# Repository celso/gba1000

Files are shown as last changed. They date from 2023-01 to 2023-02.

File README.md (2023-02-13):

# Amiga GBA1000 Project

The GB A1000 is a motherboard based on the Amiga 1000. The project was developed by Georg Braun and has the following features (Rev 4):

* CPU: Motorola MC68030 at 40 or 50 MHz
* FPU: Motorola MC68881 or MC68882 at CPU-speed
* RAM: 8 Mbyte 32-bit SRAM, 2 Mbyte ChipRAM
* Chipset: ECS Amiga (ECS-Denise 8373 and Fat Agnus 8372/8375)
* Built-in flicker-fixer with VGA-output
* One Zorro-II slot
* 1 Mbyte Flash-ROM for optional software
* Real-time clock with battery backup
* IDE-controller
* Two Kickstart-sockets
* Fits directly into an original Amiga 1000 case

We only have info and files for Rev 4.

Rev 5 adds a 68040 / 68060 CPU at 50MHz but there are no public schematics for it.

I will attempt to build a GBA1000 this year, this repo will host all the information and research work needed.

## PCB

* [Amiga EagleCAD library](https://gitlab.com/MHeinrichs/Amiga-EagleCAD-library)

## Parts

* [Parts list](https://docs.google.com/spreadsheets/d/1qbaFgtlkgim4g9IzhCKldIigHErPgWEHpMMWoZS-UCM/edit?usp=sharing) (spreadsheet)
* [Parts list (another version)](https://docs.google.com/spreadsheets/d/1GhOfJKkPUn_pJ6D0nmGipUzV8q_jXX78GFDTTUAWveM/edit?usp=sharing) (spreadsheet)

## Photos

* [Illuwatar's photos](https://photos.app.goo.gl/Ms466hcZpjMAoojf7)

## Videos

* [GBA1000 board build](https://www.youtube.com/watch?v=4canKrEQRAU) with great soldering tips

## Sections

* [FAQ](FAQ.md) from the old gba1000.info website.
* [Schematics](schematics/)
* [Assembly Drawings](assembly-drawings/)
* [Rev0 Instructions and BOM](instructions-rev0/)
* [Rev4 Eagle files](eagle-rev4/)
* [Hardware configuration files](logic/)

### Main threads

* [GBA1000 rev4 Build Log](https://www.amibay.com/threads/gba1000-rev4-build-log.46916/)
* [Project of a mini tylacine PCBs batch for the GBA1000](https://www.amibay.com/threads/project-of-a-mini-tylacine-pcbs-batch-for-the-gba1000.63034/)

### Relevant links

* [Rev4 PCB locator AmigaWiki](http://www.amigawiki.org/loc7/locator7.php)
* [Illuwatar's  A1000 build project](http://www.illuwatar.se/project_pages/gba1000/gba1000.htm)
* [GBA1000 v4 build in French](http://obligement.free.fr/articles/gba1000v4.php)
* [www.gba1000.info (archived)](https://web.archive.org/web/20090430084403/http://www.gba1000.info/disclaimer.asp?returnpage=partslist.asp)
* [GBA1000 Jumpers](http://www.amigawiki.de/lib/exe/fetch.php?media=de:models:gba1000_jumper.pdf)

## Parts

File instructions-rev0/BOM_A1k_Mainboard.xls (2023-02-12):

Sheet: A1k_Mainboard
EAGLE | Version 3.55r3 | 1988-1999 | CadSoft
Partliste
Part | Value | Package | Library | Distributor | Best.-Nr. | Preis Euro
BAT1 | LI-3V6 | LI-3V6 | BATTERY | elpro - Elektronik | LS 14250 Drahtanschluss | 4.87
C1 | 47uF | 7243 | SMD | elpro - Elektronik | T-SMD 20V 47uF BF:D | 0.34
C2 | 47uF | 7243 | SMD | elpro - Elektronik | T-SMD 20V 47uF BF:D | 0.34
C3 | 100nF | 1206 | SMD | elpro - Elektronik | K-SMD 0,1uF 1206 | 0.11
C4 | 100nF | 1206 | SMD | elpro - Elektronik | K-SMD 0,1uF 1206 | 0.11
C5 | 100nF | 1206 | SMD | elpro - Elektronik | K-SMD 0,1uF 1206 | 0.11
C6 | 100nF | 1206 | SMD | elpro - Elektronik | K-SMD 0,1uF 1206 | 0.11
C7 | 100nF | 1206 | SMD | elpro - Elektronik | K-SMD 0,1uF 1206 | 0.11
C8 | 100nF | 1206 | SMD | elpro - Elektronik | K-SMD 0,1uF 1206 | 0.11
C9 | 100nF | 1206 | SMD | elpro - Elektronik | K-SMD 0,1uF 1206 | 0.11
C10 | 100nF | 1206 | SMD | elpro - Elektronik | K-SMD 0,1uF 1206 | 0.11
C11 | 100nF | 1206 | SMD | elpro - Elektronik | K-SMD 0,1uF 1206 | 0.11
C12 | 100nF | 1206 | SMD | elpro - Elektronik | K-SMD 0,1uF 1206 | 0.11
C13 | 100nF | 1206 | SMD | elpro - Elektronik | K-SMD 0,1uF 1206 | 0.11
C14 | 100nF | 1206 | SMD | elpro - Elektronik | K-SMD 0,1uF 1206 | 0.11
C15 | 100nF | 1206 | SMD | elpro - Elektronik | K-SMD 0,1uF 1206 | 0.11
C16 | 100nF | 1206 | SMD | elpro - Elektronik | K-SMD 0,1uF 1206 | 0.11
C17 | 100nF | 1206 | SMD | elpro - Elektronik | K-SMD 0,1uF 1206 | 0.11
C18 | 100uF | 7243 | SMD | elpro - Elektronik | T-SMD 16V 100uF BF:D | 0.22
C19 | 47uF | 7243 | SMD | elpro - Elektronik | T-SMD 20V 47uF BF:D | 0.34
C20 | 100uF | 7243 | SMD | elpro - Elektronik | T-SMD 16V 100uF BF:D | 0.22
C21 | 100nF | 1206 | SMD | elpro - Elektronik | K-SMD 0,1uF 1206 | 0.11
C22 | 100nF | 1206 | SMD | elpro - Elektronik | K-SMD 0,1uF 1206 | 0.11
C23 | 100nF | 1206 | SMD | elpro - Elektronik | K-SMD 0,1uF 1206 | 0.11
C24 | 100nF | 1206 | SMD | elpro - Elektronik | K-SMD 0,1uF 1206 | 0.11
C25 | 100nF | 1206 | SMD | elpro - Elektronik | K-SMD 0,1uF 1206 | 0.11
C26 | 100nF | 1206 | SMD | elpro - Elektronik | K-SMD 0,1uF 1206 | 0.11
C27 | 100nF | 1206 | SMD | elpro - Elektronik | K-SMD 0,1uF 1206 | 0.11
C28 | 100nF | 1206 | SMD | elpro - Elektronik | K-SMD 0,1uF 1206 | 0.11
C29 | 100nF | 1206 | SMD | elpro - Elektronik | K-SMD 0,1uF 1206 | 0.11
C30 | 100nF | 1206 | SMD | elpro - Elektronik | K-SMD 0,1uF 1206 | 0.11
C31 | 100nF | 1206 | SMD | elpro - Elektronik | K-SMD 0,1uF 1206 | 0.11
C32 | 100nF | 1206 | SMD | elpro - Elektronik | K-SMD 0,1uF 1206 | 0.11
C33 | 100nF | 1206 | SMD | elpro - Elektronik | K-SMD 0,1uF 1206 | 0.11
C34 | 100nF | 1206 | SMD | elpro - Elektronik | K-SMD 0,1uF 1206 | 0.11
C35 | 100nF | 1206 | SMD | elpro - Elektronik | K-SMD 0,1uF 1206 | 0.11
C36 | 100pF | 1206 | SMD | elpro - Elektronik | K-SMD 100 pF 1206 | 0.11
C37 | 100pF | 1206 | SMD | elpro - Elektronik | K-SMD 100 pF 1206 | 0.11
C38 | 100pF | 1206 | SMD | elpro - Elektronik | K-SMD 100 pF 1206 | 0.11
C39 | 100pF | 1206 | SMD | elpro - Elektronik | K-SMD 100 pF 1206 | 0.11
C40 | 100pF | 1206 | SMD | elpro - Elektronik | K-SMD 100 pF 1206 | 0.11
C41 | 100pF | 1206 | SMD | elpro - Elektronik | K-SMD 100 pF 1206 | 0.11
C42 | 220uF | 7243 | SMD | elpro - Elektronik | T-SMD 6,3V 220uF BF:D | 0.45
C43 | 220uF | 7243 | SMD | elpro - Elektronik | T-SMD 6,3V 220uF BF:D | 0.45
C44 | 1uF | 1206 | SMD | elpro - Elektronik | K-SMD 1uF 1206 | 0.12
C45 | 220uF | 7243 | SMD | elpro - Elektronik | T-SMD 6,3V 220uF BF:D | 0.45
C46 | 220uF | 7243 | SMD | elpro - Elektronik | T-SMD 6,3V 220uF BF:D | 0.45
C47 | 1uF | 1206 | SMD | elpro - Elektronik | K-SMD 1uF 1206 | 0.12
C48 | 1nF | 1206 | SMD | elpro - Elektronik | K-SMD 1000 pF 1206 | 0.11
C49 | 1nF | 1206 | SMD | elpro - Elektronik | K-SMD 1000 pF 1206 | 0.11
C50 | 100nF | 1206 | SMD | elpro - Elektronik | K-SMD 0,1uF 1206 | 0.11
C51 | 39pF | 1206 | SMD | elpro - Elektronik | K-SMD 39 pF 1206 | 0.11
C52 | 100nF | 1206 | SMD | elpro - Elektronik | K-SMD 0,1uF 1206 | 0.11
C53 | 100nF | 1206 | SMD | elpro - Elektronik | K-SMD 0,1uF 1206 | 0.11
C54 | 100nF | 1206 | SMD | elpro - Elektronik | K-SMD 0,1uF 1206 | 0.11
C55 | 10uF | 7243 | SMD | elpro - Elektronik | T-SMD 25V 10uF BF:D | 0.24
C56 | 100pF | 1206 | SMD | elpro - Elektronik | K-SMD 100 pF 1206 | 0.11
C57 | 100pF | 1206 | SMD | elpro - Elektronik | K-SMD 100 pF 1206 | 0.11
C58 | 100pF | 1206 | SMD | elpro - Elektronik | K-SMD 100 pF 1206 | 0.11
C59 | 1-5pF | C-TRIM-1 | RCD | elpro - Elektronik | 808-1 1,4-5,5 pF | 0.36
C60 | 100nF | 1206 | SMD | elpro - Elektronik | K-SMD 0,1uF 1206 | 0.11
C61 | 100nF | 1206 | SMD | elpro - Elektronik | K-SMD 0,1uF 1206 | 0.11
C62 | 100nF | 1206 | SMD | elpro - Elektronik | K-SMD 0,1uF 1206 | 0.11
C63 | 100nF | 1206 | SMD | elpro - Elektronik | K-SMD 0,1uF 1206 | 0.11
C64 | 100nF | 1206 | SMD | elpro - Elektronik | K-SMD 0,1uF 1206 | 0.11
C65 | 100nF | 1206 | SMD | elpro - Elektronik | K-SMD 0,1uF 1206 | 0.11
C66 | 100nF | 1206 | SMD | elpro - Elektronik | K-SMD 0,1uF 1206 | 0.11
C67 | 100nF | 1206 | SMD | elpro - Elektronik | K-SMD 0,1uF 1206 | 0.11
C68 | 100nF | 1206 | SMD | elpro - Elektronik | K-SMD 0,1uF 1206 | 0.11
C69 | 100nF | 1206 | SMD | elpro - Elektronik | K-SMD 0,1uF 1206 | 0.11
C70 | 100nF | 1206 | SMD | elpro - Elektronik | K-SMD 0,1uF 1206 | 0.11
C71 | 100nF | 1206 | SMD | elpro - Elektronik | K-SMD 0,1uF 1206 | 0.11
C72 | 100nF | 1206 | SMD | elpro - Elektronik | K-SMD 0,1uF 1206 | 0.11
C73 | 100nF | 1206 | SMD | elpro - Elektronik | K-SMD 0,1uF 1206 | 0.11
C74 | 47uF | 7243 | SMD | elpro - Elektronik | T-SMD 20V 47uF BF:D | 0.34
C75 | 7,5pF | 1206 | SMD | elpro - Elektronik | K-SMD 8,2 pF 1206 | 0.11
C76 | 47uF | 7243 | SMD | elpro - Elektronik | T-SMD 20V 47uF BF:D | 0.34
C77 | 10uF | 7243 | SMD | elpro - Elektronik | T-SMD 25V 10uF BF:D | 0.24
C78 | 100nF | 1206 | SMD | elpro - Elektronik | K-SMD 0,1uF 1206 | 0.11
C79 | 20pF | 1206 | SMD | elpro - Elektronik | K-SMD 22 pF 1206 | 0.11
C80 | 5-40pF | C-TRIM-1 | RCD | elpro - Elektronik | 808-1 3-40 pF | 0.40
C81 | 6,8nF | 1206 | SMD | elpro - Elektronik | K-SMD 6800 pF 1206 | 0.11
C82 | 3,9nF | 1206 | SMD | elpro - Elektronik | K-SMD 3900 pF 1206 | 0.11
C83 | 10uF | 1812 | SMD | Mira-Electronic | 8261/106 | 1.12 | Segor 22u-1210-X5R/10V
C84 | 100nF | 1206 | SMD | elpro - Elektronik | K-SMD 0,1uF 1206 | 0.11
C85 | 6,8nF | 1206 | SMD | elpro - Elektronik | K-SMD 6800 pF 1206 | 0.11
C86 | 10uF | 1812 | SMD | Mira-Electronic | 8261/106 | 1.12 | Segor 22u-1210-X5R/10V
C87 | 3,9nF | 1206 | SMD | elpro - Elektronik | K-SMD 3900 pF 1206 | 0.11
C88 | 100nF | 1206 | SMD | elpro - Elektronik | K-SMD 0,1uF 1206 | 0.11
C89 | 10uF | 7243 | SMD | elpro - Elektronik | T-SMD 25V 10uF BF:D | 0.24
C90 | 47nF | 1206 | SMD | elpro - Elektronik | K-SMD 0,047uF 1206 | 0.11
C91 | 47nF | 1206 | SMD | elpro - Elektronik | K-SMD 0,047uF 1206 | 0.11
C92 | 47nF | 1206 | SMD | elpro - Elektronik | K-SMD 0,047uF 1206 | 0.11
C93 | 47nF | 1206 | SMD | elpro - Elektronik | K-SMD 0,047uF 1206 | 0.11
C94 | 22uF | 7243 | SMD | elpro - Elektronik | T-SMD 25V 22uF BF:D | 0.30
C95 | 22uF | 7243 | SMD | elpro - Elektronik | T-SMD 25V 22uF BF:D | 0.30
C96 | 100nF | 1206 | SMD | elpro - Elektronik | K-SMD 0,1uF 1206 | 0.11
C97 | 100nF | 1206 | SMD | elpro - Elektronik | K-SMD 0,1uF 1206 | 0.11
C98 | 10nF | 1206 | SMD | elpro - Elektronik | K-SMD 0,01uF 1206 | 0.11
C99 | 100nF | 1206 | SMD | elpro - Elektronik | K-SMD 0,1uF 1206 | 0.11
C100 | 100pF | 1206 | SMD | elpro - Elektronik | K-SMD 100 pF 1206 | 0.11
C101 | 100pF | 1206 | SMD | elpro - Elektronik | K-SMD 100 pF 1206 | 0.11
C102 | 100pF | 1206 | SMD | elpro - Elektronik | K-SMD 100 pF 1206 | 0.11
C103 | 100nF | 1206 | SMD | elpro - Elektronik | K-SMD 0,1uF 1206 | 0.11
C104 | 10uF | 7243 | SMD | elpro - Elektronik | T-SMD 25V 10uF BF:D | 0.24
C105 | 10uF | 7243 | SMD | elpro - Elektronik | T-SMD 25V 10uF BF:D | 0.24
C106 | 100nF | 1206 | SMD | elpro - Elektronik | K-SMD 0,1uF 1206 | 0.11
C107 | 100nF | 1206 | SMD | elpro - Elektronik | K-SMD 0,1uF 1206 | 0.11
C108 | 100nF | 1206 | SMD | elpro - Elektronik | K-SMD 0,1uF 1206 | 0.11
C109 | 100nF | 1206 | SMD | elpro - Elektronik | K-SMD 0,1uF 1206 | 0.11
C110 | 100nF | 1206 | SMD | elpro - Elektronik | K-SMD 0,1uF 1206 | 0.11
C111 | 100nF | 1206 | SMD | elpro - Elektronik | K-SMD 0,1uF 1206 | 0.11
C112 | 100nF | 1206 | SMD | elpro - Elektronik | K-SMD 0,1uF 1206 | 0.11
C113 | 47uF | 7243 | SMD | elpro - Elektronik | T-SMD 20V 47uF BF:D | 0.34
C114 | 47uF | 7243 | SMD | elpro - Elektronik | T-SMD 20V 47uF BF:D | 0.34
C115 | 100nF | 1206 | SMD | elpro - Elektronik | K-SMD 0,1uF 1206 | 0.11
C116 | 100nF | 1206 | SMD | elpro - Elektronik | K-SMD 0,1uF 1206 | 0.11
C117 | 100nF | 1206 | SMD | elpro - Elektronik | K-SMD 0,1uF 1206 | 0.11
C118 | 100nF | 1206 | SMD | elpro - Elektronik | K-SMD 0,1uF 1206 | 0.11
C119 | 100nF | 1206 | SMD | elpro - Elektronik | K-SMD 0,1uF 1206 | 0.11
C120 | 100nF | 1206 | SMD | elpro - Elektronik | K-SMD 0,1uF 1206 | 0.11
C121 | 100nF | 1206 | SMD | elpro - Elektronik | K-SMD 0,1uF 1206 | 0.11
C122 | 100nF | 1206 | SMD | elpro - Elektronik | K-SMD 0,1uF 1206 | 0.11
C123 | 100nF | 1206 | SMD | elpro - Elektronik | K-SMD 0,1uF 1206 | 0.11
C124 | 47uF | 7243 | SMD | elpro - Elektronik | T-SMD 20V 47uF BF:D | 0.34
C125 | 100nF | 1206 | SMD | elpro - Elektronik | K-SMD 0,1uF 1206 | 0.11
C126 | 100nF | 1206 | SMD | elpro - Elektronik | K-SMD 0,1uF 1206 | 0.11
C127 | 100nF | 1206 | SMD | elpro - Elektronik | K-SMD 0,1uF 1206 | 0.11
C128 | 100nF | 1206 | SMD | elpro - Elektronik | K-SMD 0,1uF 1206 | 0.11
C129 | 47uF | 7243 | SMD | elpro - Elektronik | T-SMD 20V 47uF BF:D | 0.34
C130 | 100nF | 1206 | SMD | elpro - Elektronik | K-SMD 0,1uF 1206 | 0.11
C131 | 100nF | 1206 | SMD | elpro - Elektronik | K-SMD 0,1uF 1206 | 0.11
C132 | 100nF | 1206 | SMD | elpro - Elektronik | K-SMD 0,1uF 1206 | 0.11
C133 | 100nF | 1206 | SMD | elpro - Elektronik | K-SMD 0,1uF 1206 | 0.11
C134 | 100nF | 1206 | SMD | elpro - Elektronik | K-SMD 0,1uF 1206 | 0.11
C135 | 100nF | 1206 | SMD | elpro - Elektronik | K-SMD 0,1uF 1206 | 0.11
C136 | 100nF | 1206 | SMD | elpro - Elektronik | K-SMD 0,1uF 1206 | 0.11
C137 | 100nF | 1206 | SMD | elpro - Elektronik | K-SMD 0,1uF 1206 | 0.11
C138 | 100nF | 1206 | SMD | elpro - Elektronik | K-SMD 0,1uF 1206 | 0.11
C139 | 100nF | 1206 | SMD | elpro - Elektronik | K-SMD 0,1uF 1206 | 0.11
C140 | 100nF | 1206 | SMD | elpro - Elektronik | K-SMD 0,1uF 1206 | 0.11
C141 | 100nF | 1206 | SMD | elpro - Elektronik | K-SMD 0,1uF 1206 | 0.11
C142 | 100nF | 1206 | SMD | elpro - Elektronik | K-SMD 0,1uF 1206 | 0.11
C143 | 100nF | 1206 | SMD | elpro - Elektronik | K-SMD 0,1uF 1206 | 0.11
C144 | 100nF | 1206 | SMD | elpro - Elektronik | K-SMD 0,1uF 1206 | 0.11
C145 | 100nF | 1206 | SMD | elpro - Elektronik | K-SMD 0,1uF 1206 | 0.11
C146 | 100nF | 1206 | SMD | elpro - Elektronik | K-SMD 0,1uF 1206 | 0.11
C147 | 100nF | 1206 | SMD | elpro - Elektronik | K-SMD 0,1uF 1206 | 0.11
C148 | 100nF | 1206 | SMD | elpro - Elektronik | K-SMD 0,1uF 1206 | 0.11
C149 | 100nF | 1206 | SMD | elpro - Elektronik | K-SMD 0,1uF 1206 | 0.11
C150 | 100nF | 1206 | SMD | elpro - Elektronik | K-SMD 0,1uF 1206 | 0.11
C151 | 100nF | 1206 | SMD | elpro - Elektronik | K-SMD 0,1uF 1206 | 0.11
C152 | 100nF | 1206 | SMD | elpro - Elektronik | K-SMD 0,1uF 1206 | 0.11
C153 | 100nF | 1206 | SMD | elpro - Elektronik | K-SMD 0,1uF 1206 | 0.11
C154 | 100nF | 1206 | SMD | elpro - Elektronik | K-SMD 0,1uF 1206 | 0.11
C155 | 100nF | 1206 | SMD | elpro - Elektronik | K-SMD 0,1uF 1206 | 0.11
C156 | 100nF | 1206 | SMD | elpro - Elektronik | K-SMD 0,1uF 1206 | 0.11
C157 | 100nF | 1206 | SMD | elpro - Elektronik | K-SMD 0,1uF 1206 | 0.11
C158 | 100nF | 1206 | SMD | elpro - Elektronik | K-SMD 0,1uF 1206 | 0.11
C159 | 100nF | 1206 | SMD | elpro - Elektronik | K-SMD 0,1uF 1206 | 0.11
C160 | 100nF | 1206 | SMD | elpro - Elektronik | K-SMD 0,1uF 1206 | 0.11
C161 | 47uF | 7243 | SMD | elpro - Elektronik | T-SMD 20V 47uF BF:D | 0.34
C162 | 47uF | 7243 | SMD | elpro - Elektronik | T-SMD 20V 47uF BF:D | 0.34
C163 | 47uF | 7243 | SMD | elpro - Elektronik | T-SMD 20V 47uF BF:D | 0.34
C164 | 4,7uF | 3528 | SMD | elpro - Elektronik | T-SMD 16V 4,7uF BF:B | 0.15
D1 | BAS32L | SOD-80 | SMD | elpro - Elektronik | BAS32 L SMD | 0.09
D2 | BAS32L | SOD-80 | SMD | elpro - Elektronik | BAS32 L SMD | 0.09
D3 | BAS32L | SOD-80 | SMD | elpro - Elektronik | BAS32 L SMD | 0.09
IC1 | 74HC573 | DIP20 | DIL-IC | elpro - Elektronik | 74 HC 573 | 0.15
IC2 | 74HC573 | DIP20 | DIL-IC | elpro - Elektronik | 74 HC 573 | 0.15
IC3 | 74HC541 | DIP20 | DIL-IC | elpro - Elektronik | 74 HC 541 | 0.19
IC4 | 74HC541 | DIP20 | DIL-IC | elpro - Elektronik | 74 HC 541 | 0.19
IC5 | 74HC541 | DIP20 | DIL-IC | elpro - Elektronik | 74 HC 541 | 0.19
IC6 | 74HC541 | DIP20 | DIL-IC | elpro - Elektronik | 74 HC 541 | 0.19
IC7 | 514400 | SOJ26/20 | SMD-IC | Kessler electronic | 514400-60SOJ | 4.98
IC8 | 514400 | SOJ26/20 | SMD-IC | Kessler electronic | 514400-60SOJ | 4.98
IC9 | 514400 | SOJ26/20 | SMD-IC | Kessler electronic | 514400-60SOJ | 4.98
IC10 | 514400 | SOJ26/20 | SMD-IC | Kessler electronic | 514400-60SOJ | 4.98
IC11 | 28,3751 MHz | Oszillator | DIL-IC | Amiga-Hardware |  | 0.00
IC12 | 27C400 | DIP40-6 | DIL-IC | Kickstart-ROM |  | 0.00
IC13 | 27C4096 | DIP40-6 | DIL-IC | n.b. |  | 0.00
IC14 | GAL16V8-15 | DIP20 | DIL-IC | elpro - Elektronik | GAL 16 V 8 D-15 LP | 0.70
IC15 | 74LS373 | DIP20 | DIL-IC | Reichelt - Elektronik | 74LS 373 | 0.22
IC16 | 74F521 | DIP20 | DIL-IC | Reichelt - Elektronik | 74F 521 | 0.40
IC17 | 74LS245 | DIP20 | DIL-IC | Reichelt - Elektronik | 74LS 245 | 0.20
IC18 | GAL16V8-15 | DIP20 | DIL-IC | elpro - Elektronik | GAL 16 V 8 D-15 LP | 0.70
IC19 | GAL16V8-25 | DIP20 | DIL-IC | elpro - Elektronik | GAL 16 V 8 D-25 LP | 0.70
IC20 | AMBER | PLCC68 | DIL-IC | Amiga-Hardware |  | 0.00
IC21 | VIDEO_H | SIP22 | DIL-IC | Amiga-Hardware |  | 0.00
IC22 | 74HC157 | DIP16 | DIL-IC | Reichelt - Elektronik | 74HC 157 | 0.15
IC23 | 74HC245 | DIP20 | DIL-IC | Reichelt - Elektronik | 74HC 245 | 0.20
IC24 | 74HC245 | DIP20 | DIL-IC | Reichelt - Elektronik | 74HC 245 | 0.20
IC25 | VIDEO_H | SIP22 | DIL-IC | Amiga-Hardware |  | 0.00
IC26 | DENISE | DIP48-6 | DIL-IC | Amiga-Hardware |  | 0.00
IC27 | NE564 | DIP16 | DIL-IC | Reichelt - Elektronik | NE 564 DIL | 1.50
IC28 | 74HC04 | DIP14 | 74XXSMD | Reichelt - Elektronik | 74HC 04 | 0.12
IC29 | 74F163 | DIP16 | 74XX | Kessler electronic | 74F163 | 0.84
IC30 | 74F74 | DIP14 | 74XX | Reichelt - Elektronik | 74F 74 | 0.31
IC31 | GAL16V8-25 | DIP20 | DIL-IC | elpro - Elektronik | GAL 16 V 8 D-25 LP | 0.70
IC32 | GAL16V8-25 | DIP20 | DIL-IC | elpro - Elektronik | GAL 16 V 8 D-25 LP | 0.70
IC33 | GAL16V8-15 | DIP20 | DIL-IC | elpro - Elektronik | GAL 16 V 8 D-15 LP | 0.70
IC34 | 27C256 | DIP28-6 | DIL-IC | Reichelt - Elektronik | 27C256-70 | 2.05
IC35 | 74LS245 | DIP20 | DIL-IC | Reichelt - Elektronik | 74LS 245 | 0.20
IC36 | 74LS245 | DIP20 | DIL-IC | Reichelt - Elektronik | 74LS 245 | 0.20
IC37 | MC68030RC | PGA-128 | M68000 | eBay |  | 20.00
IC38 | MC68881RC | PGA-68 | M68000 | eBay |  | 20.00
IC39 | MSM6242 | DIP18 | DIL-IC | Amiga-Hardware |  | 0.00
IC40 | CIA_8520 | DIP40-6 | DIL-IC | Amiga-Hardware |  | 0.00
IC41 | PAULA | DIP48-6 | DIL-IC | Amiga-Hardware |  | 0.00
IC42 | TL084 | DIP14 | DIL-IC | Reichelt - Elektronik | TL 074 DIL | 0.15
IC43 | CIA_8520 | DIP40-6 | DIL-IC | Amiga-Hardware |  | 0.00
IC44 | DS1488 | DIP14 | DIL-IC | Kessler electronic | MC1488 | 0.25
IC45 | DS1489 | DIP14 | DIL-IC | Kessler electronic | MC1489 | 0.19
IC46 | 74HC32 | DIP14 | DIL-IC | Reichelt - Elektronik | 74HC 32 | 0.15
IC47 | 7406 | DIP14 | DIL-IC | Reichelt - Elektronik | 74LS 06 | 0.39
IC48 | LM339 | DIP14 | DIL-IC | Reichelt - Elektronik | LM 339 DIL | 0.10
IC49 | 7407 | DIP14 | DIL-IC | Reichelt - Elektronik | 74LS 07 | 0.17
IC50 | GARY | DIP48-6 | DIL-IC | Amiga-Hardware |  | 0.00
IC51 | 74F04 | DIP14 | DIL-IC | Reichelt - Elektronik | 74F 04 | 0.22
IC52 | AGNUS | PLCC84 | DIL-IC | Amiga-Hardware |  | 0.00
IC53 | GAL20V8-15 | DIP24-3 | DIL-IC | elpro - Elektronik | GAL 20 V 8 B-15 LP | 0.93
IC54 | GAL20V8-15 | DIP24-3 | DIL-IC | elpro - Elektronik | GAL 20 V 8 B-15 LP | 0.93
IC55 | GAL20V8-15 | DIP24-3 | DIL-IC | elpro - Elektronik | GAL 20 V 8 B-15 LP | 0.93
IC56 | GAL20V8-15 | DIP24-3 | DIL-IC | elpro - Elektronik | GAL 20 V 8 B-15 LP | 0.93
IC57 | LSI1024 | PLCC68 | DIL-IC | elpro - Elektronik | ISPLSI 1024-60 LJ PLCC | 10.85
IC58 | 74F245 | SO20L | 74XXSMD | elpro - Elektronik | 74 F 245 SMD | 0.40
IC59 | 74F245 | SO20L | 74XXSMD | elpro - Elektronik | 74 F 245 SMD | 0.40
IC60 | 29F800 | TSOP48 | SMD-IC | RS Components GmbH | 414-9597 | 11.80
IC61 | 48 MHz | Oszillator | DIL-IC | Conrad Elektronik | 158240 | 5.22
IC62 | CY7C1049 | SOJ36/4 | SMD-IC | Kessler electronic | 614008-10J | 3.80
IC63 | CY7C1049 | SOJ36/4 | SMD-IC | Kessler electronic | 614008-10J | 3.80
IC64 | CY7C1049 | SOJ36/4 | SMD-IC | Kessler electronic | 614008-10J | 3.80
IC65 | CY7C1049 | SOJ36/4 | SMD-IC | Kessler electronic | 614008-10J | 3.80
IC66 | CY7C1049 | SOJ36/4 | SMD-IC | Kessler electronic | 614008-10J | 3.80
IC67 | CY7C1049 | SOJ36/4 | SMD-IC | Kessler electronic | 614008-10J | 3.80
IC68 | CY7C1049 | SOJ36/4 | SMD-IC | Kessler electronic | 614008-10J | 3.80
IC69 | CY7C1049 | SOJ36/4 | SMD-IC | Kessler electronic | 614008-10J | 3.80
IC70 | CY7C1049 | SOJ36/4 | SMD-IC | Kessler electronic | 614008-10J | 3.80
IC71 | CY7C1049 | SOJ36/4 | SMD-IC | Kessler electronic | 614008-10J | 3.80
IC72 | CY7C1049 | SOJ36/4 | SMD-IC | Kessler electronic | 614008-10J | 3.80
IC73 | CY7C1049 | SOJ36/4 | SMD-IC | Kessler electronic | 614008-10J | 3.80
IC74 | CY7C1049 | SOJ36/4 | SMD-IC | Kessler electronic | 614008-10J | 3.80
IC75 | CY7C1049 | SOJ36/4 | SMD-IC | Kessler electronic | 614008-10J | 3.80
IC76 | CY7C1049 | SOJ36/4 | SMD-IC | Kessler electronic | 614008-10J | 3.80
IC77 | CY7C1049 | SOJ36/4 | SMD-IC | Kessler electronic | 614008-10J | 3.80
IC79 | 74HC05 | DIP14 | DIL-IC | elpro - Elektronik | 74HC 05 | 0.44
L1 | 150 OHM | 1206 | SMD | Würth Elektronik GmbH | 74279212 | 0.05
L2 | 150 OHM | 1206 | SMD | Würth Elektronik GmbH | 74279212 | 0.05
L3 | 150 OHM | 1206 | SMD | Würth Elektronik GmbH | 74279212 | 0.05
L4 | 150 OHM | 1206 | SMD | Würth Elektronik GmbH | 74279212 | 0.05
L5 | 150 OHM | 1206 | SMD | Würth Elektronik GmbH | 74279212 | 0.05
L6 | 150 OHM | 1206 | SMD | Würth Elektronik GmbH | 74279212 | 0.05
L7 | 150 OHM | 1206 | SMD | Würth Elektronik GmbH | 74279212 | 0.05
L8 | 150 OHM | 1206 | SMD | Würth Elektronik GmbH | 74279212 | 0.05
L9 | 150 OHM | 1206 | SMD | Würth Elektronik GmbH | 74279212 | 0.05
L10 | 150 OHM | 1206 | SMD | Würth Elektronik GmbH | 74279212 | 0.05
L11 | 150 OHM | 1206 | SMD | Würth Elektronik GmbH | 74279212 | 0.05
L12 | 150 OHM | 1206 | SMD | Würth Elektronik GmbH | 74279212 | 0.05
L13 | 150 OHM | 1206 | SMD | Würth Elektronik GmbH | 74279212 | 0.05
L14 | 150 OHM | 1206 | SMD | Würth Elektronik GmbH | 74279212 | 0.05
L15 | 150 OHM | 1206 | SMD | Würth Elektronik GmbH | 74279212 | 0.05
L16 | 150 OHM | 1206 | SMD | Würth Elektronik GmbH | 74279212 | 0.05
L17 | 48 OHM/6A | 1206 | SMD | Würth Elektronik GmbH | 742792117 | 0.05
L18 | 48 OHM/6A | 1206 | SMD | Würth Elektronik GmbH | 742792117 | 0.05
L19 | 48 OHM/6A | 1206 | SMD | Würth Elektronik GmbH | 742792117 | 0.05
L20 | 150 OHM | 1206 | SMD | Würth Elektronik GmbH | 74279212 | 0.05
L21 | 150 OHM | 1206 | SMD | Würth Elektronik GmbH | 74279212 | 0.05
L22 | 150 OHM | 1206 | SMD | Würth Elektronik GmbH | 74279212 | 0.05
L23 | 150 OHM | 1206 | SMD | Würth Elektronik GmbH | 74279212 | 0.05
L24 | 10UH | L-10UH | SMD | elpro - Elektronik | LQH 4 N 10 uH | 0.40
L25 | 48 OHM/6A | 1206 | SMD | Würth Elektronik GmbH | 742792117 | 0.05
L26 | 10uH | L-10UH | SMD | elpro - Elektronik | LQH 4 N 10 uH | 0.40
L27 | 150 OHM | 1206 | SMD | Würth Elektronik GmbH | 74279212 | 0.05
L28 | 150 OHM | 1206 | SMD | Würth Elektronik GmbH | 74279212 | 0.05
L29 | 150 OHM | 1206 | SMD | Würth Elektronik GmbH | 74279212 | 0.05
L30 | 150 OHM | 1206 | SMD | Würth Elektronik GmbH | 74279212 | 0.05
L31 | 150 OHM | 1206 | SMD | Würth Elektronik GmbH | 74279212 | 0.05
L32 | 48 OHM/6A | 1206 | SMD | Würth Elektronik GmbH | 742792117 | 0.05
L33 | 150 OHM | 1206 | SMD | Würth Elektronik GmbH | 74279212 | 0.05
L34 | 150 OHM | 1206 | SMD | Würth Elektronik GmbH | 74279212 | 0.05
L35 | 150 OHM | 1206 | SMD | Würth Elektronik GmbH | 74279212 | 0.05
L36 | 150 OHM | 1206 | SMD | Würth Elektronik GmbH | 74279212 | 0.05
L37 | 48 OHM/6A | 1206 | SMD | Würth Elektronik GmbH | 742792117 | 0.05
L38 | 150 OHM | 1206 | SMD | Würth Elektronik GmbH | 74279212 | 0.05
L39 | 150 OHM | 1206 | SMD | Würth Elektronik GmbH | 74279212 | 0.05
L40 | 150 OHM | 1206 | SMD | Würth Elektronik GmbH | 74279212 | 0.05
L41 | 150 OHM | 1206 | SMD | Würth Elektronik GmbH | 74279212 | 0.05
L42 | 150 OHM | 1206 | SMD | Würth Elektronik GmbH | 74279212 | 0.05
L43 | 48 OHM/6A | 1206 | SMD | Würth Elektronik GmbH | 742792117 | 0.05
L44 | 150 OHM | 1206 | SMD | Würth Elektronik GmbH | 74279212 | 0.05
L45 | 150 OHM | 1206 | SMD | Würth Elektronik GmbH | 74279212 | 0.05
L46 | 150 OHM | 1206 | SMD | Würth Elektronik GmbH | 74279212 | 0.05
L47 | 150 OHM | 1206 | SMD | Würth Elektronik GmbH | 74279212 | 0.05
L48 | 150 OHM | 1206 | SMD | Würth Elektronik GmbH | 74279212 | 0.05
L49 | 150 OHM | 1206 | SMD | Würth Elektronik GmbH | 74279212 | 0.05
L50 | 150 OHM | 1206 | SMD | Würth Elektronik GmbH | 74279212 | 0.05
L51 | 150 OHM | 1206 | SMD | Würth Elektronik GmbH | 74279212 | 0.05
L52 | 150 OHM | 1206 | SMD | Würth Elektronik GmbH | 74279212 | 0.05
L53 | 150 OHM | 1206 | SMD | Würth Elektronik GmbH | 74279212 | 0.05
L54 | 150 OHM | 1206 | SMD | Würth Elektronik GmbH | 74279212 | 0.05
L55 | 150 OHM | 1206 | SMD | Würth Elektronik GmbH | 74279212 | 0.05
L56 | 150 OHM | 1206 | SMD | Würth Elektronik GmbH | 74279212 | 0.05
L57 | 48 OHM/6A | 1206 | SMD | Würth Elektronik GmbH | 742792117 | 0.05
L58 | 150 OHM | 1206 | SMD | Würth Elektronik GmbH | 74279212 | 0.05
L59 | 150 OHM | 1206 | SMD | Würth Elektronik GmbH | 74279212 | 0.05
L60 | 150 OHM | 1206 | SMD | Würth Elektronik GmbH | 74279212 | 0.05
L61 | 150 OHM | 1206 | SMD | Würth Elektronik GmbH | 74279212 | 0.05
L62 | 150 OHM | 1206 | SMD | Würth Elektronik GmbH | 74279212 | 0.05
L63 | 150 OHM | 1206 | SMD | Würth Elektronik GmbH | 74279212 | 0.05
L64 | 48 OHM/6A | 1206 | SMD | Würth Elektronik GmbH | 742792117 | 0.05
L65 | 150 OHM | 1206 | SMD | Würth Elektronik GmbH | 74279212 | 0.05
L66 | 150 OHM | 1206 | SMD | Würth Elektronik GmbH | 74279212 | 0.05
L67 | 48 OHM/6A | 1206 | SMD | Würth Elektronik GmbH | 742792117 | 0.05
L68 | 48 OHM/6A | 1206 | SMD | Würth Elektronik GmbH | 742792117 | 0.05
L69 | 150 OHM | 1206 | SMD | Würth Elektronik GmbH | 74279212 | 0.05
L70 | 150 OHM | 1206 | SMD | Würth Elektronik GmbH | 74279212 | 0.05
L71 | 150 OHM | 1206 | SMD | Würth Elektronik GmbH | 74279212 | 0.05
L72 | 150 OHM | 1206 | SMD | Würth Elektronik GmbH | 74279212 | 0.05
L73 | 150 OHM | 1206 | SMD | Würth Elektronik GmbH | 74279212 | 0.05
L74 | 150 OHM | 1206 | SMD | Würth Elektronik GmbH | 74279212 | 0.05
L75 | 150 OHM | 1206 | SMD | Würth Elektronik GmbH | 74279212 | 0.05
L76 | 150 OHM | 1206 | SMD | Würth Elektronik GmbH | 74279212 | 0.05
L77 | 150 OHM | 1206 | SMD | Würth Elektronik GmbH | 74279212 | 0.05
L78 | 150 OHM | 1206 | SMD | Würth Elektronik GmbH | 74279212 | 0.05
L79 | 48 OHM/6A | 1206 | SMD | Würth Elektronik GmbH | 742792117 | 0.05
L80 | 150 OHM | 1206 | SMD | Würth Elektronik GmbH | 74279212 | 0.05
L81 | 150 OHM | 1206 | SMD | Würth Elektronik GmbH | 74279212 | 0.05
L82 | 150 OHM | 1206 | SMD | Würth Elektronik GmbH | 74279212 | 0.05
L83 | 150 OHM | 1206 | SMD | Würth Elektronik GmbH | 74279212 | 0.05
L84 | 150 OHM | 1206 | SMD | Würth Elektronik GmbH | 74279212 | 0.05
L85 | 150 OHM | 1206 | SMD | Würth Elektronik GmbH | 74279212 | 0.05
L86 | 150 OHM | 1206 | SMD | Würth Elektronik GmbH | 74279212 | 0.05
L87 | 150 OHM | 1206 | SMD | Würth Elektronik GmbH | 74279212 | 0.05
L88 | 150 OHM | 1206 | SMD | Würth Elektronik GmbH | 74279212 | 0.05
L89 | 150 OHM | 1206 | SMD | Würth Elektronik GmbH | 74279212 | 0.05
L90 | 48 OHM/6A | 1206 | SMD | Würth Elektronik GmbH | 742792117 | 0.05
L91 | 150 OHM | 1206 | SMD | Würth Elektronik GmbH | 74279212 | 0.05
L92 | 150 OHM | 1206 | SMD | Würth Elektronik GmbH | 74279212 | 0.05
L93 | 150 OHM | 1206 | SMD | Würth Elektronik GmbH | 74279212 | 0.05
L94 | 48 OHM/6A | 1206 | SMD | Würth Elektronik GmbH | 742792117 | 0.05
L95 | 48 OHM/6A | 1206 | SMD | Würth Elektronik GmbH | 742792117 | 0.05
L96 | 48 OHM/6A | 1206 | SMD | Würth Elektronik GmbH | 742792117 | 0.05
L97 | 48 OHM/6A | 1206 | SMD | Würth Elektronik GmbH | 742792117 | 0.05
L98 | 48 OHM/6A | 1206 | SMD | Würth Elektronik GmbH | 742792117 | 0.05
L99 | 48 OHM/6A | 1206 | SMD | Würth Elektronik GmbH | 742792117 | 0.05
L100 | 48 OHM/6A | 1206 | SMD | Würth Elektronik GmbH | 742792117 | 0.05
L101 | 48 OHM/6A | 1206 | SMD | Würth Elektronik GmbH | 742792117 | 0.05
L102 | 48 OHM/6A | 1206 | SMD | Würth Elektronik GmbH | 742792117 | 0.05
L103 | 48 OHM/6A | 1206 | SMD | Würth Elektronik GmbH | 742792117 | 0.05
Q1 | 32kHz | Q-UHR | DIL-IC | elpro - Elektronik | Q32,768 kHz TC 38 | 0.45
R1 | 22R | 204 | SMD | elpro - Elektronik | 1206-SMD 1% 22R | 0.15
R2 | 22R | 204 | SMD | elpro - Elektronik | 1206-SMD 1% 22R | 0.15
R3 | 22R | 204 | SMD | elpro - Elektronik | 1206-SMD 1% 22R | 0.15
R4 | 68R | 204 | SMD | elpro - Elektronik | 1206-SMD 1% 68R | 0.15
R5 | 4k7 | 204 | SMD | elpro - Elektronik | 1206-SMD 1% 4,7k | 0.15
R6 | 33R | 204 | SMD | elpro - Elektronik | 1206-SMD 1% 33R | 0.15
R7 | 68R | 204 | SMD | elpro - Elektronik | 1206-SMD 1% 68R | 0.15
R8 | 68R | 204 | SMD | elpro - Elektronik | 1206-SMD 1% 68R | 0.15
R9 | 68R | 204 | SMD | elpro - Elektronik | 1206-SMD 1% 68R | 0.15
R10 | 68R | 204 | SMD | elpro - Elektronik | 1206-SMD 1% 68R | 0.15
R11 | 68R | 204 | SMD | elpro - Elektronik | 1206-SMD 1% 68R | 0.15
R12 | 33R | 204 | SMD | elpro - Elektronik | 1206-SMD 1% 33R | 0.15
R13 | 68R | 204 | SMD | elpro - Elektronik | 1206-SMD 1% 68R | 0.15
R14 | 33R | 204 | SMD | elpro - Elektronik | 1206-SMD 1% 33R | 0.15
R15 | 68R | 204 | SMD | elpro - Elektronik | 1206-SMD 1% 68R | 0.15
R16 | 68R | 204 | SMD | elpro - Elektronik | 1206-SMD 1% 68R | 0.15
R17 | 33R | 204 | SMD | elpro - Elektronik | 1206-SMD 1% 33R | 0.15
R18 | 68R | 204 | SMD | elpro - Elektronik | 1206-SMD 1% 68R | 0.15
R19 | 33R | 204 | SMD | elpro - Elektronik | 1206-SMD 1% 33R | 0.15
R20 | 68R | 204 | SMD | elpro - Elektronik | 1206-SMD 1% 68R | 0.15
R21 | 1K | 204 | SMD | elpro - Elektronik | 1206-SMD 1% 1k | 0.15
R22 | 1K | 204 | SMD | elpro - Elektronik | 1206-SMD 1% 1k | 0.15
R23 | 90R9 | 204 | SMD | elpro - Elektronik | 1206-SMD 1% 91R | 0.15
R24 | 1R | 204 | SMD | elpro - Elektronik | 1206-SMD 1% 1R | 0.15
R25 | 47K5 | 204 | SMD | elpro - Elektronik | 1206-SMD 1% 47,5k | 0.15
R26 | 1k | R-POT-G | RCD | elpro - Elektronik | 64 Y 1 k | 0.70
R27 | 10R | 204 | SMD | elpro - Elektronik | 1206-SMD 1% 10R | 0.15
R28 | 1K | 204 | SMD | elpro - Elektronik | 1206-SMD 1% 1k | 0.15
R29 | 150R | 204 | SMD | elpro - Elektronik | 1206-SMD 1% 150R | 0.15
R30 | 10k | 204 | SMD | elpro - Elektronik | 1206-SMD 1% 10k | 0.15
R31 | 1k | 204 | SMD | elpro - Elektronik | 1206-SMD 1% 1k | 0.15
R32 | 5M6 | 204 | SMD | elpro - Elektronik | 1206-SMD 1% 5,6M | 0.15
R33 | 10k | 204 | SMD | elpro - Elektronik | 1206-SMD 1% 10k | 0.15
R34 | 10k | 204 | SMD | elpro - Elektronik | 1206-SMD 1% 10k | 0.15
R35 | 1k | 204 | SMD | elpro - Elektronik | 1206-SMD 1% 1k | 0.15
R36 | 3K32 | 204 | SMD | elpro - Elektronik | 1206-SMD 1% 3,32k | 0.15
R37 | 390R | 204 | SMD | elpro - Elektronik | 1206-SMD 1% 390R | 0.15
R38 | 1K | 204 | SMD | elpro - Elektronik | 1206-SMD 1% 1k | 0.15
R39 | 470R | 204 | SMD | elpro - Elektronik | 1206-SMD 1% 470R | 0.15
R40 | 390R | 204 | SMD | elpro - Elektronik | 1206-SMD 1% 390R | 0.15
R41 | 470k | 204 | SMD | elpro - Elektronik | 1206-SMD 1% 470k | 0.15
R42 | 10k | 204 | SMD | elpro - Elektronik | 1206-SMD 1% 10k | 0.15
R43 | 10k | 204 | SMD | elpro - Elektronik | 1206-SMD 1% 10k | 0.15
R44 | 1k | 204 | SMD | elpro - Elektronik | 1206-SMD 1% 1k | 0.15
R45 | 390R | 204 | SMD | elpro - Elektronik | 1206-SMD 1% 390R | 0.15
R46 | 390R | 204 | SMD | elpro - Elektronik | 1206-SMD 1% 390R | 0.15
R47 | 470k | 204 | SMD | elpro - Elektronik | 1206-SMD 1% 470k | 0.15
R48 | 1k | 204 | SMD | elpro - Elektronik | 1206-SMD 1% 1k | 0.15
R49 | 1k | 204 | SMD | elpro - Elektronik | 1206-SMD 1% 1k | 0.15
R50 | 10R | 204 | SMD | elpro - Elektronik | 1206-SMD 1% 10R | 0.15
R51 | 10R | 204 | SMD | elpro - Elektronik | 1206-SMD 1% 10R | 0.15
R52 | 10k | 204 | SMD | elpro - Elektronik | 1206-SMD 1% 10k | 0.15
R53 | 10k | 204 | SMD | elpro - Elektronik | 1206-SMD 1% 10k | 0.15
R54 | 2k7 | 204 | SMD | elpro - Elektronik | 1206-SMD 1% 2,7k | 0.15
R55 | 330R | 204 | SMD | elpro - Elektronik | 1206-SMD 1% 330R | 0.15
R56 | 10k | 204 | SMD | elpro - Elektronik | 1206-SMD 1% 10k | 0.15
R57 | 680R | 204 | SMD | elpro - Elektronik | 1206-SMD 1% 680R | 0.15
R58 | 100R | 204 | SMD | elpro - Elektronik | 1206-SMD 1% 100R | 0.15
R59 | 100R | 204 | SMD | elpro - Elektronik | 1206-SMD 1% 100R | 0.15
R60 | 1k | 204 | SMD | elpro - Elektronik | 1206-SMD 1% 1k | 0.15
R61 | 1k | 204 | SMD | elpro - Elektronik | 1206-SMD 1% 1k | 0.15
R62 | 22k | 204 | SMD | elpro - Elektronik | 1206-SMD 1% 22k | 0.15
R63 | 100k | 204 | SMD | elpro - Elektronik | 1206-SMD 1% 100k | 0.15
R64 | 10k | 204 | SMD | elpro - Elektronik | 1206-SMD 1% 10k | 0.15
R65 | 1M | 204 | SMD | elpro - Elektronik | 1206-SMD 1% 1M | 0.15
R66 | 1k | 204 | SMD | elpro - Elektronik | 1206-SMD 1% 1k | 0.15
R67 | 4k7 | 204 | SMD | elpro - Elektronik | 1206-SMD 1% 4,7k | 0.15
R68 | 22R | 204 | SMD | elpro - Elektronik | 1206-SMD 1% 22R | 0.15
R69 | 22R | 204 | SMD | elpro - Elektronik | 1206-SMD 1% 22R | 0.15
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

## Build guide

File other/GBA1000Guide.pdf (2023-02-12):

# User's Guide GB A1000 Motherboard

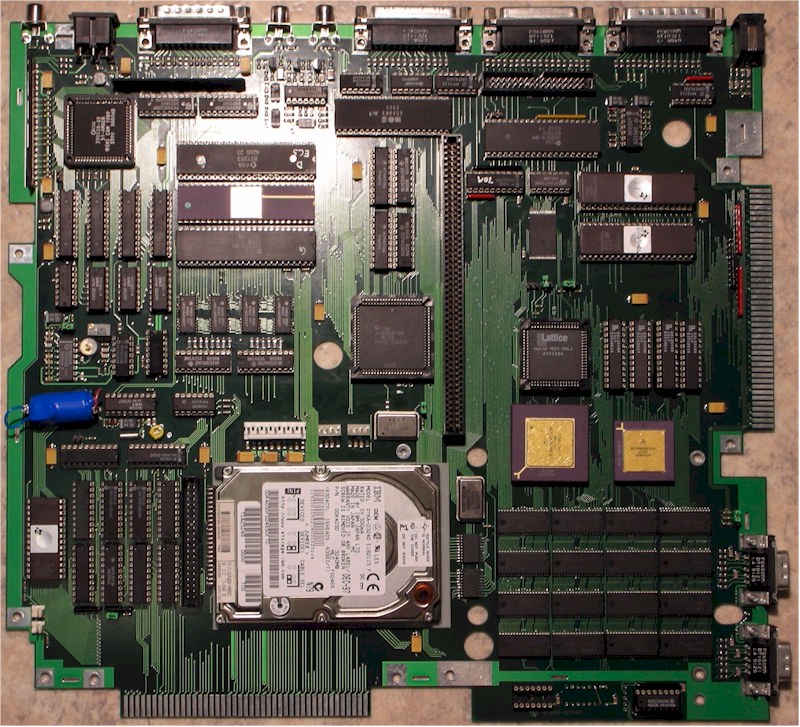
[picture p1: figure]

## GB A1000 Motherboard

# 1 General Information

The developer takes no responsibility for any damage or injuries caused by building and using the motherboard described in this guide. The responsibility of proper construction and usage of the motherboard lies solely on the individual building the motherboard.

When building and fitting the motherboard into the case it is imperative to obey the security guidelines of VDE. This work should only be performed by people skilled within this field.

If the proper procedures are not followed during construction and use, the user of the motherboard risks endangering his life.

No responsibility is taken for errors or printing errors in the following text.

Developer: | Georg Braun
Contact: | 97816@t-online.de
Translation: | Kristian Karlshøj

## Additional Editing: Troy Silvey

### Lohr, Germany, January 2008

### Translation, Mountain View, California, June 2008

# 2 Uses and Properties of the GB A1000 Motherboard

## 2.1 Operational Area

The GB A1000 motherboard is a replacement motherboard meant to be installed in the Amiga 1000 case. It has been designed with 2 MB CHIP RAM, an IDE controller, Flicker Fixer and a high performance central processor system.

Note: The Front-Slot of the GB A1000 Motherboard has been constructed to be similar to the side Expansion port. The A1000 256 kB memory expansion can not be used with this motherboard.

## 2.2 Usable Processors

The GB A1000 motherboard can be used with either MC68EC030 or MC68030 processors (CPU) at clock frequencies between 40 and 50 MHz. The clock frequency is chosen by a quartz-oscillator on the motherboard. The clock frequency used must be adapted to the used CPU.

To increase the performance of floating point applications the GB A1000 motherboard can be equipped with a MC68881/2 co-processor (FPU). For this purpose the PCB is equipped with a 68 pin PGA socket. The FPU uses the

### same clock frequency as the CPU and therefore does not need its own oscillator

## 2.3 Memory Specifications

The 32 bit wide, 8 MB, SRAM memory integrated on the GB A1000 motherboard can be included in the 24 bit address space in the auto configuration, or in the 32 bit address space by use of the integrated boot ROM. An increase in memory size is only possible with the addition of a memory expansion on the front, or side expansion slot. Expansion memory does not share the speed of the 32 bit memory.

The GB A1000 motherboard exhibits fast data throughput by use of SRAM despite lacking support for burst cycles. In comparison, similar performance is only reached by noticeably higher clock frequencies.

## 2.4 Boot ROM

A boot ROM has been included in the GB A1000 motherboard to integrate the SRAM memory into the 32 bit address space. This boot ROM contains 1 MB flash memory and includes additional space for optional software such as additional drivers. At the moment, the logic of the motherboard can only access 512 kB of the flash memory. Expanding access to the entire 1 MB will be implemented at a later time. To achieve this, the PLD chip (IC57) will need to be reprogrammed. Jumper S6 is also used to configure access to the 1 MB memory area. The boot ROM is activated by closing jumper S5. By closing S5 the 24 bit address space mode is switched off and the 32 bit address space is switched on. Working in 32 bit mode allows access to optional user software in the boot ROM. The position of jumpers S5 and S6 are shown in Chapter 3.1.
The boot ROM is deactivated when using the auto configuration. Access to the optional software in the boot ROM is not possible in this mode. Two small programs are at your disposition through the hardware development:
- The program "lösche BootROM" is used to erase the contents of the flash memory. This has to be done before any modification can be made to the boot ROM.
- The program "Einbindung_RAM" installs a driver in the boot ROM integrating the 8 MB SRAM memory in the 32 bit address space.
The memory can still be added to the 32 bit address space using the program AddMem even if the Boot ROM does not contain the driver. When using AddMem boot ROM must not contain the driver for RAM integration.

# 3 The Most Important Circuits on the GB A1000 Motherboard

## 3.1 Supported Processors

Depending on use, the GB A1000 motherboard can be fitted with processors of various speeds. The PCB supports clock frequencies between 40 and 50 MHz. The optional MC68881/2 co-processor will use the same clock frequency as the MC68030. An additional quartz oscillator for the co-processer is not required. An installed co-processer will automatically be detected by the GB A1000 motherboard. Therefore no jumper setting is required for an existing co-processor.

Caution!: The processors must be placed according to the following picture. By disregarding the orientation of the CPU you can expect to damage the PCB and the processors.

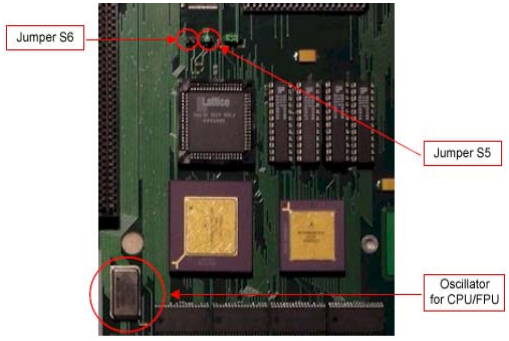
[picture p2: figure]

The quartz oscillator must comply with the clock frequency of the processor. If processors of different clock frequencies are used, the oscillator must comply with the processor with the lowest clock frequency.

Note: Over clocking of the processors is not advised. System stability and processor longevity cannot be assured when over clocking.
Oscillators with clock frequencies above 50 MHz cannot be used. The design of the motherboard is not suitable for clock frequencies above 50 MHz.

## 3.2 GB A1000 Motherboard Custom Chips

For the construction of the GB A1000 motherboard, various Commodore ICs are used. Some of these are difficult to obtain, you may have to get the components from discarded hardware. These ICs are known as the custom chips.

Note: As with all ICs it is important to equip the PCB with the correct ICs in the correct positions. Interchanging the chips by mistake can damage the chip as well as the motherboard.

## 3.2.1 Gary - IC50

Gary is responsible for the address decoding, control signals and chip line selection.
You can find the Gary chip in the A500, A2000 or A3000 marked as 5719.

## 3.2.2 Paula - IC41

Paula is responsible for the analog signal processing (sound/paddles), floppy control, and the RS232 port.
Paula is found in the A500, A1000, A2000 and A3000 marked as 8364R.

## 3.2.3 Denise - IC26

Denise is responsible for the graphics display and was made in an OCS and an ECS version. The difference lies in the available screen modes.
Denise is found in A500, A1000, A2000 and A3000. The OCS version is marked 8362R and the more powerful ECS version is marked 8373R.
For the GB A1000 motherboard both versions are usable but the use of the ECS version is recommended.

## 3.2.4 Amber - IC20

Amber contains the control logic for the flicker fixer. It allows the use of multi-sync monitors that support PAL screens at a refresh rate of 50 Hz. Amber was used in the A2320 flicker fixer card and in the A3000. The flicker fixer is an optional part of the GB A1000 motherboard.

## 3.2.5 Agnus – IC52

Agnus is responsible for controlling chip RAM, supplying the video sync signals (HSY, CSY, VSY) and contains the co-processors for copper and blitter. Agnus also handles DMA logic.
This motherboard requires 2MB chip RAM; using 1MB is not possible.
Agnus was made in many versions of which only a few can be used for the GB A1000 motherboard.
Either an 8372B (318069-03) or 8375 (318069-18, the NTSC version has not been tested on the board). During boot-up the screen mode of the computer can be changed by pressing space. If an 8372B is fitted jumper X17 (not fitted on the standard board) can be used to select PAL (X17 open) or NTSC (X17 closed) mode. If an 8375 Agnus is used jumper X17 must not be fitted.

## 3.2.6 CIA-A & B – IC40 & IC43

There are two CIA (Complex Interface Adapter) devices in the Amiga. Each has two main tasks to fulfill; First to establish the connection to the outside world via two 8 bit wide ports, and second, to do the internal timekeeping via two 16 bit and one 24 bit timers. The devices contain a bi-directional port (SP) for serial data transfer.
The CIAs are marked 8250 and found in A500, A1000, A2000 or A3000.

The TICK signal or the /VSYNC signal can be supplied to the CIA IC40 via jumper X16. Move X16 to the right for TICK or move X16 to the left for /VSYNC. This 50 Hz signal will be used for signal processing in the custom chips and is supplied by the A1000 through the power supply as the TICK signal. In the following models the /VSYNC signal is used. The GB A1000 motherboard can work with either setting. If the power supply does not supply a TICK signal (for instance a replacement power supply) the /VSYNC setting is necessary.

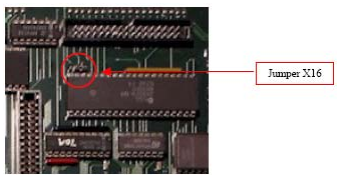
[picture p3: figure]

## 3.3 Kickstart Socket IC12 & IC13

To operate the GB A1000 motherboard an operating system, hereafter referred to as Kickstart, is necessary. The Kickstart is copyrighted and it is not permitted to copy or distribute it. Two sockets for placing Kickstart ROMs are integrated on the GB A1000 motherboard.

- Socket IC12 is available to place an original Kickstart ROM.
- Socket IC13 is available to place a 256 kB x 16 EPROM (for instance type 27C4096).

Jumper X21 is used to select which socket is used. If the right side of X21 is closed, the IC13 (EPROM) is activated. Closing the left side activates the ROM socket (IC12).
The EPROM Socket is intended for use with modified Kickstarts. It is also required that you own an original kickstart.

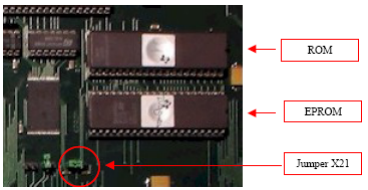
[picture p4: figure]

## 3.4 IDE Controller (Optional)

The GB A1000 motherboard includes an AT bus 2008 IDE controller by BSC. It has no RAM options and it only contains the IDE function of the original circuit. To enable the auto boot feature of the IDE controller, the related AT6.10 driver is used. The driver is loaded into EPROM IC34 (type 27C256). An image of the driver, in hex-file format, is available on the internet at http://amiga.resource.cx/exp/atbus2008. Optionally the OKTAPUS device found on Aminet can be used. This improves the functionality of the IDE controller.

Note: This is based on the original circuit from BSC. Due to lack of knowledge of the device, existing deficiencies cannot be corrected. If an unsolvable problem arises I recommend the use of an external IDE controller as for instance the Phoenix-Buddha.

On the GB A1000 motherboard you find two connectors for use of 40 pin and 44 pin IDE equipment. It is possible to use equipment in master–slave operation, but not all device combinations will work. The IDE controller can be switched off by closing jumper S2.

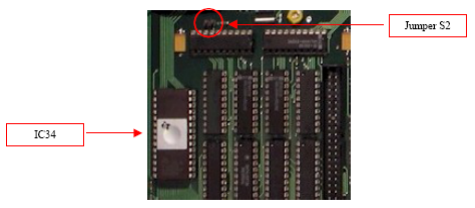
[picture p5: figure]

The motherboard can be built without the IDE controller. In this case the auto configuration has to bypass the non-existing IDE controller. This is done by bridging pin 9 and 16 of the socket for IC 19 with a 10 ohm resistor.

## 3.5 Flicker Fixer (Optional)

The flicker fixer on the GB A1000 motherboard is a copy of the A2320 Display Enhancer by Commodore. The circuitry has the stability of the original circuitry even though it is not an exact replication. Due to lack of documentation, the circuit diagrams of the A3000 were used as a basis. The PLL circuit though is an exact copy of the A2320 circuit. The work lies in doubling the line frequency to allow a multisync monitor to be connected to a GB A1000 motherboard. Furthermore the circuit can suppress the image flicker when interlace resolutions are used.

The motherboard can be built without the flicker fixer; this does not require any changes in the rest of the build.

The output of the flicker fixer connects to an 8 pin DIN connector. Therefore it is not necessary to connect the screen signal shielding to the chassis. The A1000 casing can therefore be left in original condition.
The disadvantage is that it is necessary to construct a VGA cable with a DIN plug. Below is the connection list:
15 pin VGA Plug | 8 pin DIN Plug | Signal
Pin 1 | Pin 2 | R (analog)
Pin 2 | Pin 3 | G (analog)
Pin 3 | Pin 4 | B (analog)
Pin 13 | Pin 7 | /HSYNC
Pin 9 | - | not used
Pin 14 | Pin 8 | /VSYNC
Pin 15 | - | not used
Pin 4, 5, 6, 7, 8,10, 11, 12 | Pin 1, 5, 6 + Shielding | GND

## 3.5.1 Supported Screen Resolutions

The GB A1000 VGA supports the following screen resolutions in NTSC or PAL. In this case the new ECS screen resolutions will also be used. Furthermore jumper S1 can be used to de-activate the GB A1000 VGA.

OCS Chip: - NTSC HighRes 640 x 200 60 Hz 15,734 kHz increased to 31,46 kHz - NTSC HighRes Interlace 640 x 400 60 Hz 15,734 kHz 31,46 kHz, flicker free - NTSC LowRes 320 x 200 60 Hz 15,734 kHz increased to 31,46 kHz - NTSC LowRes Interlace 320 x 400 60 Hz 15,734 kHz 31,46 kHz, flicker free - PAL HighRes 640 x 256 50 Hz 15,625 kHz increased to 31,25 kHz - PAL HighRes Interlace 640 x 512 50 Hz 15,625 kHz 31,25 kHz, flicker free - PAL LowRes 320 x 256 50 Hz 15,625 kHz increased to 31,25 kHz - PAL LowRes Interlace 320 x 512 50 Hz 15,625 kHz 31,25 kHz, flicker free

ECS Chip: - Multiscan Productivity 640 x 480 60 Hz 31,46 kHz (automatic bypass) - Multiscan Productivity 640 x 960 60 Hz 31,46 kHz (automatic bypass) - NTSC SuperHighRes 1280 x 200 60 Hz 15,734 kHz increased to 31,46 kHz - NTSC SuperHighRes Int. 1280 x 400 60 Hz 15,734 kHz 31,46 kHz, flicker free - PAL SuperHighRes 1280 x 256 50 Hz 15,625 kHz increased to 31,25 kHz - PAL SuperHighRes Int. 1280 x 512 50 Hz 15,625 kHz 31,25 kHz, flicker free - Full support of the overscan resolutions

## 3.5.2 PLL Circuitry Alignment

The flicker fixer PLL circuitry must be synced to the clock frequency of the GB A1000 motherboard. To do this, close the left side of jumper X7. The PLL circuitry is then enabled for Open-Loop operation. After the jumper is set the computer can be turned on. With use of the trim capacitor C59 it is possible to produce a stable image. When finished, close the right side of jumper X7. Now the regulation (Close-Loop) of the PLL circuit is switched on. Fine adjustment is possible using the trim resistor R26. With the trim resistor, the phase of the PLL output frequency is adjusted. Fine aliases in the lines can thereby be removed.
The adjustment needs to be made after the electronics have warmed up. It is best to turn the computer on for at least 15 minutes before adjusting the signal. For this adjustment a certain level of instinct is required. A re-adjustment may be necessary after a few hours of normal operation. An external switch mounted on the housing and connected to S1 will be needed to bypass VGA function without removing the case.

For the alignment adjustment the A2320 install disks can also be used. Depending on the operating system used, a reboot from the install disk might be required. The available adjustment images are excellent for fine tuning the PLL circuit.

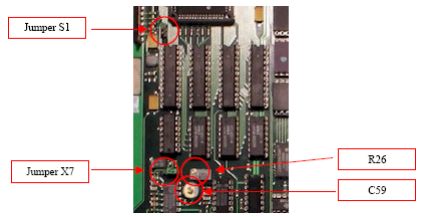
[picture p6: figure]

## 3.6 Clock Circuit

The GB A1000 motherboard contains a clock circuit with a real-time clock. The circuit can be adjusted for accuracy using trim capacitor C80.
The clock circuit is backed up by a battery. A 3.6 V Lithium battery with at least 1200 mAh is recommended. Be aware that the charging circuit requires a certain load resistance supplied by the Li battery if an alternative NiCad battery is used.

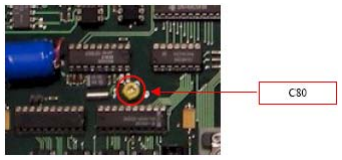
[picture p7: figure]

## 3.7 Programmable Logic Devices

The GB A1000 motherboard includes many programmable logic devices, several GALs and a CPLD. The jedec files necessary for programming are available for download in the GB A1000 file. To successfully build a GB A1000 access to a programmer for GAL and CPLD devices is necessary.

Caution!: Avoid misplacing the programmed devices. Mix-ups can result in damage to the motherboard.

# 4 Connectors on the GB A1000 Motherboard

## 4.1 Overview of the connectors

## 4.1.1 Connectors on the backside

The GB A1000 motherboard mimics the back side connectors of the A1000. The placement of the connectors is identical to the placement on the original A1000 motherboard and the Phoenix A1000.
The only exception is the DIN jack as it contains the signal from the flicker fixer.

Caution!: Some of the connectors contain supply voltage from the motherboard. It is recommended that no equipment be attached or detached while the computer is switched on. Failure to adhere to this recommendation may result in damage to the motherboard and/or the device being attached or detached.

## 4.1.2 Expansion Port

The left side 86 pin expansion port is nearly identical to the port in the original A1000. The exception is that pin 5 has the 7 MHz system clock added. Also the 28 MHz system clock has not been added as it was on the Phoenix board.

## 4.1.3 Front Slot

The 86 pin connector placed on the front of the motherboard is identical to the left side expansion port. In comparison to the Phoenix board, on the GB A1000 motherboard all signals are available. When the front slot is not used, close jumper S3 to bypass the configuration management. If jumper S3 is not closed and the front slot does not contain an expansion card, the configuration management is interrupted and all subsequent hardware components are not recognized.

Caution!: | If an expansion card is plugged in the front slot, S3 must be open! If it is not, the configuration signals of the card will be ignored, the expansion card will not be recognized and the expansion card may be damaged.

## 4.1.4 Zorro-II-Slot

A Zorro-II slot is built onto the GB A1000 motherboard. It is located in the same position as on the Phoenix board, but unlike the Phoenix board, it is a true Zorro-II slot. Therefore all Zorro-II signals are included in this connector.
Close jumper S7 to bypass the configuration manager when the Zorro-II slot is unused. If this jumper is open and no expansion card in inserted in the Zorro-II slot, the configuration manager is interrupted and all following hardware components are not recognized.

Caution!: If the jumper S7 is closed and an expansion card is plugged into the Zorro-II slot, the configuration signals of the expansion card will be suppressed, the expansion card will not be recognized and it may be damaged.

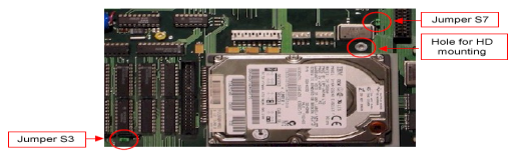
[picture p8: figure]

## 4.1.5 LED Connections

Connectors X13 and X26 are used to connect the LEDs for Power and HD-access. X13 connects the power LED and X26 is for the HD-LED.

### X13 Power- LED / X26 HD-LED

Pin | LED-Connection
1 | A
2 | K

## 4.1.6 Game and Mouse Port

On the left side are two 9 pin D-SUB connectors for a mouse and joystick. Both connectors are equivalent to the connectors on the A500. On the GB A1000 motherboard the port can be used to operate a light pen by using jumper X4. This function is the same as on the Phoenix board. If jumper X4 is closed in the upper position, the game port is selected for a light pen. If the jumper is closed in the lower position, the mouse port will be used.

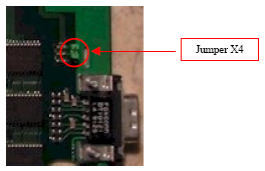
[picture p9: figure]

## 4.2 Connector Pinouts

## 4.2.1 VGA Output DIN Plug

### 8 pin DIN Plug

Pin | Signal
1 | GND
2 | R (analog)
3 | G (analog)
4 | B (analog)
5 | GND
6 | GND
7 | /HSYNC
8 | /VSYNC
Shield | GND

## 4.2.2 RGB Output

### 23 pin D-SUB Plug

Pin | Signal | Pin | Signal
1 | n.c. | 14 | PSWB
2 | n.c. | 15 | /CCKB
3 | R (analog) | 16 | GND
4 | G (analog) | 17 | GND
5 | B (analog) | 18 | GND
6 | DI | 19 | GND
7 | DB | 20 | GND
8 | DG | 21 | -5 V
9 | DR | 22 | +12 V
10 | /CSYNC | 23 | +5 V
11 | /HSYNC
12 | /VSYNC
13 | GND

## 4.2.3 RS232 Interface

### 25 pin D-SUB Plug

Pin | Signal | Pin | Signal
1 | GND | 14 | -5 V
2 | TxD | 15 | Audio-O
3 | RxD | 16 | Audio-I
4 | RTS | 17 | E-Clock
5 | CTS | 18 | /INT2
6 | DSR | 19 | n.c.
7 | GND | 20 | DTR
8 | CD | 21 | +5 V
9 | n.c. | 22 | n.c.
10 | n.c. | 23 | +12 V
11 | n.c. | 24 | /CCKQ
12 | n.c. | 25 | /SRESET
13 | n.c.

## 4.2.4 External Disk Drive

### 23 pin D-SUB Plug

Pin | Signal | Pin | Signal
1 | /RDY | 14 | /WPRO
2 | /DKRD | 15 | /TRK0
3 | GND | 16 | /DWE
4 | GND | 17 | /DWD
5 | GND | 18 | /STEP
6 | GND | 19 | DIR
7 | GND | 20 | /SEL3
8 | /MTRXD | 21 | /SEL1
9 | /SEL2 | 22 | /INDEX
10 | /DRESET | 23 | +12 V
11 | /CHNG
12 | +5 V
13 | /SIDE

## 4.2.5 Parallel Interface

### 25 pin D-SUB Plug

Pin | Signal | Pin | Signal
1 | /STROBE | 14 | GND
2 | D0 | 15 | GND
3 | D1 | 16 | GND
4 | D2 | 17 | GND
5 | D3 | 18 | GND
6 | D4 | 19 | GND
7 | D5 | 20 | GND
8 | D6 | 21 | GND
9 | D7 | 22 | GND
10 | /ACK | 23 | +5 V
11 | /BUSY | 24 | n.c.
12 | POUT | 25 | /IORESET
13 | SEL

## 4.2.6 Mouse and Joystick Port

### 9 pin D-SUB Plug (Mouse)

Pin | Signal | Pin | Signal
1 | MOUSE V | 6 | BUTTON 1
2 | MOUSE H | 7 | +5 V
3 | MOUSE VQ | 8 | GND
4 | MOUSE HQ | 9 | BUTTON 2
5 | BUTTON 3

### 9 pin D-SUB Plug (Joystick)

Pin | Signal | Pin | Signal
1 | /FORWARD | 6 | /FIRE
2 | /BACK | 7 | +5 V
3 | /LEFT | 8 | GND
4 | /RIGHT | 9 | POT Y
5 | POT X

# 5 Known Application Problems

## 5.1 Memory Integration through use of the AddMem Command

If the 32 bit SRAM is allocated by use of the AddMem command, there will be a noticeable drastic drop in the access speed and performance of the IDE controller compared to the memory is allocated using the auto configuration.
The reason is that during auto configuration, access of the IDE interface and other important parts of the OS are mapped in chip RAM. The only remedy is to have auto configuration map the FAST RAM to 32 bit SRAM at the system startup via a boot ROM driver before the operating system is loaded.

## 5.2 Memory Integration through use of a Boot ROM Driver

By allocating the 32 bit SRAM through a boot ROM driver, there will be noticeably slower file access and slower screen updates.
The reason is an unfavorable transfer rate for the file system from the hard drive. Using the HD-Toolbox, the transfer rate and the screen updating can be drastically improved by changing the File-System-Mask from 0X00FFFFFE (default) to 0XFFFFFFFC.

### 1. Open HD-Toolbox 2. Select ”Partition Drive” 3. Select partition and ”Advanced Options” 4. Select “Change File System for Partition” 5. Change the mask # to ”Mask = 0XFFFFFFFC” and exit the menu by clicking ”Ok” 6. Exit partition menu by clicking ”Ok”

7. Save the changes by clicking ”Save Changes to Drive” and exit HD-Toolbox by clicking ”Exit”

### 8. Reboot computer

Repeat step 3 to 5 for every partition on your hard drive. Further information about HD-Toolbox can be found in the HD-Toolbox guide.

Caution!: Wrongful entries in HD-Toolbox can result in loss of data, it is therefore recommended that data is backed up prior to manipulating the HD entries.

# 6 Technical Data

## 6.1 Memory Map

### - RAM 24 Bit Address space: Address $200000 to $9FFFFF - RAM 32 Bit Address space: Address $1200000 to $19FFFFF - Boot ROM: Address $F00000 to $F7FFFF

## 6.2 Protection Bits

The flash memory (boot ROM) on the motherboard is protected against accidental write and deletion processes. Furthermore the configuration data can be exported when the boot ROM is active. Using a write operation to the addresses below, the mentioned operations are activated. The addresses and descriptions are as follows:

### - Read configuration data: Address $1FA0004 - Write to / Erase flash: Address $1FA0002 - Reset protection bits: Address $1FA0000

## 6.3 Other Data

### - Measurements: 314 x 341 x 23 mm (L x W x D) - Maximal Clock frequency: 50 MHz - Minimal Clock frequency: 40 MHz - CPU: MC68030 or MC68EC030 - FPU: MC68881 or MC68882 - SRAM: 8 MB; Access in two clock cycles

## 6.4 Configuration Order

### - 1 Front slot; For instance IDE controller or memory expansion - 2 On-board IDE controller - 3 Zorro-II slot; For instance SCSI-, IDE interfaces - 4 32Bit RAM - 5 Expansion port; For instance IDE controller or memory expansion

# 7 Appendix

## 7.1 Silk Screen Side B

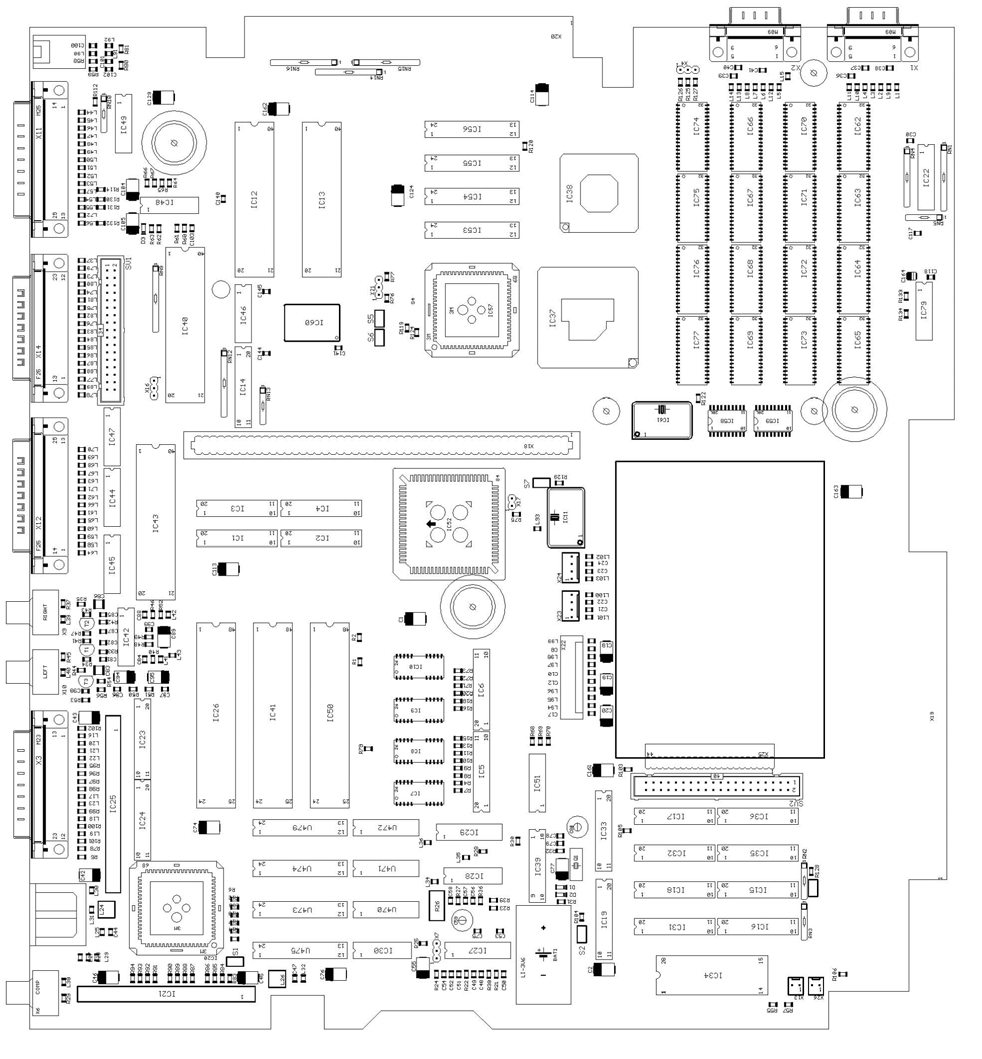
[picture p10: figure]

## 7.2 Silk Screen Side L

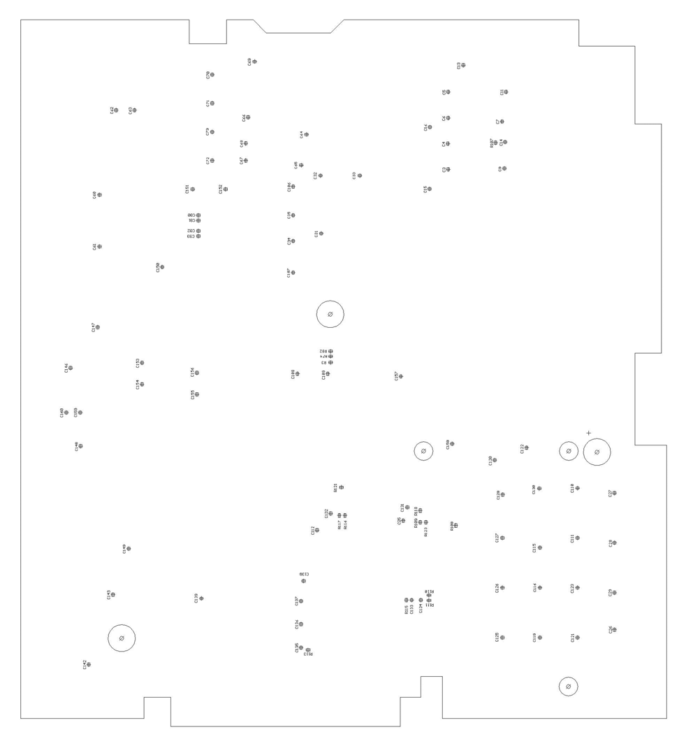
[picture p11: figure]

## 7.3 Circuit Diagram

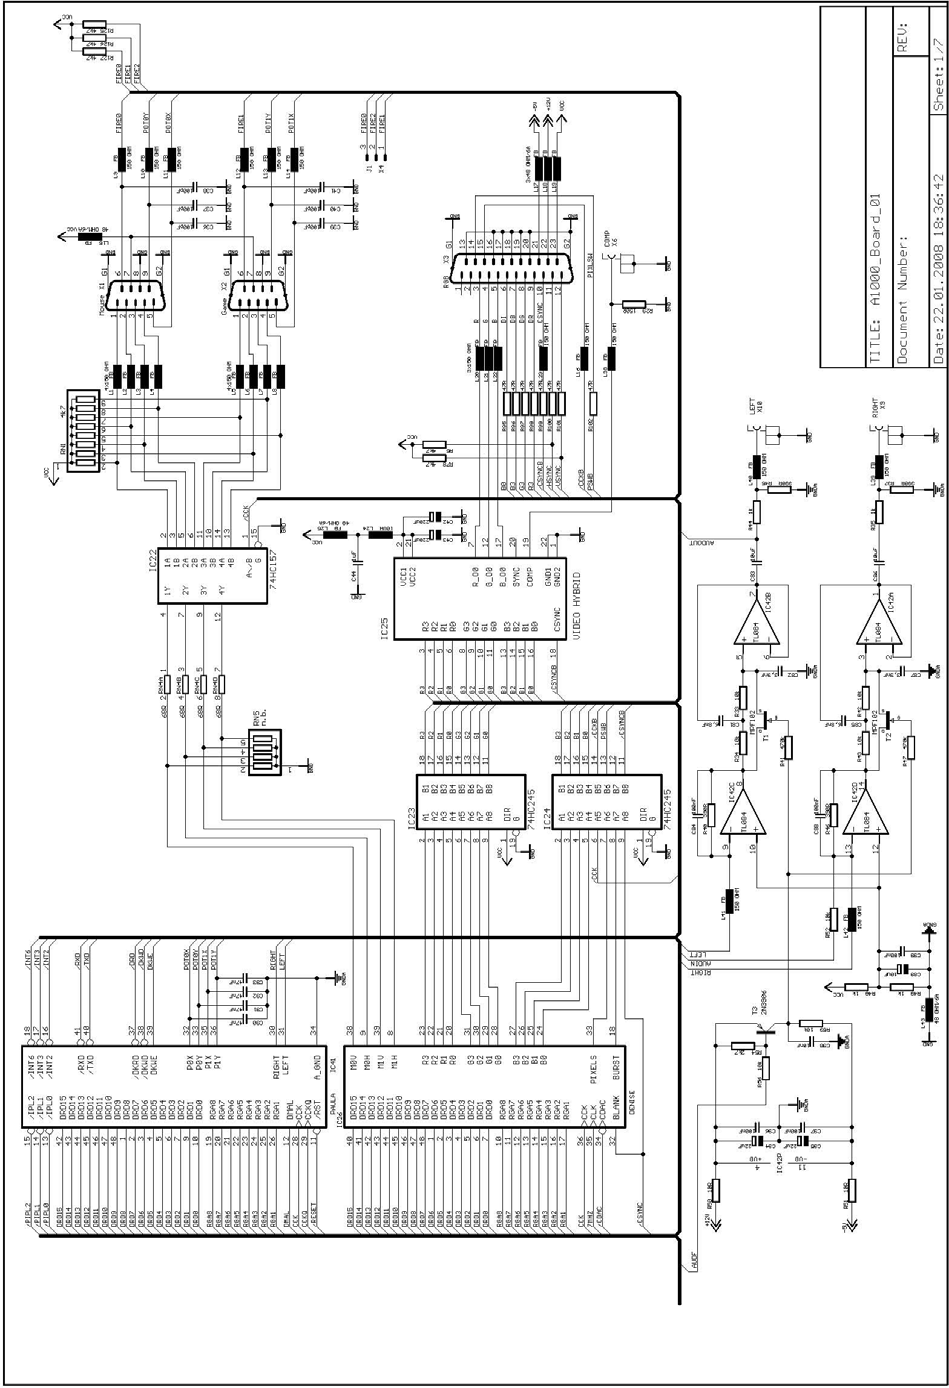
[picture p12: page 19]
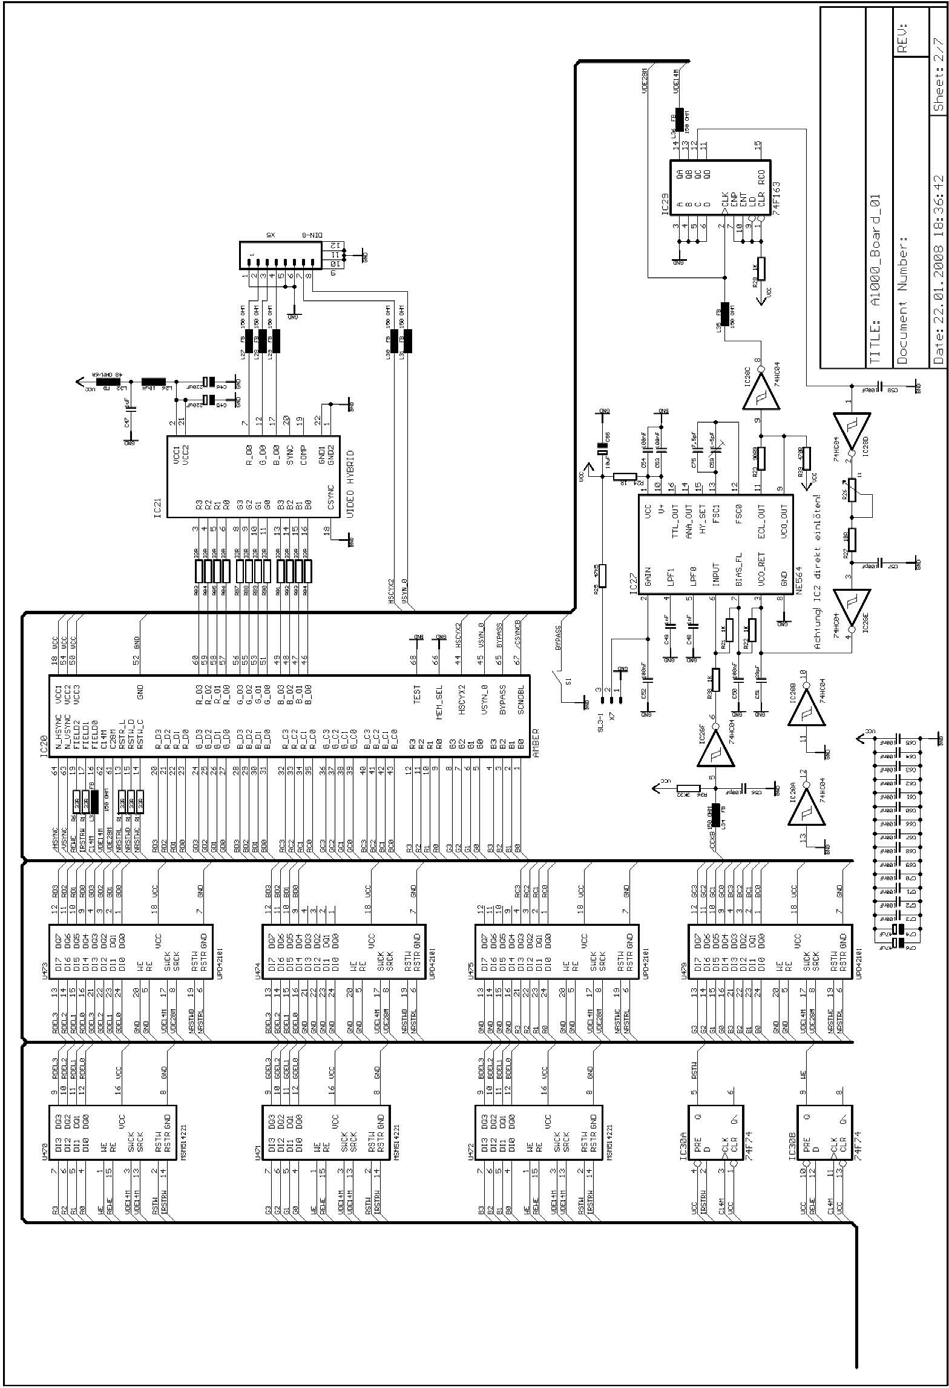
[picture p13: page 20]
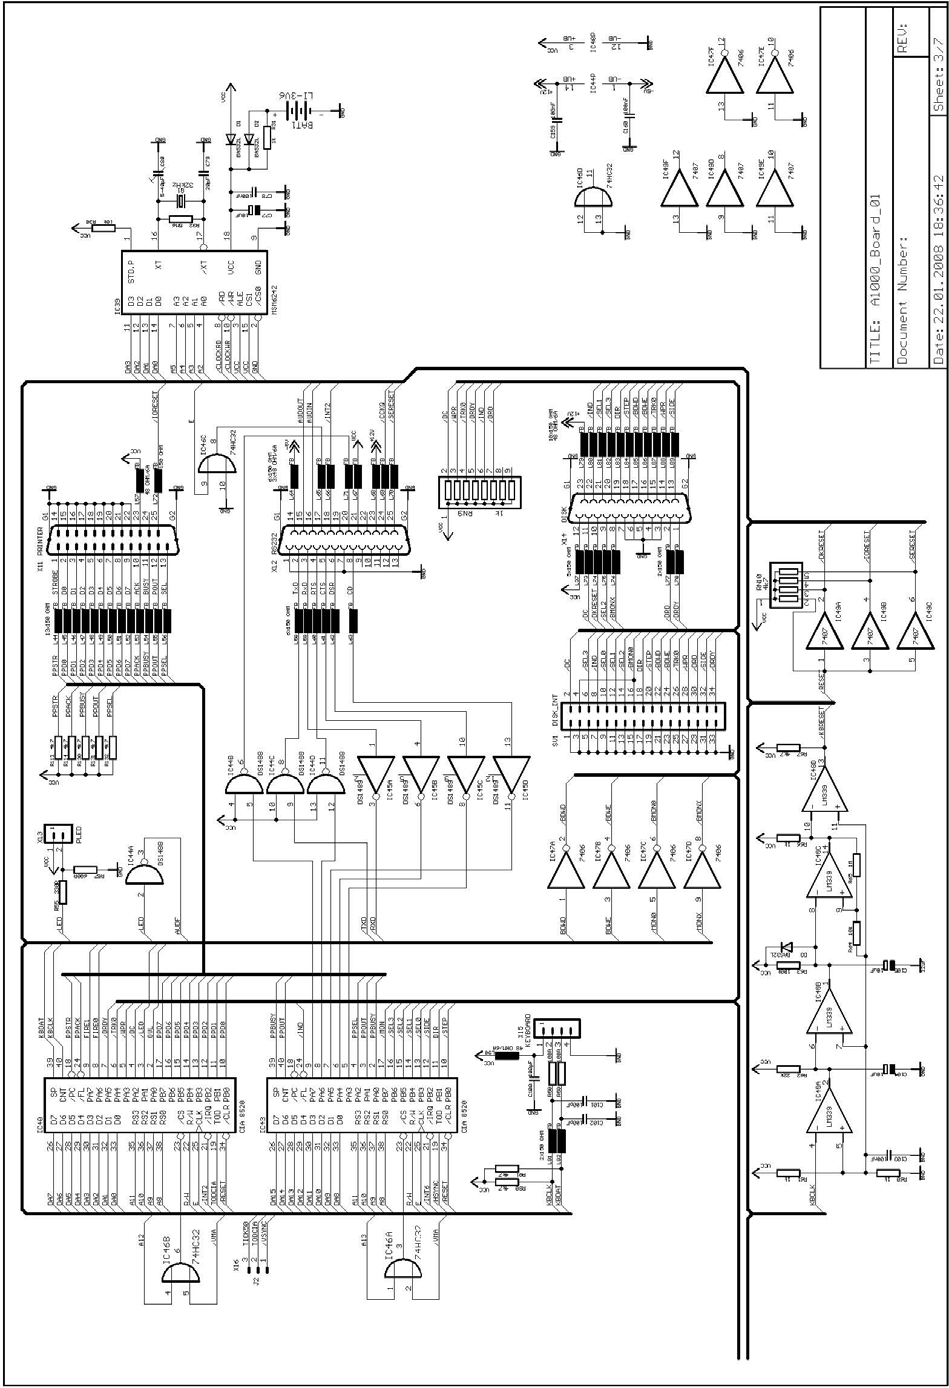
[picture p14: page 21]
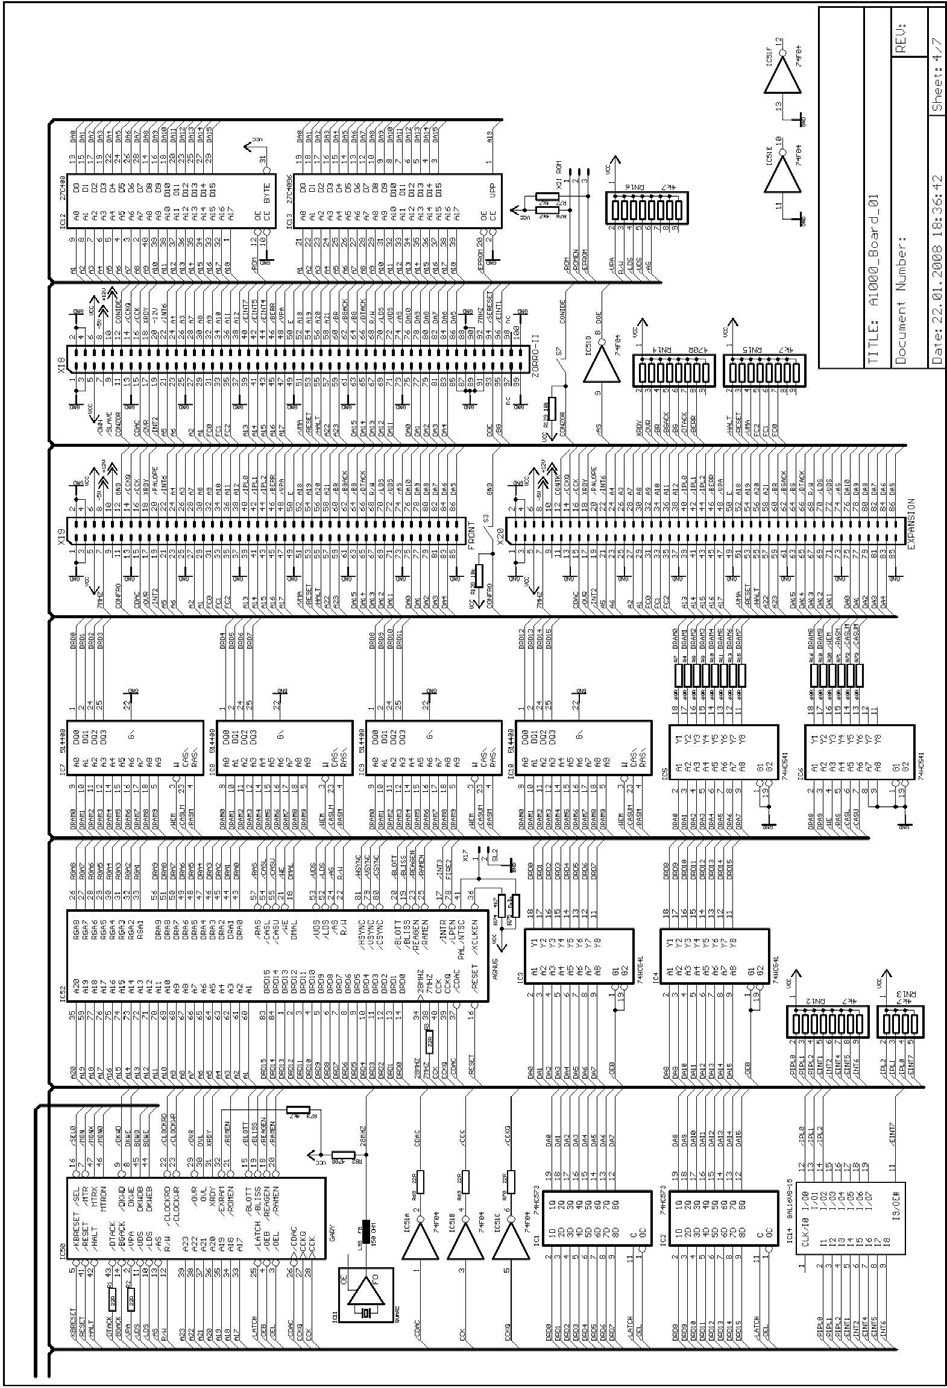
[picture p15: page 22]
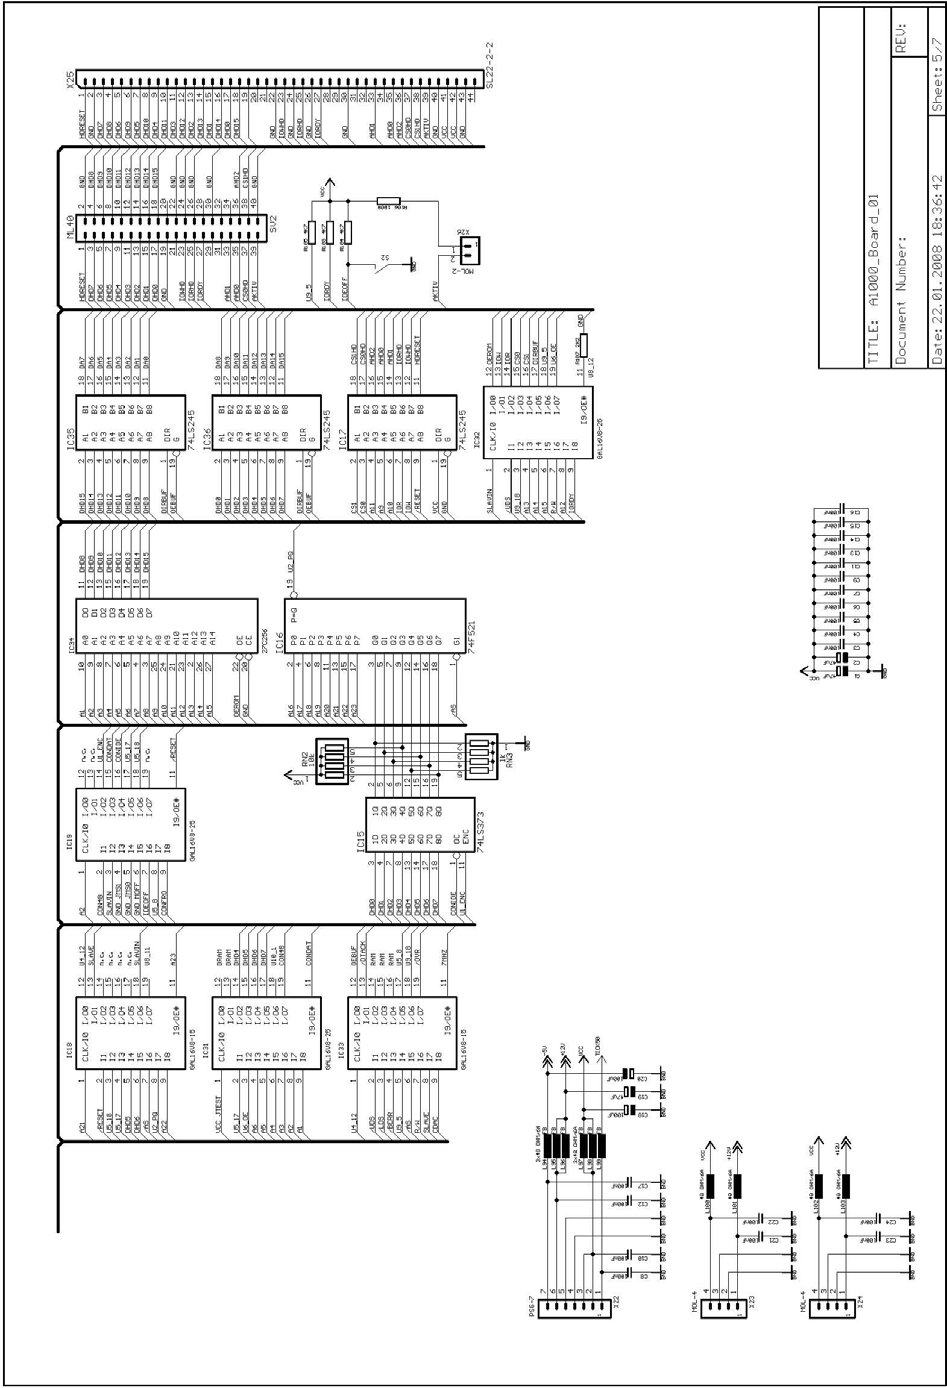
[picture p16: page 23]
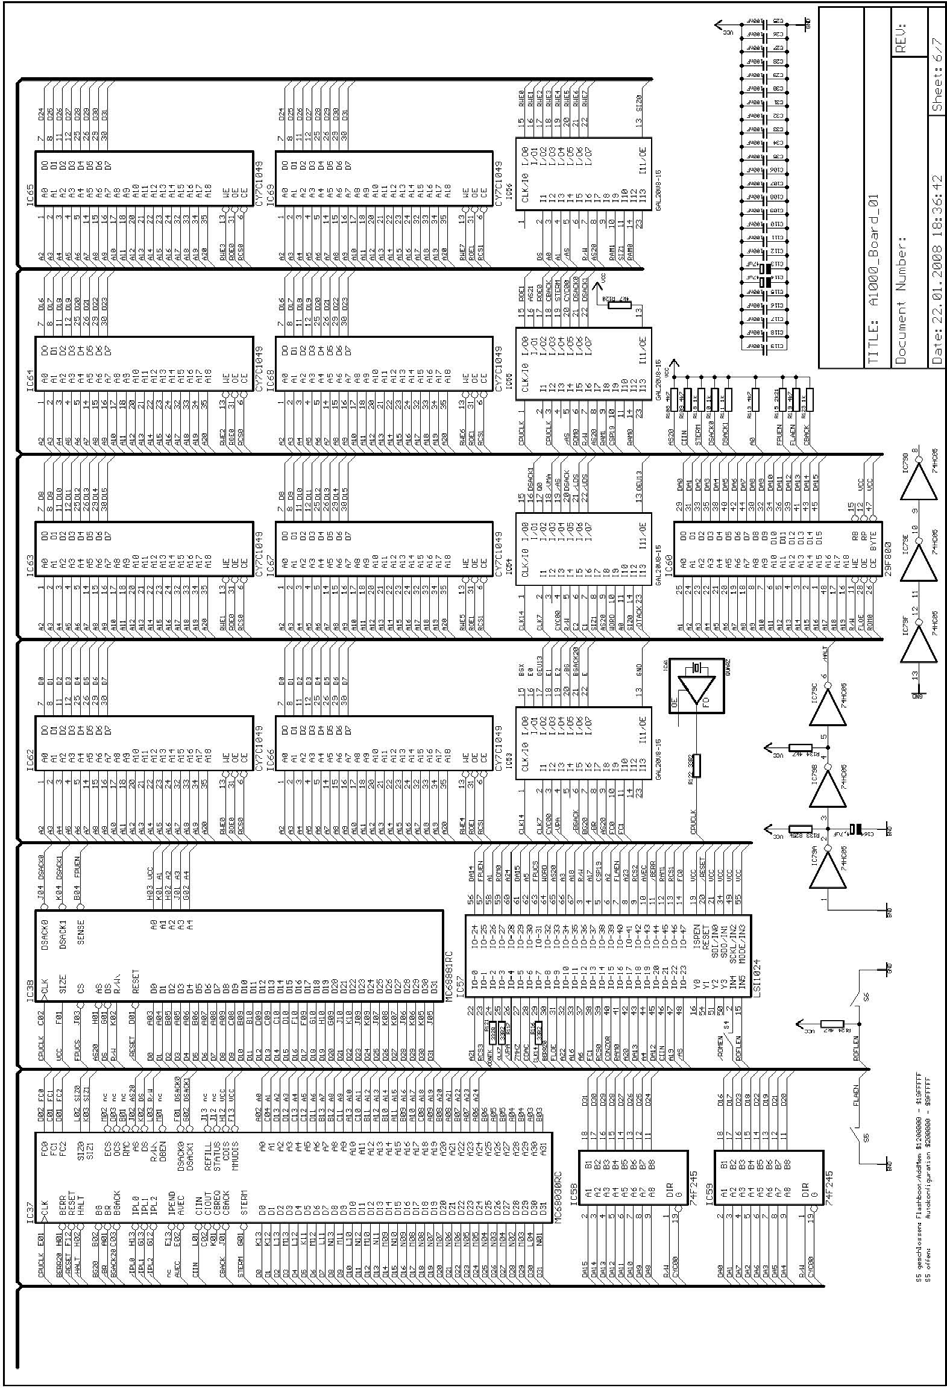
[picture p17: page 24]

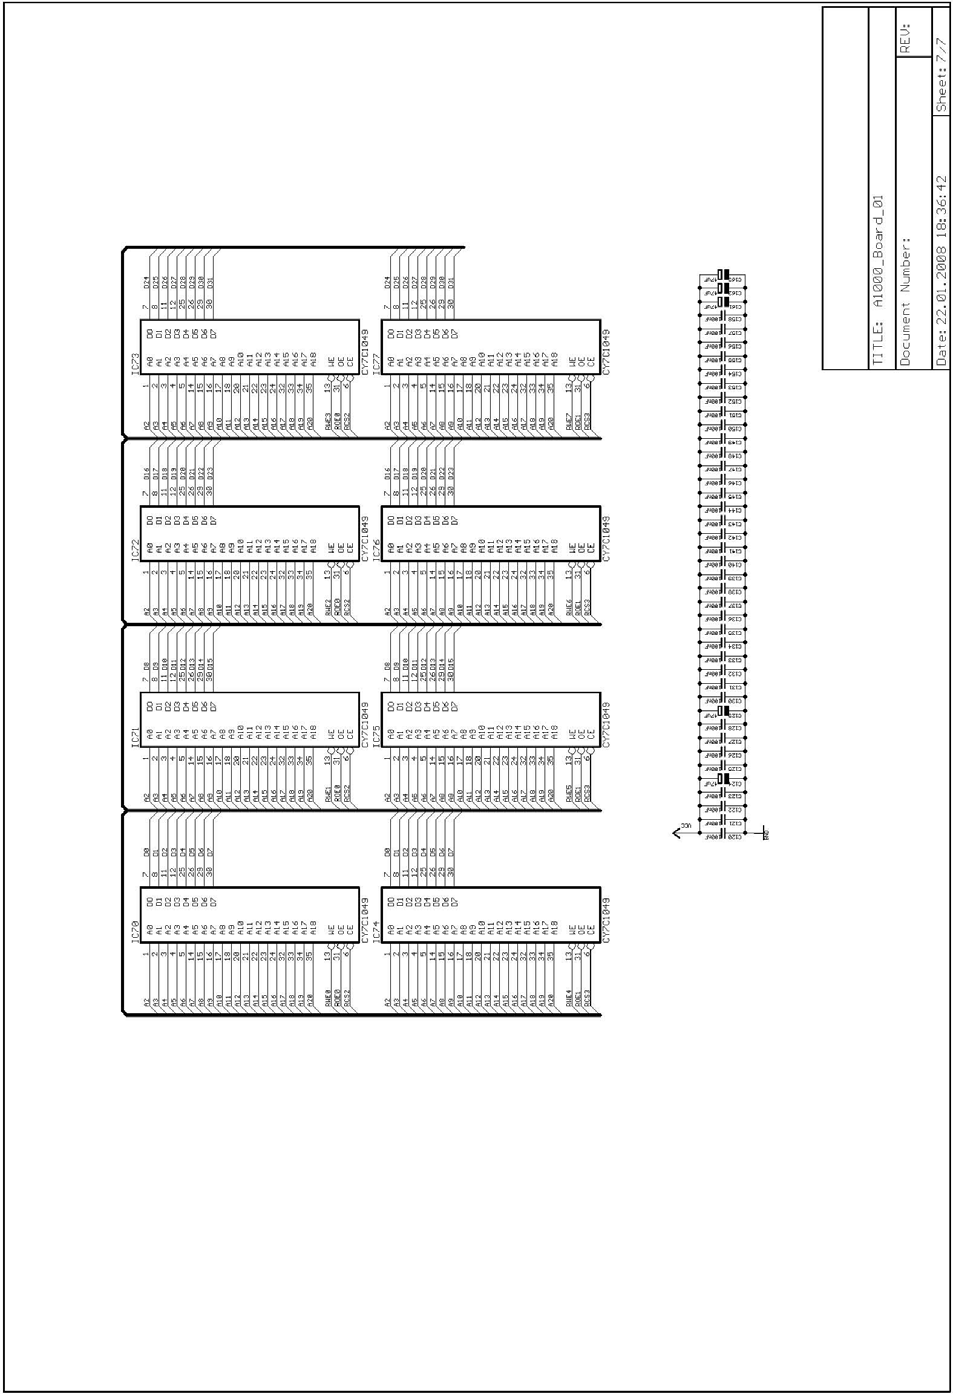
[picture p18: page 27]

## 7.4 Component List

Part | Value | Package | Type | Suggested Source | Item No. (From Source) | Price (€)
BAT1 | LI-3V6 | LI-3V6 | BATTERY | elpro - Elektronik | LS 14250 Drahtanschluss | 4.87
C1 | 47uF | 7243 | SMD | elpro - Elektronik | T-SMD 20V 47uF BF:D | 0.34
C2 | 47uF | 7243 | SMD | elpro - Elektronik | T-SMD 20V 47uF BF:D | 0.34
C3 | 100nF | 1206 | SMD | elpro - Elektronik | K-SMD 0,1uF 1206 | 0.11
C4 | 100nF | 1206 | SMD | elpro - Elektronik | K-SMD 0,1uF 1206 | 0.11
C5 | 100nF | 1206 | SMD | elpro - Elektronik | K-SMD 0,1uF 1206 | 0.11
C6 | 100nF | 1206 | SMD | elpro - Elektronik | K-SMD 0,1uF 1206 | 0.11
C7 | 100nF | 1206 | SMD | elpro - Elektronik | K-SMD 0,1uF 1206 | 0.11
C8 | 100nF | 1206 | SMD | elpro - Elektronik | K-SMD 0,1uF 1206 | 0.11
C9 | 100nF | 1206 | SMD | elpro - Elektronik | K-SMD 0,1uF 1206 | 0.11
C10 | 100nF | 1206 | SMD | elpro - Elektronik | K-SMD 0,1uF 1206 | 0.11
C11 | 100nF | 1206 | SMD | elpro - Elektronik | K-SMD 0,1uF 1206 | 0.11
C12 | 100nF | 1206 | SMD | elpro - Elektronik | K-SMD 0,1uF 1206 | 0.11
C13 | 100nF | 1206 | SMD | elpro - Elektronik | K-SMD 0,1uF 1206 | 0.11
C14 | 100nF | 1206 | SMD | elpro - Elektronik | K-SMD 0,1uF 1206 | 0.11
C15 | 100nF | 1206 | SMD | elpro - Elektronik | K-SMD 0,1uF 1206 | 0.11
C16 | 100nF | 1206 | SMD | elpro - Elektronik | K-SMD 0,1uF 1206 | 0.11
C17 | 100nF | 1206 | SMD | elpro - Elektronik | K-SMD 0,1uF 1206 | 0.11
C18 | 100uF | 7243 | SMD | elpro - Elektronik | T-SMD 16V 100uF BF:D | 0.22
C19 | 47uF | 7243 | SMD | elpro - Elektronik | T-SMD 20V 47uF BF:D | 0.34
C20 | 100uF | 7243 | SMD | elpro - Elektronik | T-SMD 16V 100uF BF:D | 0.22
C21 | 100nF | 1206 | SMD | elpro - Elektronik | K-SMD 0,1uF 1206 | 0.11
C22 | 100nF | 1206 | SMD | elpro - Elektronik | K-SMD 0,1uF 1206 | 0.11
C23 | 100nF | 1206 | SMD | elpro - Elektronik | K-SMD 0,1uF 1206 | 0.11
C24 | 100nF | 1206 | SMD | elpro - Elektronik | K-SMD 0,1uF 1206 | 0.11
C25 | 100nF | 1206 | SMD | elpro - Elektronik | K-SMD 0,1uF 1206 | 0.11
C26 | 100nF | 1206 | SMD | elpro - Elektronik | K-SMD 0,1uF 1206 | 0.11
C27 | 100nF | 1206 | SMD | elpro - Elektronik | K-SMD 0,1uF 1206 | 0.11
C28 | 100nF | 1206 | SMD | elpro - Elektronik | K-SMD 0,1uF 1206 | 0.11
C29 | 100nF | 1206 | SMD | elpro - Elektronik | K-SMD 0,1uF 1206 | 0.11
C30 | 100nF | 1206 | SMD | elpro - Elektronik | K-SMD 0,1uF 1206 | 0.11
C31 | 100nF | 1206 | SMD | elpro - Elektronik | K-SMD 0,1uF 1206 | 0.11
C32 | 100nF | 1206 | SMD | elpro - Elektronik | K-SMD 0,1uF 1206 | 0.11
C33 | 100nF | 1206 | SMD | elpro - Elektronik | K-SMD 0,1uF 1206 | 0.11
C34 | 100nF | 1206 | SMD | elpro - Elektronik | K-SMD 0,1uF 1206 | 0.11
C35 | 100nF | 1206 | SMD | elpro - Elektronik | K-SMD 0,1uF 1206 | 0.11
C36 | 100pF | 1206 | SMD | elpro - Elektronik | K-SMD 100 pF 1206 | 0.11
C37 | 100pF | 1206 | SMD | elpro - Elektronik | K-SMD 100 pF 1206 | 0.11
C38 | 100pF | 1206 | SMD | elpro - Elektronik | K-SMD 100 pF 1206 | 0.11
C39 | 100pF | 1206 | SMD | elpro - Elektronik | K-SMD 100 pF 1206 | 0.11
C40 | 100pF | 1206 | SMD | elpro - Elektronik | K-SMD 100 pF 1206 | 0.11
C41 | 100pF | 1206 | SMD | elpro - Elektronik | K-SMD 100 pF 1206 | 0.11
C42 | 220uF | 7243 | SMD | elpro - Elektronik | T-SMD 6,3V 220uF BF:D | 0.45
C43 | 220uF | 7243 | SMD | elpro - Elektronik | T-SMD 6,3V 220uF BF:D | 0.45
C44 | 1uF | 1206 | SMD | elpro - Elektronik | K-SMD 1uF 1206 | 0.12
C45 | 220uF | 7243 | SMD | elpro - Elektronik | T-SMD 6,3V 220uF BF:D | 0.45
C46 | 220uF | 7243 | SMD | elpro - Elektronik | T-SMD 6,3V 220uF BF:D | 0.45
C47 | 1uF | 1206 | SMD | elpro - Elektronik | K-SMD 1uF 1206 | 0.12
C48 | 1nF | 1206 | SMD | elpro - Elektronik | K-SMD 1000 pF 1206 | 0.11
C49 | 1nF | 1206 | SMD | elpro - Elektronik | K-SMD 1000 pF 1206 | 0.11
C50 | 100nF | 1206 | SMD | elpro - Elektronik | K-SMD 0,1uF 1206 | 0.11

Part | Value | Package | Type | Suggested Source | Item No. (From Source) | Price (€)
C51 | 39pF | 1206 | SMD | elpro - Elektronik | K-SMD 39 pF 1206 | 0.11
C52 | 100nF | 1206 | SMD | elpro - Elektronik | K-SMD 0,1uF 1206 | 0.11
C53 | 100nF | 1206 | SMD | elpro - Elektronik | K-SMD 0,1uF 1206 | 0.11
C54 | 100nF | 1206 | SMD | elpro - Elektronik | K-SMD 0,1uF 1206 | 0.11
C55 | 10uF | 7243 | SMD | elpro - Elektronik | T-SMD 25V 10uF BF:D | 0.24
C56 | 100pF | 1206 | SMD | elpro - Elektronik | K-SMD 100 pF 1206 | 0.11
C57 | 100pF | 1206 | SMD | elpro - Elektronik | K-SMD 100 pF 1206 | 0.11
C58 | 100pF | 1206 | SMD | elpro - Elektronik | K-SMD 100 pF 1206 | 0.11
C59 | 1-5pF | C-TRIM-1 | RCD | elpro - Elektronik | 808-1 1,4-5,5 pF | 0.36
C60 | 100nF | 1206 | SMD | elpro - Elektronik | K-SMD 0,1uF 1206 | 0.11
C61 | 100nF | 1206 | SMD | elpro - Elektronik | K-SMD 0,1uF 1206 | 0.11
C62 | 100nF | 1206 | SMD | elpro - Elektronik | K-SMD 0,1uF 1206 | 0.11
C63 | 100nF | 1206 | SMD | elpro - Elektronik | K-SMD 0,1uF 1206 | 0.11
C64 | 100nF | 1206 | SMD | elpro - Elektronik | K-SMD 0,1uF 1206 | 0.11
C65 | 100nF | 1206 | SMD | elpro - Elektronik | K-SMD 0,1uF 1206 | 0.11
C66 | 100nF | 1206 | SMD | elpro - Elektronik | K-SMD 0,1uF 1206 | 0.11
C67 | 100nF | 1206 | SMD | elpro - Elektronik | K-SMD 0,1uF 1206 | 0.11
C68 | 100nF | 1206 | SMD | elpro - Elektronik | K-SMD 0,1uF 1206 | 0.11
C69 | 100nF | 1206 | SMD | elpro - Elektronik | K-SMD 0,1uF 1206 | 0.11
C70 | 100nF | 1206 | SMD | elpro - Elektronik | K-SMD 0,1uF 1206 | 0.11
C71 | 100nF | 1206 | SMD | elpro - Elektronik | K-SMD 0,1uF 1206 | 0.11
C72 | 100nF | 1206 | SMD | elpro - Elektronik | K-SMD 0,1uF 1206 | 0.11
C73 | 100nF | 1206 | SMD | elpro - Elektronik | K-SMD 0,1uF 1206 | 0.11
C74 | 47uF | 7243 | SMD | elpro - Elektronik | T-SMD 20V 47uF BF:D | 0.34
C75 | 7,5pF | 1206 | SMD | elpro - Elektronik | K-SMD 8,2 pF 1206 | 0.11
C76 | 47uF | 7243 | SMD | elpro - Elektronik | T-SMD 20V 47uF BF:D | 0.34
C77 | 10uF | 7243 | SMD | elpro - Elektronik | T-SMD 25V 10uF BF:D | 0.24
C78 | 100nF | 1206 | SMD | elpro - Elektronik | K-SMD 0,1uF 1206 | 0.11
C79 | 20pF | 1206 | SMD | elpro - Elektronik | K-SMD 22 pF 1206 | 0.11
C80 | 5-40pF | C-TRIM-1 | RCD | elpro - Elektronik | 808-1 3-40 pF | 0.40
C81 | 6,8nF | 1206 | SMD | elpro - Elektronik | K-SMD 6800 pF 1206 | 0.11
C82 | 3,9nF | 1206 | SMD | elpro - Elektronik | K-SMD 3900 pF 1206 | 0.11
C83 | 10uF | 1812 | SMD | elpro - Elektronik | T-SMD 25V 10uF BF:D | 0.24
C84 | 100nF | 1206 | SMD | elpro - Elektronik | K-SMD 0,1uF 1206 | 0.11
C85 | 6,8nF | 1206 | SMD | elpro - Elektronik | K-SMD 6800 pF 1206 | 0.11
C86 | 10uF | 1812 | SMD | elpro - Elektronik | T-SMD 25V 10uF BF:D | 0.24
C87 | 3,9nF | 1206 | SMD | elpro - Elektronik | K-SMD 3900 pF 1206 | 0.11
C88 | 100nF | 1206 | SMD | elpro - Elektronik | K-SMD 0,1uF 1206 | 0.11
C89 | 10uF | 7243 | SMD | elpro - Elektronik | T-SMD 25V 10uF BF:D | 0.24
C90 | 47nF | 1206 | SMD | elpro - Elektronik | K-SMD 0,047uF 1206 | 0.11
C91 | 47nF | 1206 | SMD | elpro - Elektronik | K-SMD 0,047uF 1206 | 0.11
C92 | 47nF | 1206 | SMD | elpro - Elektronik | K-SMD 0,047uF 1206 | 0.11
C93 | 47nF | 1206 | SMD | elpro - Elektronik | K-SMD 0,047uF 1206 | 0.11
C94 | 22uF | 7243 | SMD | elpro - Elektronik | T-SMD 25V 22uF BF:D | 0.30
C95 | 22uF | 7243 | SMD | elpro - Elektronik | T-SMD 25V 22uF BF:D | 0.30
C96 | 100nF | 1206 | SMD | elpro - Elektronik | K-SMD 0,1uF 1206 | 0.11
C97 | 100nF | 1206 | SMD | elpro - Elektronik | K-SMD 0,1uF 1206 | 0.11
C98 | 10nF | 1206 | SMD | elpro - Elektronik | K-SMD 0,01uF 1206 | 0.11
C99 | 100nF | 1206 | SMD | elpro - Elektronik | K-SMD 0,1uF 1206 | 0.11
C100 | 100pF | 1206 | SMD | elpro - Elektronik | K-SMD 100 pF 1206 | 0.11
C101 | 100pF | 1206 | SMD | elpro - Elektronik | K-SMD 100 pF 1206 | 0.11
C102 | 100pF | 1206 | SMD | elpro - Elektronik | K-SMD 100 pF 1206 | 0.11
C103 | 100nF | 1206 | SMD | elpro - Elektronik | K-SMD 0,1uF 1206 | 0.11

Part | Value | Package | Type | Suggested Source | Item No. (From Source) | Price (€)
C104 | 10uF | 7243 | SMD | elpro - Elektronik | T-SMD 25V 10uF BF:D | 0.24
C105 | 10uF | 7243 | SMD | elpro - Elektronik | T-SMD 25V 10uF BF:D | 0.24
C106 | 100nF | 1206 | SMD | elpro - Elektronik | K-SMD 0,1uF 1206 | 0.11
C107 | 100nF | 1206 | SMD | elpro - Elektronik | K-SMD 0,1uF 1206 | 0.11
C108 | 100nF | 1206 | SMD | elpro - Elektronik | K-SMD 0,1uF 1206 | 0.11
C109 | 100nF | 1206 | SMD | elpro - Elektronik | K-SMD 0,1uF 1206 | 0.11
C110 | 100nF | 1206 | SMD | elpro - Elektronik | K-SMD 0,1uF 1206 | 0.11
C111 | 100nF | 1206 | SMD | elpro - Elektronik | K-SMD 0,1uF 1206 | 0.11
C112 | 100nF | 1206 | SMD | elpro - Elektronik | K-SMD 0,1uF 1206 | 0.11
C113 | 47uF | 7243 | SMD | elpro - Elektronik | T-SMD 20V 47uF BF:D | 0.34
C114 | 47uF | 7243 | SMD | elpro - Elektronik | T-SMD 20V 47uF BF:D | 0.34
C115 | 100nF | 1206 | SMD | elpro - Elektronik | K-SMD 0,1uF 1206 | 0.11
C116 | 100nF | 1206 | SMD | elpro - Elektronik | K-SMD 0,1uF 1206 | 0.11
C117 | 100nF | 1206 | SMD | elpro - Elektronik | K-SMD 0,1uF 1206 | 0.11
C118 | 100nF | 1206 | SMD | elpro - Elektronik | K-SMD 0,1uF 1206 | 0.11
C119 | 100nF | 1206 | SMD | elpro - Elektronik | K-SMD 0,1uF 1206 | 0.11
C120 | 100nF | 1206 | SMD | elpro - Elektronik | K-SMD 0,1uF 1206 | 0.11
C121 | 100nF | 1206 | SMD | elpro - Elektronik | K-SMD 0,1uF 1206 | 0.11
C122 | 100nF | 1206 | SMD | elpro - Elektronik | K-SMD 0,1uF 1206 | 0.11
C123 | 100nF | 1206 | SMD | elpro - Elektronik | K-SMD 0,1uF 1206 | 0.11
C124 | 47uF | 7243 | SMD | elpro - Elektronik | T-SMD 20V 47uF BF:D | 0.34
C125 | 100nF | 1206 | SMD | elpro - Elektronik | K-SMD 0,1uF 1206 | 0.11
C126 | 100nF | 1206 | SMD | elpro - Elektronik | K-SMD 0,1uF 1206 | 0.11
C127 | 100nF | 1206 | SMD | elpro - Elektronik | K-SMD 0,1uF 1206 | 0.11
C128 | 100nF | 1206 | SMD | elpro - Elektronik | K-SMD 0,1uF 1206 | 0.11
C129 | 47uF | 7243 | SMD | elpro - Elektronik | T-SMD 20V 47uF BF:D | 0.34
C130 | 100nF | 1206 | SMD | elpro - Elektronik | K-SMD 0,1uF 1206 | 0.11
C131 | 100nF | 1206 | SMD | elpro - Elektronik | K-SMD 0,1uF 1206 | 0.11
C132 | 100nF | 1206 | SMD | elpro - Elektronik | K-SMD 0,1uF 1206 | 0.11
C133 | 100nF | 1206 | SMD | elpro - Elektronik | K-SMD 0,1uF 1206 | 0.11
C134 | 100nF | 1206 | SMD | elpro - Elektronik | K-SMD 0,1uF 1206 | 0.11
C135 | 100nF | 1206 | SMD | elpro - Elektronik | K-SMD 0,1uF 1206 | 0.11
C136 | 100nF | 1206 | SMD | elpro - Elektronik | K-SMD 0,1uF 1206 | 0.11
C137 | 100nF | 1206 | SMD | elpro - Elektronik | K-SMD 0,1uF 1206 | 0.11
C138 | 100nF | 1206 | SMD | elpro - Elektronik | K-SMD 0,1uF 1206 | 0.11
C139 | 100nF | 1206 | SMD | elpro - Elektronik | K-SMD 0,1uF 1206 | 0.11
C140 | 100nF | 1206 | SMD | elpro - Elektronik | K-SMD 0,1uF 1206 | 0.11
C141 | 100nF | 1206 | SMD | elpro - Elektronik | K-SMD 0,1uF 1206 | 0.11
C142 | 100nF | 1206 | SMD | elpro - Elektronik | K-SMD 0,1uF 1206 | 0.11
C143 | 100nF | 1206 | SMD | elpro - Elektronik | K-SMD 0,1uF 1206 | 0.11
C144 | 100nF | 1206 | SMD | elpro - Elektronik | K-SMD 0,1uF 1206 | 0.11
C145 | 100nF | 1206 | SMD | elpro - Elektronik | K-SMD 0,1uF 1206 | 0.11
C146 | 100nF | 1206 | SMD | elpro - Elektronik | K-SMD 0,1uF 1206 | 0.11
C147 | 100nF | 1206 | SMD | elpro - Elektronik | K-SMD 0,1uF 1206 | 0.11
C148 | 100nF | 1206 | SMD | elpro - Elektronik | K-SMD 0,1uF 1206 | 0.11
C149 | 100nF | 1206 | SMD | elpro - Elektronik | K-SMD 0,1uF 1206 | 0.11
C150 | 100nF | 1206 | SMD | elpro - Elektronik | K-SMD 0,1uF 1206 | 0.11
C151 | 100nF | 1206 | SMD | elpro - Elektronik | K-SMD 0,1uF 1206 | 0.11
C152 | 100nF | 1206 | SMD | elpro - Elektronik | K-SMD 0,1uF 1206 | 0.11
C153 | 100nF | 1206 | SMD | elpro - Elektronik | K-SMD 0,1uF 1206 | 0.11
C154 | 100nF | 1206 | SMD | elpro - Elektronik | K-SMD 0,1uF 1206 | 0.11
C155 | 100nF | 1206 | SMD | elpro - Elektronik | K-SMD 0,1uF 1206 | 0.11
C156 | 100nF | 1206 | SMD | elpro - Elektronik | K-SMD 0,1uF 1206 | 0.11

Part | Value | Package | Type | Suggested Source | Item No. (From Source) | Price (€)
C157 | 100nF | 1206 | SMD | elpro - Elektronik | K-SMD 0,1uF 1206 | 0.11
C158 | 100nF | 1206 | SMD | elpro - Elektronik | K-SMD 0,1uF 1206 | 0.11
C159 | 100nF | 1206 | SMD | elpro - Elektronik | K-SMD 0,1uF 1206 | 0.11
C160 | 100nF | 1206 | SMD | elpro - Elektronik | K-SMD 0,1uF 1206 | 0.11
C161 | 47uF | 7243 | SMD | elpro - Elektronik | T-SMD 20V 47uF BF:D | 0.34
C162 | 47uF | 7243 | SMD | elpro - Elektronik | T-SMD 20V 47uF BF:D | 0.34
C163 | 47uF | 7243 | SMD | elpro - Elektronik | T-SMD 20V 47uF BF:D | 0.34
C164 | 4,7uF | 3528 | SMD | elpro - Elektronik | T-SMD 16V 4,7uF BF:B | 0.15
D1 | BAS32L | SOD-80 | SMD | elpro - Elektronik | BAS32 L SMD | 0.09
D2 | BAS32L | SOD-80 | SMD | elpro - Elektronik | BAS32 L SMD | 0.09
D3 | BAS32L | SOD-80 | SMD | elpro - Elektronik | BAS32 L SMD | 0.09
IC1 | 74HC573 | DIP20 | DIL-IC | elpro - Elektronik | 74 HC 573 | 0.15
IC2 | 74HC573 | DIP20 | DIL-IC | elpro - Elektronik | 74 HC 573 | 0.15
IC3 | 74HC541 | DIP20 | DIL-IC | elpro - Elektronik | 74 HC 541 | 0.19
IC4 | 74HC541 | DIP20 | DIL-IC | elpro - Elektronik | 74 HC 541 | 0.19
IC5 | 74HC541 | DIP20 | DIL-IC | elpro - Elektronik | 74 HC 541 | 0.19
IC6 | 74HC541 | DIP20 | DIL-IC | elpro - Elektronik | 74 HC 541 | 0.19
IC7 | 514400 | SOJ26/20 | SMD-IC | Kessler electronic | 514400-60SOJ | 4.98
IC8 | 514400 | SOJ26/20 | SMD-IC | Kessler electronic | 514400-60SOJ | 4.98
IC9 | 514400 | SOJ26/20 | SMD-IC | Kessler electronic | 514400-60SOJ | 4.98
IC10 | 514400 | SOJ26/20 | SMD-IC | Kessler electronic | 514400-60SOJ | 4.98
IC11 | 28,3751 MHz | Oscillator | DIL-IC | Amiga-Hardware | | 0.00
IC12 | 27C400 | DIP40-6 | DIL-IC | Kickstart-ROM | | 0.00
IC13 | 27C4096 | DIP40-6 | DIL-IC | n.b. | | 0.00
IC14 | GAL16V8-15 | DIP20 | DIL-IC | elpro - Elektronik | GAL 16 V 8 D-15 LP | 0.70
IC15 | 74LS373 | DIP20 | DIL-IC | Reichelt - Elektronik | 74LS 373 | 0.22
IC16 | 74F521 | DIP20 | DIL-IC | Reichelt - Elektronik | 74F 521 | 0.40
IC17 | 74LS245 | DIP20 | DIL-IC | Reichelt - Elektronik | 74LS 245 | 0.20
IC18 | GAL16V8-15 | DIP20 | DIL-IC | elpro - Elektronik | GAL 16 V 8 D-15 LP | 0.70
IC19 | GAL16V8-25 | DIP20 | DIL-IC | elpro - Elektronik | GAL 16 V 8 D-25 LP | 0.70
IC20 | AMBER | PLCC68 | DIL-IC | Amiga-Hardware | | 0.00
IC21 | VIDEO_H | SIP22 | DIL-IC | Amiga-Hardware | | 0.00
IC22 | 74HC157 | DIP16 | DIL-IC | Reichelt - Elektronik | 74HC 157 | 0.15
IC23 | 74HC245 | DIP20 | DIL-IC | Reichelt - Elektronik | 74HC 245 | 0.20
IC24 | 74HC245 | DIP20 | DIL-IC | Reichelt - Elektronik | 74HC 245 | 0.20
IC25 | VIDEO_H | SIP22 | DIL-IC | Amiga-Hardware | | 0.00
IC26 | DENISE | DIP48-6 | DIL-IC | Amiga-Hardware | | 0.00
IC27 | NE564 | DIP16 | DIL-IC | Reichelt - Elektronik | NE 564 DIL | 1.50
IC28 | 74HC04 | DIP14 | 74XXSMD | Reichelt - Elektronik | 74HC 04 | 0.12
IC29 | 74F163 | DIP16 | 74XX | Kessler electronic | 74F163 | 0.84
IC30 | 74F74 | DIP14 | 74XX | Reichelt - Elektronik | 74F 74 | 0.31
IC31 | GAL16V8-25 | DIP20 | DIL-IC | elpro - Elektronik | GAL 16 V 8 D-25 LP | 0.70
IC32 | GAL16V8-25 | DIP20 | DIL-IC | elpro - Elektronik | GAL 16 V 8 D-25 LP | 0.70
IC33 | GAL16V8-15 | DIP20 | DIL-IC | elpro - Elektronik | GAL 16 V 8 D-15 LP | 0.70
IC34 | 27C256 | DIP28-6 | DIL-IC | Reichelt - Elektronik | 27C256-70 | 2.05
IC35 | 74LS245 | DIP20 | DIL-IC | Reichelt - Elektronik | 74LS 245 | 0.20
IC36 | 74LS245 | DIP20 | DIL-IC | Reichelt - Elektronik | 74LS 245 | 0.20
IC37 | MC68030RC | PGA-128 | M68000 | eBay | | 20.00
IC38 | MC68881RC | PGA-68 | M68000 | eBay | | 20.00
IC39 | MSM6242 | DIP18 | DIL-IC | Amiga-Hardware | | 0.00
IC40 | CIA_8520 | DIP40-6 | DIL-IC | Amiga-Hardware | | 0.00
IC41 | PAULA | DIP48-6 | DIL-IC | Amiga-Hardware | | 0.00
IC42 | TL084 | DIP14 | DIL-IC | Reichelt - Elektronik | TL 074 DIL | 0.15

Part | Value | Package | Type | Suggested Source | Item No. (From Source) | Price (€)
IC43 | CIA_8520 | DIP40-6 | DIL-IC | Amiga-Hardware | | 0.00
IC44 | DS1488 | DIP14 | DIL-IC | Kessler electronic | MC1488 | 0.25
IC45 | DS1489 | DIP14 | DIL-IC | Kessler electronic | MC1489 | 0.19
IC46 | 74HC32 | DIP14 | DIL-IC | Reichelt - Elektronik | 74HC 32 | 0.15
IC47 | 7406 | DIP14 | DIL-IC | Reichelt - Elektronik | 74LS 06 | 0.39
IC48 | LM339 | DIP14 | DIL-IC | Reichelt - Elektronik | LM 339 DIL | 0.10
IC49 | 7407 | DIP14 | DIL-IC | Reichelt - Elektronik | 74LS 07 | 0.17
IC50 | GARY | DIP48-6 | DIL-IC | Amiga-Hardware | | 0.00
IC51 | 74F04 | DIP14 | DIL-IC | Reichelt - Elektronik | 74F 04 | 0.22
IC52 | AGNUS | PLCC84 | DIL-IC | Amiga-Hardware | | 0.00
IC53 | GAL20V8-15 | DIP24-3 | DIL-IC | elpro - Elektronik | GAL 20 V 8 B-15 LP | 0.93
IC54 | GAL20V8-15 | DIP24-3 | DIL-IC | elpro - Elektronik | GAL 20 V 8 B-15 LP | 0.93
IC55 | GAL20V8-15 | DIP24-3 | DIL-IC | elpro - Elektronik | GAL 20 V 8 B-15 LP | 0.93
IC56 | GAL20V8-15 | DIP24-3 | DIL-IC | elpro - Elektronik | GAL 20 V 8 B-15 LP | 0.93
IC57 | LSI1024 | PLCC68 | DIL-IC | elpro - Elektronik | ISPLSI 1024-60 LJ PLCC | 10.85
IC58 | 74F245 | SO20L | 74XXSMD | elpro - Elektronik | 74 F 245 SMD | 0.40
IC59 | 74F245 | SO20L | 74XXSMD | elpro - Elektronik | 74 F 245 SMD | 0.40
IC60 | 29F800 | TSOP48 | SMD-IC | RS Components GmbH | 414-9597 | 11.80
IC61 | 48 MHz | Oscillator | DIL-IC | Conrad Elektronik | 158240 | 5.22
IC62 | CY7C1049 | SOJ36/4 | SMD-IC | Kessler electronic | 614008-10J | 3.80
IC63 | CY7C1049 | SOJ36/4 | SMD-IC | Kessler electronic | 614008-10J | 3.80
IC64 | CY7C1049 | SOJ36/4 | SMD-IC | Kessler electronic | 614008-10J | 3.80
IC65 | CY7C1049 | SOJ36/4 | SMD-IC | Kessler electronic | 614008-10J | 3.80
IC66 | CY7C1049 | SOJ36/4 | SMD-IC | Kessler electronic | 614008-10J | 3.80
IC67 | CY7C1049 | SOJ36/4 | SMD-IC | Kessler electronic | 614008-10J | 3.80
IC68 | CY7C1049 | SOJ36/4 | SMD-IC | Kessler electronic | 614008-10J | 3.80
IC69 | CY7C1049 | SOJ36/4 | SMD-IC | Kessler electronic | 614008-10J | 3.80
IC70 | CY7C1049 | SOJ36/4 | SMD-IC | Kessler electronic | 614008-10J | 3.80
IC71 | CY7C1049 | SOJ36/4 | SMD-IC | Kessler electronic | 614008-10J | 3.80
IC72 | CY7C1049 | SOJ36/4 | SMD-IC | Kessler electronic | 614008-10J | 3.80
IC73 | CY7C1049 | SOJ36/4 | SMD-IC | Kessler electronic | 614008-10J | 3.80
IC74 | CY7C1049 | SOJ36/4 | SMD-IC | Kessler electronic | 614008-10J | 3.80
IC75 | CY7C1049 | SOJ36/4 | SMD-IC | Kessler electronic | 614008-10J | 3.80
IC76 | CY7C1049 | SOJ36/4 | SMD-IC | Kessler electronic | 614008-10J | 3.80
IC77 | CY7C1049 | SOJ36/4 | SMD-IC | Kessler electronic | 614008-10J | 3.80
IC79 | 74HC05 | DIP14 | DIL-IC | elpro - Elektronik | 74HC 05 | 0.44
L1 | 150 OHM | 1206 | SMD | Würth Elektronik GmbH | 74279212 | 0.05
L2 | 150 OHM | 1206 | SMD | Würth Elektronik GmbH | 74279212 | 0.05
L3 | 150 OHM | 1206 | SMD | Würth Elektronik GmbH | 74279212 | 0.05
L4 | 150 OHM | 1206 | SMD | Würth Elektronik GmbH | 74279212 | 0.05
L5 | 150 OHM | 1206 | SMD | Würth Elektronik GmbH | 74279212 | 0.05
L6 | 150 OHM | 1206 | SMD | Würth Elektronik GmbH | 74279212 | 0.05
L7 | 150 OHM | 1206 | SMD | Würth Elektronik GmbH | 74279212 | 0.05
L8 | 150 OHM | 1206 | SMD | Würth Elektronik GmbH | 74279212 | 0.05
L9 | 150 OHM | 1206 | SMD | Würth Elektronik GmbH | 74279212 | 0.05
L10 | 150 OHM | 1206 | SMD | Würth Elektronik GmbH | 74279212 | 0.05
L11 | 150 OHM | 1206 | SMD | Würth Elektronik GmbH | 74279212 | 0.05
L12 | 150 OHM | 1206 | SMD | Würth Elektronik GmbH | 74279212 | 0.05
L13 | 150 OHM | 1206 | SMD | Würth Elektronik GmbH | 74279212 | 0.05
L14 | 150 OHM | 1206 | SMD | Würth Elektronik GmbH | 74279212 | 0.05
L15 | 150 OHM | 1206 | SMD | Würth Elektronik GmbH | 74279212 | 0.05
L16 | 150 OHM | 1206 | SMD | Würth Elektronik GmbH | 74279212 | 0.05
L17 | 48 OHM/6A | 1206 | SMD | Würth Elektronik GmbH | 742792117 | 0.05

Part | Value | Package | Type | Suggested Source | Item No. (From Source) | Price (€)
L18 | 48 OHM/6A | 1206 | SMD | Würth Elektronik GmbH | 742792117 | 0.05
L19 | 48 OHM/6A | 1206 | SMD | Würth Elektronik GmbH | 742792117 | 0.05
L20 | 150 OHM | 1206 | SMD | Würth Elektronik GmbH | 74279212 | 0.05
L21 | 150 OHM | 1206 | SMD | Würth Elektronik GmbH | 74279212 | 0.05
L22 | 150 OHM | 1206 | SMD | Würth Elektronik GmbH | 74279212 | 0.05
L23 | 150 OHM | 1206 | SMD | Würth Elektronik GmbH | 74279212 | 0.05
L24 | 10UH | L-10UH | SMD | elpro - Elektronik | LQH 4 N 10 uH | 0.40
L25 | 48 OHM/6A | 1206 | SMD | Würth Elektronik GmbH | 742792117 | 0.05
L26 | 10uH | L-10UH | SMD | elpro - Elektronik | LQH 4 N 10 uH | 0.40
L27 | 150 OHM | 1206 | SMD | Würth Elektronik GmbH | 74279212 | 0.05
L28 | 150 OHM | 1206 | SMD | Würth Elektronik GmbH | 74279212 | 0.05
L29 | 150 OHM | 1206 | SMD | Würth Elektronik GmbH | 74279212 | 0.05
L30 | 150 OHM | 1206 | SMD | Würth Elektronik GmbH | 74279212 | 0.05
L31 | 150 OHM | 1206 | SMD | Würth Elektronik GmbH | 74279212 | 0.05
L32 | 48 OHM/6A | 1206 | SMD | Würth Elektronik GmbH | 742792117 | 0.05
L33 | 150 OHM | 1206 | SMD | Würth Elektronik GmbH | 74279212 | 0.05
L34 | 150 OHM | 1206 | SMD | Würth Elektronik GmbH | 74279212 | 0.05
L35 | 150 OHM | 1206 | SMD | Würth Elektronik GmbH | 74279212 | 0.05
L36 | 150 OHM | 1206 | SMD | Würth Elektronik GmbH | 74279212 | 0.05
L37 | 48 OHM/6A | 1206 | SMD | Würth Elektronik GmbH | 742792117 | 0.05
L38 | 150 OHM | 1206 | SMD | Würth Elektronik GmbH | 74279212 | 0.05
L39 | 150 OHM | 1206 | SMD | Würth Elektronik GmbH | 74279212 | 0.05
L40 | 150 OHM | 1206 | SMD | Würth Elektronik GmbH | 74279212 | 0.05
L41 | 150 OHM | 1206 | SMD | Würth Elektronik GmbH | 74279212 | 0.05
L42 | 150 OHM | 1206 | SMD | Würth Elektronik GmbH | 74279212 | 0.05
L43 | 48 OHM/6A | 1206 | SMD | Würth Elektronik GmbH | 742792117 | 0.05
L44 | 150 OHM | 1206 | SMD | Würth Elektronik GmbH | 74279212 | 0.05
L45 | 150 OHM | 1206 | SMD | Würth Elektronik GmbH | 74279212 | 0.05
L46 | 150 OHM | 1206 | SMD | Würth Elektronik GmbH | 74279212 | 0.05
L47 | 150 OHM | 1206 | SMD | Würth Elektronik GmbH | 74279212 | 0.05
L48 | 150 OHM | 1206 | SMD | Würth Elektronik GmbH | 74279212 | 0.05
L49 | 150 OHM | 1206 | SMD | Würth Elektronik GmbH | 74279212 | 0.05
L50 | 150 OHM | 1206 | SMD | Würth Elektronik GmbH | 74279212 | 0.05
L51 | 150 OHM | 1206 | SMD | Würth Elektronik GmbH | 74279212 | 0.05
L52 | 150 OHM | 1206 | SMD | Würth Elektronik GmbH | 74279212 | 0.05
L53 | 150 OHM | 1206 | SMD | Würth Elektronik GmbH | 74279212 | 0.05
L54 | 150 OHM | 1206 | SMD | Würth Elektronik GmbH | 74279212 | 0.05
L55 | 150 OHM | 1206 | SMD | Würth Elektronik GmbH | 74279212 | 0.05
L56 | 150 OHM | 1206 | SMD | Würth Elektronik GmbH | 74279212 | 0.05
L57 | 48 OHM/6A | 1206 | SMD | Würth Elektronik GmbH | 742792117 | 0.05
L58 | 150 OHM | 1206 | SMD | Würth Elektronik GmbH | 74279212 | 0.05
L59 | 150 OHM | 1206 | SMD | Würth Elektronik GmbH | 74279212 | 0.05
L60 | 150 OHM | 1206 | SMD | Würth Elektronik GmbH | 74279212 | 0.05
L61 | 150 OHM | 1206 | SMD | Würth Elektronik GmbH | 74279212 | 0.05
L62 | 150 OHM | 1206 | SMD | Würth Elektronik GmbH | 74279212 | 0.05
L63 | 150 OHM | 1206 | SMD | Würth Elektronik GmbH | 74279212 | 0.05
L64 | 48 OHM/6A | 1206 | SMD | Würth Elektronik GmbH | 742792117 | 0.05
L65 | 150 OHM | 1206 | SMD | Würth Elektronik GmbH | 74279212 | 0.05
L66 | 150 OHM | 1206 | SMD | Würth Elektronik GmbH | 74279212 | 0.05
L67 | 48 OHM/6A | 1206 | SMD | Würth Elektronik GmbH | 742792117 | 0.05
L68 | 48 OHM/6A | 1206 | SMD | Würth Elektronik GmbH | 742792117 | 0.05
L69 | 150 OHM | 1206 | SMD | Würth Elektronik GmbH | 74279212 | 0.05
L70 | 150 OHM | 1206 | SMD | Würth Elektronik GmbH | 74279212 | 0.05

Part | Value | Package | Type | Suggested Source | Item No. (From Source) | Price (€)
L71 | 150 OHM | 1206 | SMD | Würth Elektronik GmbH | 74279212 | 0.05
L72 | 150 OHM | 1206 | SMD | Würth Elektronik GmbH | 74279212 | 0.05
L73 | 150 OHM | 1206 | SMD | Würth Elektronik GmbH | 74279212 | 0.05
L74 | 150 OHM | 1206 | SMD | Würth Elektronik GmbH | 74279212 | 0.05
L75 | 150 OHM | 1206 | SMD | Würth Elektronik GmbH | 74279212 | 0.05
L76 | 150 OHM | 1206 | SMD | Würth Elektronik GmbH | 74279212 | 0.05
L77 | 150 OHM | 1206 | SMD | Würth Elektronik GmbH | 74279212 | 0.05
L78 | 150 OHM | 1206 | SMD | Würth Elektronik GmbH | 74279212 | 0.05
L79 | 48 OHM/6A | 1206 | SMD | Würth Elektronik GmbH | 742792117 | 0.05
L80 | 150 OHM | 1206 | SMD | Würth Elektronik GmbH | 74279212 | 0.05
L81 | 150 OHM | 1206 | SMD | Würth Elektronik GmbH | 74279212 | 0.05
L82 | 150 OHM | 1206 | SMD | Würth Elektronik GmbH | 74279212 | 0.05
L83 | 150 OHM | 1206 | SMD | Würth Elektronik GmbH | 74279212 | 0.05
L84 | 150 OHM | 1206 | SMD | Würth Elektronik GmbH | 74279212 | 0.05
L85 | 150 OHM | 1206 | SMD | Würth Elektronik GmbH | 74279212 | 0.05
L86 | 150 OHM | 1206 | SMD | Würth Elektronik GmbH | 74279212 | 0.05
L87 | 150 OHM | 1206 | SMD | Würth Elektronik GmbH | 74279212 | 0.05
L88 | 150 OHM | 1206 | SMD | Würth Elektronik GmbH | 74279212 | 0.05
L89 | 150 OHM | 1206 | SMD | Würth Elektronik GmbH | 74279212 | 0.05
L90 | 48 OHM/6A | 1206 | SMD | Würth Elektronik GmbH | 742792117 | 0.05
L91 | 150 OHM | 1206 | SMD | Würth Elektronik GmbH | 74279212 | 0.05
L92 | 150 OHM | 1206 | SMD | Würth Elektronik GmbH | 74279212 | 0.05
L93 | 150 OHM | 1206 | SMD | Würth Elektronik GmbH | 74279212 | 0.05
L94 | 48 OHM/6A | 1206 | SMD | Würth Elektronik GmbH | 742792117 | 0.05
L95 | 48 OHM/6A | 1206 | SMD | Würth Elektronik GmbH | 742792117 | 0.05
L96 | 48 OHM/6A | 1206 | SMD | Würth Elektronik GmbH | 742792117 | 0.05
L97 | 48 OHM/6A | 1206 | SMD | Würth Elektronik GmbH | 742792117 | 0.05
L98 | 48 OHM/6A | 1206 | SMD | Würth Elektronik GmbH | 742792117 | 0.05
L99 | 48 OHM/6A | 1206 | SMD | Würth Elektronik GmbH | 742792117 | 0.05
L100 | 48 OHM/6A | 1206 | SMD | Würth Elektronik GmbH | 742792117 | 0.05
L101 | 48 OHM/6A | 1206 | SMD | Würth Elektronik GmbH | 742792117 | 0.05
L102 | 48 OHM/6A | 1206 | SMD | Würth Elektronik GmbH | 742792117 | 0.05
L103 | 48 OHM/6A | 1206 | SMD | Würth Elektronik GmbH | 742792117 | 0.05
Q1 | 32kHz | Q-UHR | DIL-IC | elpro - Elektronik | Q32,768 kHz TC 38 | 0.45
R1 | 22R | 204 | SMD | elpro - Elektronik | 1206-SMD 1% 22R | 0.15
R2 | 22R | 204 | SMD | elpro - Elektronik | 1206-SMD 1% 22R | 0.15
R3 | 22R | 204 | SMD | elpro - Elektronik | 1206-SMD 1% 22R | 0.15
R4 | 68R | 204 | SMD | elpro - Elektronik | 1206-SMD 1% 68R | 0.15
R5 | 4k7 | 204 | SMD | elpro - Elektronik | 1206-SMD 1% 4,7k | 0.15
R6 | 33R | 204 | SMD | elpro - Elektronik | 1206-SMD 1% 33R | 0.15
R7 | 68R | 204 | SMD | elpro - Elektronik | 1206-SMD 1% 68R | 0.15
R8 | 68R | 204 | SMD | elpro - Elektronik | 1206-SMD 1% 68R | 0.15
R9 | 68R | 204 | SMD | elpro - Elektronik | 1206-SMD 1% 68R | 0.15
R10 | 68R | 204 | SMD | elpro - Elektronik | 1206-SMD 1% 68R | 0.15
R11 | 68R | 204 | SMD | elpro - Elektronik | 1206-SMD 1% 68R | 0.15
R12 | 33R | 204 | SMD | elpro - Elektronik | 1206-SMD 1% 33R | 0.15
R13 | 68R | 204 | SMD | elpro - Elektronik | 1206-SMD 1% 68R | 0.15
R14 | 33R | 204 | SMD | elpro - Elektronik | 1206-SMD 1% 33R | 0.15
R15 | 68R | 204 | SMD | elpro - Elektronik | 1206-SMD 1% 68R | 0.15
R16 | 68R | 204 | SMD | elpro - Elektronik | 1206-SMD 1% 68R | 0.15
R17 | 33R | 204 | SMD | elpro - Elektronik | 1206-SMD 1% 33R | 0.15
R18 | 68R | 204 | SMD | elpro - Elektronik | 1206-SMD 1% 68R | 0.15
R19 | 33R | 204 | SMD | elpro - Elektronik | 1206-SMD 1% 33R | 0.15

Part | Value | Package | Type | Suggested Source | Item No. (From Source) | Price (€)
R20 | 68R | 204 | SMD | elpro - Elektronik | 1206-SMD 1% 68R | 0.15
R21 | 1K | 204 | SMD | elpro - Elektronik | 1206-SMD 1% 1k | 0.15
R22 | 1K | 204 | SMD | elpro - Elektronik | 1206-SMD 1% 1k | 0.15
R23 | 90R9 | 204 | SMD | elpro - Elektronik | 1206-SMD 1% 91R | 0.15
R24 | 1R | 204 | SMD | elpro - Elektronik | 1206-SMD 1% 1R | 0.15
R25 | 47K5 | 204 | SMD | elpro - Elektronik | 1206-SMD 1% 47,5k | 0.15
R26 | 1k | R-POT-G | RCD | elpro - Elektronik | 64 Y 1 k | 0.70
R27 | 10R | 204 | SMD | elpro - Elektronik | 1206-SMD 1% 10R | 0.15
R28 | 1K | 204 | SMD | elpro - Elektronik | 1206-SMD 1% 1k | 0.15
R29 | 150R | 204 | SMD | elpro - Elektronik | 1206-SMD 1% 150R | 0.15
R30 | 10k | 204 | SMD | elpro - Elektronik | 1206-SMD 1% 10k | 0.15
R31 | 1k | 204 | SMD | elpro - Elektronik | 1206-SMD 1% 1k | 0.15
R32 | 5M6 | 204 | SMD | elpro - Elektronik | 1206-SMD 1% 10k | 0.15
R33 | 10k | 204 | SMD | elpro - Elektronik | 1206-SMD 1% 10k | 0.15
R34 | 10k | 204 | SMD | elpro - Elektronik | 1206-SMD 1% 10k | 0.15
R35 | 1k | 204 | SMD | elpro - Elektronik | 1206-SMD 1% 1k | 0.15
R36 | 3K32 | 204 | SMD | elpro - Elektronik | 1206-SMD 1% 3,32k | 0.15
R37 | 390R | 204 | SMD | elpro - Elektronik | 1206-SMD 1% 390R | 0.15
R38 | 1K | 204 | SMD | elpro - Elektronik | 1206-SMD 1% 1k | 0.15
R39 | 470R | 204 | SMD | elpro - Elektronik | 1206-SMD 1% 470R | 0.15
R40 | 390R | 204 | SMD | elpro - Elektronik | 1206-SMD 1% 390R | 0.15
R41 | 470k | 204 | SMD | elpro - Elektronik | 1206-SMD 1% 470k | 0.15
R42 | 10k | 204 | SMD | elpro - Elektronik | 1206-SMD 1% 10k | 0.15
R43 | 10k | 204 | SMD | elpro - Elektronik | 1206-SMD 1% 10k | 0.15
R44 | 1k | 204 | SMD | elpro - Elektronik | 1206-SMD 1% 1k | 0.15
R45 | 390R | 204 | SMD | elpro - Elektronik | 1206-SMD 1% 390R | 0.15
R46 | 390R | 204 | SMD | elpro - Elektronik | 1206-SMD 1% 390R | 0.15
R47 | 470k | 204 | SMD | elpro - Elektronik | 1206-SMD 1% 470k | 0.15
R48 | 1k | 204 | SMD | elpro - Elektronik | 1206-SMD 1% 1k | 0.15
R49 | 1k | 204 | SMD | elpro - Elektronik | 1206-SMD 1% 1k | 0.15
R50 | 10R | 204 | SMD | elpro - Elektronik | 1206-SMD 1% 10R | 0.15
R51 | 10R | 204 | SMD | elpro - Elektronik | 1206-SMD 1% 10R | 0.15
R52 | 10k | 204 | SMD | elpro - Elektronik | 1206-SMD 1% 10k | 0.15
R53 | 10k | 204 | SMD | elpro - Elektronik | 1206-SMD 1% 10k | 0.15
R54 | 2k7 | 204 | SMD | elpro - Elektronik | 1206-SMD 1% 2,7k | 0.15
R55 | 330R | 204 | SMD | elpro - Elektronik | 1206-SMD 1% 330R | 0.15
R56 | 10k | 204 | SMD | elpro - Elektronik | 1206-SMD 1% 10k | 0.15
R57 | 680R | 204 | SMD | elpro - Elektronik | 1206-SMD 1% 680R | 0.15
R58 | 100R | 204 | SMD | elpro - Elektronik | 1206-SMD 1% 100R | 0.15
R59 | 100R | 204 | SMD | elpro - Elektronik | 1206-SMD 1% 100R | 0.15
R60 | 1k | 204 | SMD | elpro - Elektronik | 1206-SMD 1% 1k | 0.15
R61 | 1k | 204 | SMD | elpro - Elektronik | 1206-SMD 1% 1k | 0.15
R62 | 22k | 204 | SMD | elpro - Elektronik | 1206-SMD 1% 22k | 0.15
R63 | 100k | 204 | SMD | elpro - Elektronik | 1206-SMD 1% 10k | 0.15
R64 | 10k | 204 | SMD | elpro - Elektronik | 1206-SMD 1% 100k | 0.15
R65 | 1M | 204 | SMD | elpro - Elektronik | 1206-SMD 1% 1M | 0.15
R66 | 1k | 204 | SMD | elpro - Elektronik | 1206-SMD 1% 1k | 0.15
R67 | 4k7 | 204 | SMD | elpro - Elektronik | 1206-SMD 1% 4,7k | 0.15
R68 | 22R | 204 | SMD | elpro - Elektronik | 1206-SMD 1% 22R | 0.15
R69 | 22R | 204 | SMD | elpro - Elektronik | 1206-SMD 1% 22R | 0.15
R70 | 22R | 204 | SMD | elpro - Elektronik | 1206-SMD 1% 22R | 0.15
R71 | 68R | 204 | SMD | elpro - Elektronik | 1206-SMD 1% 68R | 0.15
R72 | 68R | 204 | SMD | elpro - Elektronik | 1206-SMD 1% 68R | 0.15

Part | Value | Package | Type | Suggested Source | Item No. (From Source) | Price (€)
R73 | 68R | 204 | SMD | elpro - Elektronik | 1206-SMD 1% 68R | 0.15
R74 | 4k7 | 204 | SMD | elpro - Elektronik | 1206-SMD 1% 4,7k | 0.15
R75 | n.b. | 204 | SMD
R76 | 4k7 | 204 | SMD | elpro - Elektronik | 1206-SMD 1% 4,7k | 0.15
R77 | 4k7 | 204 | SMD | elpro - Elektronik | 1206-SMD 1% 4,7k | 0.15
R78 | 4k7 | 204 | SMD | elpro - Elektronik | 1206-SMD 1% 4,7k | 0.15
R79 | 4k7 | 204 | SMD | elpro - Elektronik | 1206-SMD 1% 4,7k | 0.15
R80 | 4k7 | 204 | SMD | elpro - Elektronik | 1206-SMD 1% 4,7k | 0.15
R81 | 4k7 | 204 | SMD | elpro - Elektronik | 1206-SMD 1% 4,7k | 0.15
R82 | 470R | 204 | SMD | elpro - Elektronik | 1206-SMD 1% 470R | 0.15
R83 | 33R | 204 | SMD | elpro - Elektronik | 1206-SMD 1% 33R | 0.15
R84 | 33R | 204 | SMD | elpro - Elektronik | 1206-SMD 1% 33R | 0.15
R85 | 33R | 204 | SMD | elpro - Elektronik | 1206-SMD 1% 33R | 0.15
R86 | 33R | 204 | SMD | elpro - Elektronik | 1206-SMD 1% 33R | 0.15
R87 | 33R | 204 | SMD | elpro - Elektronik | 1206-SMD 1% 33R | 0.15
R88 | 33R | 204 | SMD | elpro - Elektronik | 1206-SMD 1% 33R | 0.15
R89 | 33R | 204 | SMD | elpro - Elektronik | 1206-SMD 1% 33R | 0.15
R90 | 33R | 204 | SMD | elpro - Elektronik | 1206-SMD 1% 33R | 0.15
R91 | 33R | 204 | SMD | elpro - Elektronik | 1206-SMD 1% 33R | 0.15
R92 | 33R | 204 | SMD | elpro - Elektronik | 1206-SMD 1% 33R | 0.15
R93 | 33R | 204 | SMD | elpro - Elektronik | 1206-SMD 1% 33R | 0.15
R94 | 33R | 204 | SMD | elpro - Elektronik | 1206-SMD 1% 33R | 0.15
R95 | 47R | 204 | SMD | elpro - Elektronik | 1206-SMD 1% 47R | 0.15
R96 | 47R | 204 | SMD | elpro - Elektronik | 1206-SMD 1% 47R | 0.15
R97 | 47R | 204 | SMD | elpro - Elektronik | 1206-SMD 1% 47R | 0.15
R98 | 47R | 204 | SMD | elpro - Elektronik | 1206-SMD 1% 47R | 0.15
R99 | 47R | 204 | SMD | elpro - Elektronik | 1206-SMD 1% 47R | 0.15
R100 | 47R | 204 | SMD | elpro - Elektronik | 1206-SMD 1% 47R | 0.15
R101 | 47R | 204 | SMD | elpro - Elektronik | 1206-SMD 1% 47R | 0.15
R102 | 47R | 204 | SMD | elpro - Elektronik | 1206-SMD 1% 47R | 0.15
R103 | 4K7 | 204 | SMD | elpro - Elektronik | 1206-SMD 1% 4,7k | 0.15
R104 | 4K7 | 204 | SMD | elpro - Elektronik | 1206-SMD 1% 4,7k | 0.15
R105 | 4K7 | 204 | SMD | elpro - Elektronik | 1206-SMD 1% 4,7k | 0.15
R106 | 180R | 204 | SMD | elpro - Elektronik | 1206-SMD 1% 180R | 0.15
R107 | 2K2 | 204 | SMD | elpro - Elektronik | 1206-SMD 1% 2,21k | 0.15
R108 | 4k7 | 204 | SMD | elpro - Elektronik | 1206-SMD 1% 4,7k | 0.15
R109 | 4k7 | 204 | SMD | elpro - Elektronik | 1206-SMD 1% 4,7k | 0.15
R110 | 1k | 204 | SMD | elpro - Elektronik | 1206-SMD 1% 1k | 0.15
R111 | 1k | 204 | SMD | elpro - Elektronik | 1206-SMD 1% 1k | 0.15
R112 | 4k7 | 204 | SMD | elpro - Elektronik | 1206-SMD 1% 4,7k | 0.15
R113 | 4k7 | 204 | SMD | elpro - Elektronik | 1206-SMD 1% 4,7k | 0.15
R114 | 4k7 | 204 | SMD | elpro - Elektronik | 1206-SMD 1% 4,7k | 0.15
R115 | 2k21 | 204 | SMD | elpro - Elektronik | 1206-SMD 1% 2,21k | 0.15
R116 | 33R2 | 204 | SMD | elpro - Elektronik | 1206-SMD 1% 33R | 0.15
R117 | 33R2 | 204 | SMD | elpro - Elektronik | 1206-SMD 1% 33R | 0.15
R118 | 1k | 204 | SMD | elpro - Elektronik | 1206-SMD 1% 1k | 0.15
R119 | 4k7 | 204 | SMD | elpro - Elektronik | 1206-SMD 1% 4,7k | 0.15
R120 | 4k7 | 204 | SMD | elpro - Elektronik | 1206-SMD 1% 4,7k | 0.15
R121 | 332R | 204 | SMD | elpro - Elektronik | 1206-SMD 1% 332R | 0.15
R122 | 33R2 | 204 | SMD | elpro - Elektronik | 1206-SMD 1% 33R | 0.15
R123 | 1k | 204 | SMD | elpro - Elektronik | 1206-SMD 1% 1k | 0.15
R124 | 4k7 | 204 | SMD | elpro - Elektronik | 1206-SMD 1% 4,7k | 0.15
R125 | 4k7 | 204 | SMD | elpro - Elektronik | 1206-SMD 1% 4,7k | 0.15

Part | Value | Package | Type | Suggested Source | Item No. (From Source) | Price (€)
R126 | 4k7 | 204 | SMD | elpro - Elektronik | 1206-SMD 1% 4,7k | 0.15
R127 | 4k7 | 204 | SMD | elpro - Elektronik | 1206-SMD 1% 4,7k | 0.15
R128 | 10k | 204 | SMD | elpro - Elektronik | 1206-SMD 1% 10k | 0.15
R129 | 10k | 204 | SMD | elpro - Elektronik | 1206-SMD 1% 10k | 0.15
R130 | 4k7 | 204 | SMD | elpro - Elektronik | 1206-SMD 1% 4,7k | 0.15
R131 | 4k7 | 204 | SMD | elpro - Elektronik | 1206-SMD 1% 4,7k | 0.15
R132 | 4k7 | 204 | SMD | elpro - Elektronik | 1206-SMD 1% 4,7k | 0.15
R133 | 825k | 204 | SMD | elpro - Elektronik | 1206-SMD 1% 825k | 0.15
R134 | 4k7 | 204 | SMD | elpro - Elektronik | 1206-SMD 1% 4,7k | 0.15
RN1 | 4k7 | SIL9 | R-SIL | elpro - Elektronik | NW 09-1 4,7 k | 0.11
RN2 | 10k | SIL5 | R-SIL | elpro - Elektronik | NW 05-1 10 k | 0.11
RN3 | 1k | SIL5 | R-SIL | elpro - Elektronik | NW 05-1 1 k | 0.11
RN4 | 68R | SIL8 | R-SIL | elpro - Elektronik | NW 08-3 68 R | 0.11
RN5 | n.b. | SIL5 | R-SIL
RN9 | 1k | SIL9 | R-SIL | elpro - Elektronik | NW 09-1 1 k | 0.11
RN10 | 4k7 | SIL5 | R-SIL | elpro - Elektronik | NW 05-1 4,7 k | 0.11
RN12 | 4k7 | SIL9 | R-SIL | elpro - Elektronik | NW 09-1 4,7 k | 0.11
RN13 | 4k7 | SIL5 | R-SIL | elpro - Elektronik | NW 05-1 4,7 k | 0.11
RN14 | 470R | SIL9 | R-SIL | elpro - Elektronik | NW 09-1 470 R | 0.11
RN15 | 4k7 | SIL9 | R-SIL | elpro - Elektronik | NW 09-1 4,7 k | 0.11
RN16 | 4k7 | SIL9 | R-SIL | elpro - Elektronik | NW 09-1 4,7 k | 0.11
S1 | JUM-BR | JUMPER | Plug | Reichelt - Elektronik | SL 1X50G 2,54 | 0.68
S2 | JUM-BR | BRIDGE-S | Plug | Reichelt - Elektronik | SL 1X50G 2,54 | 0.68
S3 | JUM-BR | BRIDGE-S | Plug | Reichelt - Elektronik | SL 1X50G 2,54
S4 | SMD-BR | BRIDGE | Plug | Reichelt - Elektronik | SL 1X50G 2,54
S5 | JUM-BR | JUMPER | Plug | Reichelt - Elektronik | SL 1X50G 2,54
S6 | JUM-BR | JUMPER | Plug | Reichelt - Elektronik | SL 1X50G 2,54
S7 | JUM-BR | BRIDGE-S | Plug | Reichelt - Elektronik | SL 1X50G 2,54
SV1 | DISK_INT | ML34 | Flachba | Reichelt - Elektronik | WSL 34G | 0.08
SV2 | ML40 | ML40 | Flachba | Reichelt - Elektronik | WSL 40G | 0.10
T1 | MPF102 | MPF102 | Transistor | Amiga-Hardware | | 0.00
T2 | MPF102 | MPF102 | Transistor | Amiga-Hardware | | 0.00
T3 | 2N3906 | MPF102 | Transistor | elpro - Elektronik | 2 N 3906 | 0.08
U470 | MSM514221 | DIP16 | DIL-IC | Amiga-Hardware | | 0.00
U471 | MSM514221 | DIP16 | DIL-IC | Amiga-Hardware | | 0.00
U472 | MSM514221 | DIP16 | DIL-IC | Amiga-Hardware | | 0.00
U473 | UPD42101 | DIP24-3 | DIL-IC | Amiga-Hardware | | 0.00
U474 | UPD42101 | DIP24-3 | DIL-IC | Amiga-Hardware | | 0.00
U475 | UPD42101 | DIP24-3 | DIL-IC | Amiga-Hardware | | 0.00
U479 | UPD42101 | DIP24-3 | DIL-IC | Amiga-Hardware | | 0.00
X1 | Mouse | M09H_FC | SUBD-A | Amiga-Hardware | | 0.00
X2 | Game | M09H_FC | SUBD-A | Amiga-Hardware | | 0.00
X3 | RGB | M23H_FC | SUBD-A | Amiga-Hardware | | 0.00
X4 | J1 | SL3-1 | Plug | Reichelt - Elektronik | SL 1X50G 2,54
X5 | DIN-8 | DIN-8 | Plug | Reichelt - Elektronik | MABP 8SN | 0.40
X6 | COMP | CINCH-B | Plug | Reichelt - Elektronik | CBP-5 | 0.24
X7 | SL3-1 | SL3-1 | Plug | Reichelt - Elektronik | SL 1X50G 2,54
X9 | RIGHT | CINCH-B | Plug | Reichelt - Elektronik | CBP-5 | 0.24
X10 | LEFT | CINCH-B | Plug | Reichelt - Elektronik | CBP-5 | 0.24
X11 | PRINTER | M25H_FC | SUBD-A | Amiga-Hardware | | 0.00
X12 | RS232 | F25H_FC | SUBD-A | Amiga-Hardware | | 0.00
X13 | PLED | MOL-2 | Plug | elpro - Elektronik | PSG 2,54 2-pol. | 0.08
X14 | DISK | F23H_FC | SUBD-A | Amiga-Hardware | | 0.00

Part | Value | Package | Type | Suggested Source | Item No. (From Source) | Price (€)
X15 | KEYBOARD | RJ10 | Plug | Reichelt - Elektronik | MEBP 4-4S | 0.37
X16 | J2 | SL3-1 | Plug | Reichelt - Elektronik | SL 1X50G 2,54
X17 | SL2 | SL2-1 | Plug | Reichelt - Elektronik | SL 1X50G 2,54
X18 | ZORRO-II | SLOT-100 | Plug | Amiga-Hardware | | 0.00
X19 | FRONT | LKOT-43 | Plug
X20 | EXPANSION | LKOT-43 | Plug
X21 | ROM | SL3-1 | Plug | Reichelt - Elektronik | SL 1X50G 2,54
X22 | PSG-7 | PSG-7 | Plug | Amiga-Hardware | | 0.00
X23 | MOL-4 | MOL-4 | Plug | elpro - Elektronik | PSG 2,54 4-pol. | 0.12
X24 | MOL-4 | MOL-4 | Plug | elpro - Elektronik | PSG 2,54 4-pol. | 0.12
X25 | SL22-2-2 | SL22-2-2 | Plug | Reichelt - Elektronik | BL 2x32W 2,00 | 3.95
X26 | MOL-2 | MOL-2 | Plug | elpro - Elektronik | PSG 2,54 2-pol. | 0.08
IC37 | Socket PGA 128
IC38 | Socket PGA 68
IC20 | Socket PLCC 68 | | | elpro - Elektronik | PLCC 68 | 0.55
IC57 | Socket PLCC 68 | | | elpro - Elektronik | PLCC 68 | 0.55
IC52 | Socket PLCC 84 | | | elpro - Elektronik | PLCC 84 | 0.65
U470 | Socket DIL-16 | | | elpro - Elektronik | PF 16 | 0.22
U471 | Socket DIL-16 | | | elpro - Elektronik | PF 16 | 0.22
U472 | Socket DIL-16 | | | elpro - Elektronik | PF 16 | 0.22
U473 | Socket DIL-24 narrow | | | elpro - Elektronik | PF 24 schmal | 0.28
U474 | Socket DIL-24 narrow | | | elpro - Elektronik | PF 24 schmal | 0.28
U475 | Socket DIL-24 narrow | | | elpro - Elektronik | PF 24 schmal | 0.28
U479 | Socket DIL-24 narrow | | | elpro - Elektronik | PF 24 schmal | 0.28
IC1 | Socket DIL-20 | | | elpro - Elektronik | PF 20 | 0.28
IC2 | Socket DIL-20 | | | elpro - Elektronik | PF 20 | 0.28
IC3 | Socket DIL-20 | | | elpro - Elektronik | PF 20 | 0.28
IC4 | Socket DIL-20 | | | elpro - Elektronik | PF 20 | 0.28
IC5 | Socket DIL-20 | | | elpro - Elektronik | PF 20 | 0.28
IC6 | Socket DIL-20 | | | elpro - Elektronik | PF 20 | 0.28
IC12 | Socket DIL-40 | | | elpro - Elektronik | PF 40 | 0.80
IC13 | Socket DIL-40 | | | elpro - Elektronik | PF 40 | 0.80
IC14 | Socket DIL-20 | | | elpro - Elektronik | PF 20 | 0.28
IC15 | Socket DIL-20 | | | elpro - Elektronik | PF 20 | 0.28
IC16 | Socket DIL-20 | | | elpro - Elektronik | PF 20 | 0.28
IC17 | Socket DIL-20 | | | elpro - Elektronik | PF 20 | 0.28
IC18 | Socket DIL-20 | | | elpro - Elektronik | PF 20 | 0.28
IC19 | Socket DIL-20 | | | elpro - Elektronik | PF 20 | 0.28
IC22 | Socket DIL-16 | | | elpro - Elektronik | PF 16 | 0.22
IC23 | Socket DIL-20 | | | elpro - Elektronik | PF 20 | 0.28
IC24 | Socket DIL-20 | | | elpro - Elektronik | PF 20 | 0.28
IC26 | Socket DIL-48 | | | elpro - Elektronik | PF 48 | 0.8
IC28 | Socket DIL-14 | | | elpro - Elektronik | PF 14 | 0.22
IC29 | Socket DIL-16 | | | elpro - Elektronik | PF 16 | 0.22
IC30 | Socket DIL-14 | | | elpro - Elektronik | PF 14 | 0.22
IC31 | Socket DIL-20 | | | elpro - Elektronik | PF 20 | 0.28
IC32 | Socket DIL-20 | | | elpro - Elektronik | PF 20 | 0.28
IC33 | Socket DIL-20 | | | elpro - Elektronik | PF 20 | 0.28
IC34 | Socket DIL-40 | | | elpro - Elektronik | PF 40 | 0.80
IC35 | Socket DIL-20 | | | elpro - Elektronik | PF 20 | 0.28
IC36 | Socket DIL-20 | | | elpro - Elektronik | PF 20 | 0.28
IC39 | Socket DIL-18 | | | elpro - Elektronik | PF 18 | 0.26
IC40 | Socket DIL-40 | | | elpro - Elektronik | PF 40 | 0.80

Part | Value | Package | Type | Suggested Source | Item No. (From Source) | Price (€)
IC41 | Socket DIL-48 | | | elpro - Elektronik | PF 48 | 0.80
IC42 | Socket DIL-14 | | | elpro - Elektronik | PF 14 | 0.22
IC43 | Socket DIL-40 | | | elpro - Elektronik | PF 40 | 0.80
IC44 | Socket DIL-14 | | | elpro - Elektronik | PF 14 | 0.22
IC45 | Socket DIL-14 | | | elpro - Elektronik | PF 14 | 0.22
IC46 | Socket DIL-14 | | | elpro - Elektronik | PF 14 | 0.22
IC47 | Socket DIL-14 | | | elpro - Elektronik | PF 14 | 0.22
IC48 | Socket DIL-14 | | | elpro - Elektronik | PF 14 | 0.22
IC49 | Socket DIL-14 | | | elpro - Elektronik | PF 14 | 0.22
IC50 | Socket DIL-48 | | | elpro - Elektronik | PF 48 | 0.80
IC51 | Socket DIL-14 | | | elpro - Elektronik | PF 14 | 0.22
IC53 | Socket DIL-24 narrow | | | elpro - Elektronik | PF 24 schmal | 0.28
IC54 | Socket DIL-24 narrow | | | elpro - Elektronik | PF 24 schmal | 0.28
IC55 | Socket DIL-24 narrow | | | elpro - Elektronik | PF 24 schmal | 0.28
IC56 | Socket DIL-24 narrow | | | elpro - Elektronik | PF 24 schmal | 0.28
IC79 | Socket DIL-14 | | | elpro - Elektronik | PF 14 | 0.22

## 7.5 GAL Programming Files

The files that must be programmed in the GAL chips can be found in the zip file on Georg’s homepage containing all the information about this motherboard (http://www.gb97816.homepage.t-online.de/download/a1kboard.zip).

### Following is a list of the files:

IC# | File to Program into the GAL chip
14 | IC14_15ns.jed
18 | IC18_15ns.jed
19 | IC19_25ns.jed
31 | IC31_25ns.jed
32 | IC32_25ns.jed
33 | IC33_15ns.jed
53 | IC53_15ns.jed
54 | IC54_15ns.jed
55 | IC55_15ns.jed
56 | IC56_15ns.jed
57 | IC57_60MHz.jed

## 7.6 Power Supply Pinout

Pin No. | Designation
1 | Tick
2 | +5V
3 | +5V
4 | GND
5 | GND
6 | +12V
7 | -5V

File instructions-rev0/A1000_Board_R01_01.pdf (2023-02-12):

# Bedienungsanleitung A1000 Mainboard Rev. 01


GB

A1000 Mainboard

1 | ALLGEMEINE INFORMATIONEN | 4
2 | ANWENDUNG UND EIGENSCHAFTEN DES A1000 MAINBOARDS | 5
2.1 | Einsatzgebiet | 5
2.2 | Verwendbare Prozessoren | 5
2.3 | Speicherbestückung | 5
2.4 | Boot-ROM | 5
3 | DIE WICHTIGSTEN SCHALTKREISE DES A1000 MAINBOARDS | 6
3.1 | Prozessorbestückung | 6
3.2 | Custom-Chips des A1000 Mainboards | 7
3.2.1 | Gary - IC50 | 7
3.2.2 | Paula - IC41 | 7
3.2.3 | Denise - IC26 | 7
3.2.4 | Amber - IC20 | 7
3.2.5 | Agnus – IC52 | 7
3.2.6 | CIA-A & B – IC40 & IC43 | 8
3.3 | Kickstart-Sockel IC12 & IC13 | 8
3.4 | IDE-Controller | 9
3.5 | Flicker-Fixer | 9
3.5.1 | Unterstütze Bildschirmauflösungen | 10
3.5.2 | PLL-Schaltung abgleichen | 10
3.6 | Uhrenschaltung | 11
3.7 | Programmierbare Logikbausteine | 11
4 | DIE STECKVERBINDUNGEN DES A1000 MAINBOARDS | 12
4.1 | Übersicht zu den Steckverbindungen | 12
4.1.1 | Steckverbindungen an der Rückwand | 12
4.1.2 | Expansionsport | 12
4.1.3 | Frontslot | 12
4.1.4 | Zorro-II-Slot | 12
4.1.5 | LED-Anschlüsse | 13
4.1.6 | Game- und Mausport | 13
4.1.7 | Zwischenstecker für Grafikkartenbetrieb (Board - Revision 01) | 13
4.2 | Pinbelegung der externen Steckverbindungen | 14
4.2.1 | VGA-Ausgang DIN-Buchse | 14
4.2.2 | RGB-Ausgang | 14
4.2.3 | RS232-Schnittstelle | 14
4.2.4 | Externes Diskettenlaufwerk | 15
4.2.5 | Parallele Schnittstelle | 15
4.2.6 | Maus- und Joystick-Port | 15

5 | BEKANNTE ANWENDUNGSPROBLEME | 16
5.1 | Speichereinbindung über den Befehl AddMem | 16
5.2 | Speichereinbindung über einen Boot-ROM Treiber | 16
6 | TECHNISCHE DATEN | 17
6.1 | Adressbelegung | 17
6.2 | Schutzbits | 17
6.3 | Sonstige Daten | 17
6.4 | Konfigurationsreihenfolge | 17
7 | ANHANG | 18
7.1 | Bestückungsdruck B-Seite | 18
7.2 | Bestückungsdruck L-Seite | 19
7.3 | Stromlaufplan | 20

## 1 Allgemeine Informationen

### Es kann keine Verantwortung für Schäden und Verletzungen die durch Bau und Betrieb dieser Schaltung entstehen übernommen werden. Eine Haftung für Schäden aufgrund Nutzung

dieser Unterlagen ist ausgeschlossen.
Für den ordnungsgemäßen Aufbau und den sicheren Betrieb ist alleine der jeweilige Projektbetreiber zuständig.

### Bei Auf- und Einbau, sowie der Inbetriebnahme dieser Schaltung sind unbedingt die Sicherheitsbestimmungen nach VDE einzuhalten. Diese Arbeiten dürfen nur durch fachkundige und

geschulte Personen durchgeführt werden.

### Bei Nichtbeachtung der Vorschriften besteht akute Lebensgefahr für den Betreiber dieser Schaltung!

Für die Fehlerfreiheit der vorliegenden Unterlagen kann natürlich nicht garantiert werden.

Entwickler: | Georg Braun
Kontakt: | gb97816@t-online.de

Lohr, Juni 2008

## 2 Anwendung und Eigenschaften des A1000 Mainboards

### 2.1 Einsatzgebiet

Das A1000 Mainboard ist eine überarbeitete Schaltung für den Amiga 1000 und ist für den Einbau in das A1000 Gehäuse vorgesehen. Es ist mit 2 MB CHIP-RAM, einem IDE-Controller, Flicker-Fixer und einem leistungsfähigerem Prozessorsystem ausgestattet.

Hinweis: Der Front-Slot des A1000 Mainboards entspricht in der Belegung dem seitlichen Expansionsport. Die A1000 256 kB Speichererweiterung kann somit nicht an diesem Mainboard verwendet werden.

### 2.2 Verwendbare Prozessoren

Das A1000 Mainboard kann mit MC68EC030 oder MC68030 Prozessor (CPU) in Taktfrequenzen zwischen 40 MHz und 50 MHz bestückt werden. Die Taktversorgung erfolgt über einen auf dem Mainboard vorgesehenen Quarzoszillator. Dessen Taktfrequenz muss auf die verwendeten Prozessoren angepasst sein.

Zur Erhöhung der Rechenleistung bei Fließkomma-Anwendungen kann das A1000 Mainboard zusätzlich mit einem MC68881/2 Coprozessor (FPU) ausgerüstet werden. Hierzu ist auf der Karte ein 68 poliger PGA-Sockel integriert. Die FPU nutzt hierbei den Takt der CPU und benötigt keinen eigenen Taktoszillator.

### 2.3 Speicherbestückung

Der auf dem A1000 Mainboard integrierte 32 Bit breite und 8 MB große SRAM-Speicher kann wahlweise über die Autokonfiguration in den 24 Bit Adressraum eingebunden werden oder in den 32 Bit Adressraum mit Hilfe des integrierten Boot-ROMs. Eine Erweiterung des RAM-Speichers ist durch den Einsatz einer Speichererweiterung am Front- oder Expansionsport möglich, allerdings wird hier nicht die Geschwindigkeit des 32 Bit-Speichers erreicht.

Durch den Einsatz von SRAM zeichnet sich das A1000 Mainboard trotz fehlender Unterstützung von Burst-Zyklen mit einem sehr hohen Datendurchsatz aus. Ähnliche Werte werden im Vergleich nur bei deutlich höheren Taktfrequenzen erreicht.

### 2.4 Boot-ROM

Auf dem A1000 Mainboard ist zusätzlich ein Boot-ROM zur Einbindung des SRAM-Speichers in den 32 Bit Adressraum integriert. Dieses Boot-ROM ist über ein 1 MB Flash-Speicher realisiert und bietet weiterhin Platz für optionale Software wie z.B. Zusatztreiber. Zur Zeit kann die Logik des Mainboards nur auf 512 kB des Flash-Speichers zugreifen, die Erweiterung des Zugriffs auf 1MB wird zu einem späteren Zeitpunkt umgesetzt. Hierfür muss der PLD-Chip IC57 neu programmiert werden und Jumper S6 erhält die Funktion zur Freigabe des Speicherbereiches.

Das Boot-ROM wird durch stecken des Jumpers S5 aktiviert. Hierdurch wird auf dem A1000 Mainboard die Autokonfiguration im 24 Bit Adressraum abgeschaltet und die automatische Einbindung im 32 Bit Adressraum eingeschaltet. In diesem Betriebsmodus kann auf optionale Anwendersoftware im Boot-ROM zugegriffen werden. Die Lage des Jumpers S5 und S6 ist in Kapitel 3.1 dargestellt.

Bei Verwendung der Autokonfiguration ist das Boot-ROM deaktiviert. Ein Zugriff auf optionale Software im Boot-ROM ist in diesem Betriebsmodus nicht möglich.

Von der Hardwareentwicklung stehen hierzu zwei kleine Programme zur Verfügung:

- Mit dem Programm „lösche BootROM“ kann der Flash-Speicher gelöscht werden und muss vor jeder Modifikation des Boot-ROMs ausgeführt werden.
- Mit dem Programm „Einbindung_RAM“ wird im Boot-ROM ein Treiber zur Einbindung der 8 MB SRAM in den 32 Bit Adressraum installiert.

Der Speicher kann bei aktiviertem Boot-ROM aber auch ohne Softwaremodule über das Programm AddMem in den 32 Bit Adressraum eingebunden werden. Das Boot-ROM darf in dieser Betriebsart keinen Treiber zur RAM-Einbindung enthalten.

## 3 Die wichtigsten Schaltkreise des A1000 Mainboards

### 3.1 Prozessorbestückung

Das A1000 Mainboard kann je nach Anwendung mit Prozessoren unterschiedlicher Geschwindigkeit bestückt werden. Die Karte unterstützt Taktfrequenzen zwischen 40 MHz und 50 MHz. Ein optional zu bestückender MC68881/2 Coprozessor wird auf der Karte über den Takt des MC68030 Prozessors versorgt. Ein zusätzlicher Quarzoszillator ist für den Coprozessor somit nicht erforderlich. Ein bestückter Coprozessor wird von dem A1000 Mainboard automatisch erkannt. Es ist somit keine Jumpereinstellung für einen vorhandenen Coprozessor erforderlich.

Achtung!: Die Prozessoren sind entsprechend der nachfolgenden Abbildung einzusetzen. Bei Nichtbeachtung der Bestückungsausrichtung ist mit einer Beschädigung an der Turbokarte und an den

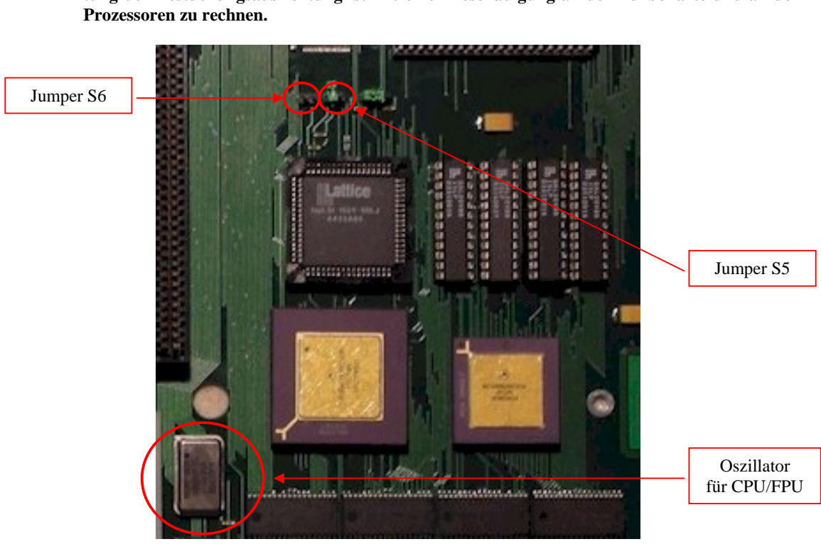
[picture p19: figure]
Prozessoren zu rechnen.; Jumper S6; Jumper S5; Oszillator für CPU/FPU

Der Quarzoszillator ist auf die Taktfrequenz der verwendeten Prozessoren abzustimmen. Bei unterschiedlichen Prozessorgeschwindigkeiten dient als Maß der Prozessor mit der niedrigeren Taktfrequenz.

Hinweis: Von einer Übertaktung der Prozessoren wird abgeraten. Ein stabiler Betrieb und Erhalt der Prozessorlebensdauer kann bei Übertaktung nicht sichergestellt werden.
Oszillatoren mit Taktfrequenzen größer 50 MHz können nicht verwendet werden. Das auf dem Mainboard verwendete Design ist für höhere Taktfrequenzen als 50 MHz nicht geeignet.

### 3.2 Custom-Chips des A1000 Mainboards

Zum Betrieb des A1000 Mainboard werden verschiedene Schaltkreise von Commodore benötigt. Diese sind zum Teil nur noch schwer erhältlich bzw. müssen nicht mehr benötigter Hardware entnommen werden. In der allgemeinen Umgangssprache werden einige dieser Schaltkreise auch Custom-Chips genannt.

Hinweis: Wie bei allen ICs ist natürlich auch bei den nachfolgend genannten Bausteinen auf eine korrekte Bestückung zu achten. Ein Vertauschen der Chips kann diese und die Beschaltung des Mainboard schädigen.

### 3.2.1 Gary - IC50

Gary ist für die Adressdecodierung und die Erzeugung von Steuersignalen und Chip-Select Leitungen zuständig. Finden kann man Gary zum Beispiel im A500, A2000 oder dem A3000 und trägt die Bezeichnung 5719.

### 3.2.2 Paula - IC41

Paula ist für die analoge Signalverarbeitung (Sound, Paddels) und der Steuerung von Floppy und dem RS232-Port zuständig. Paula ist zum Beispiel im A500, A1000, A2000 und dem A3000 zu finden. Paula trägt die Bezeichnung 8364R.

### 3.2.3 Denise - IC26

Denise ist für die Grafikausgabe zuständig und wurde in einer OCS- und einer ECS-Variante hergestellt. Der Unterschied liegt in den darstellbaren Screenmodes.
Auch Denise ist zum Beispiel im A500, A1000, A2000 und dem A3000 zu finden. Die OCS Variante trägt die Bezeichnung 8362R und die leistungsfähigere ECS Variante die Bezeichnung 8373R.
Für das A1000 Mainboard sind beide Varianten verwendbar, die Empfehlung liegt bei der Verwendung der ECS Variante.

### 3.2.4 Amber - IC20

Amber enthält die Steuerungslogik für den Flicker-Fixer und ermöglicht eine Bildschirmausgabe auf Multi-Sync Monitor die für PAL-Screens mit einer Bildwiederholfrequenz von 50 Hz arbeiten können. Amber wurde auf der A2320 Flicker-Fixer Karte und in dem A3000 eingesetzt.

### 3.2.5 Agnus – IC52

Agnus ist für die Steuerung des Chip-RAMs zuständig, stellt die Video-Synchronsignale (HSY, CSY, VSY) zur Verfügung und enthält die Coprozessoren Copper und Blitter. Agnus enthält zusätzlich die komplette DMA-Logik für alle 6 möglichen Quellen. Auf diesem Mainboard sind 2MB Chip-RAM installiert, eine Reduktion auf 1MB ist nicht möglich.
Agnus wurde in vielen Versionen hergestellt, wovon zwei auf dem A1000 Mainboard eingesetzt werden können. Die Versionen 8372B (A3000) und 8375 (A500+) mit der Teilenummer 318069-18 sind nutzbar (geprüft).

Bei Verwendung eines Agnus 8372B kann durch Bestückung von Widerstand R75 und Jumper X17 eine Umschaltung des Start-Bildschirmes zwischen PAL (Jumper X17 offen) und NTSC (Jumper X17 geschlossen) erfolgen. Sind die Bauteile nicht bestückt startet der 8372B mit einem PAL-Bildschirm.

Hinweis: Der Agnus 8375 ist nicht für eine PAL/NTSC Umschaltung ausgelegt. Bei Verwendung dieses Bausteines dürfen Jumper X17 und Widerstand R75 nicht bestückt werden. Die Folge wäre eine Fehlfunktion des Agnus 8375 mit Bildstörungen und instabilen Betriebsverhalten des A1000 Mainboards. Aus diesem Grund sind die genannten Bauteile als „nicht bestückt“ im Stromlaufplan eingezeichnet.

### 3.2.6 CIA-A & B – IC40 & IC43

Die CIAs (Complex Interface Adapter) sind im Amiga zwei Bausteine, die jeweils zwei Hauptaufgaben zu erfüllen haben. Einmal die Verbindung mit der Außenwelt über zwei 8-Bit breite Ports, und zum anderen die interne Zeitmessung über zwei 16-Bit und einen 24-Bit Timer. Für die serielle Datenübertragung enthält der Baustein noch einen entsprechenden Port (SP), welcher bidirektional ist. Die CIAs tragen die Bezeichnung 8250 und sind zum Beispiel im A500, A1000, A2000 oder dem A3000 eingesetzt worden.

Über den Jumper X16 kann dem CIA IC40 das TICK-Signal (Jumper rechts) oder das /VSYNC-Signal (Jumper links) zugeführt werden. Dieses 50Hz Signal wird für die interne Signalverarbeitung des Custom-Chip-Systems benötigt und wurde beim A1000 über das Netzteil als TICK-Signal zur Verfügung gestellt. Bei den nachfolgenden Modell wurde dann das /VSYNC-Signal benutzt. Das A1000 Mainboard arbeitet mit beiden Einstellungen. Sollte das Netzteil kein TICK-Signal zur Verfügung stellen (z.B. Austauschnetzteil) ist die Einstellung /VSYNC zwingend erforderlich.

Jumper X16

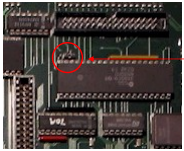
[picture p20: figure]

### 3.3 Kickstart-Sockel IC12 & IC13

Zum Betrieb des A1000 Mainboard wird ein Betriebssystem, nachfolgend Kickstart genannt, benötigt. Das Kickstart unterliegt Urheberrechten und darf weder kopiert noch verbreitet werden. Auf dem A1000 Mainboard sind zwei Sockel zur Aufnahme von Kickstart-Speichern enthalten.

- Sockel IC12 zur Aufnahme eines originalen Kickstart-ROMs
- Sockel IC13 zur Aufnahme eines 256 kB x 16 EPROMs (z.B. der Typ 27C4096)

Die Auswahl des Sockel ist über den Jumper X21 möglich. Rechts gesteckt ist IC13 (EPROM) aktiviert, links gesteckt der ROM-Sockel IC12.
Der EPROM-Sockel ist für den zum Eigengebrauch modifizierte Kickstarts gedacht. Auch hier ist für den Betrieb natürlich der Besitz eines originalen ROMs erforderlich.

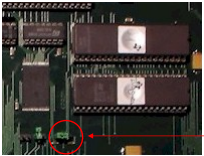
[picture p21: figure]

ROM

EPROM

Jumper X21

### 3.4 IDE-Controller

Das A1000 Mainboard beinhaltet einen Nachbau des AT-BUS 2008 IDE-Controllers von BSC. Er ist ohne RAM-Option ausgeführt und enthält nur die IDE-Funktionen der Originalschaltung. Zum Betrieb des autobootfähigen IDE-Controllers wird der dazugehörige Treiber AT6.10 benötigt. Er wird im EPROM IC34 des Typs 27C256 abgelegt. Ein Image des Treibers ist im Internet als Hex-File unter amiga.resource zu finden. Optional kann das im Aminet erhältliche OKTAPUS-Device eingesetzt werden. Es erweitert die Funktionalität des IDE-Controllers.

Hinweis: Es handelt sich hierbei annähernd um die Originalschaltung von BSC. Aufgrund fehlender Kenntnisse zum Device können bestehende Mängel nicht behoben werden. Bei nicht lösbaren Problem empfehle ich die Verwendung eines externen IDE-Controllers wie z.B. dem Phönix-Buddha.

Auf dem A1000 Mainboard sind zwei Steckverbindungen für den Anschluss von IDE-Geräten in 40pol. und 44pol. Ausführung. Eine Nutzung im Master-Slave-Betrieb ist möglich, jedoch vertragen sich nicht alle Gerätekombinationen. Der IDE-Controller ist durch stecken von Jumper S2 abschaltbar.

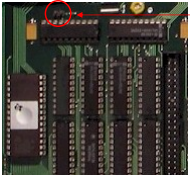
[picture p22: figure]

Jumper S2

IC34

### 3.5 Flicker-Fixer

Der Flicker-Fixer des A1000 Mainboards ist ein Nachbau des A2320 Display Enhancer von Commodore. Die Schaltung zeigt die Stabilität der Originalschaltung obwohl sie deren nicht exakt entspricht. Aufgrund fehlender Unterlagen wurden die Stromlaufpläne des A3000 als Grundlage benutzt. Die PLL-Beschaltung entspricht jedoch exakt der A2320 Schaltung. Der Einsatz liegt in der Verdopplung der Zeilenfrequenz zum Anschluss eines Multisync-Monitors an das A1000 Mainboard. Weiterhin kann die Schaltung das Flimmern des Bildes bei Interlace-Auflösungen unterdrücken.

Der Ausgang des Flicker-Fixers ist auf die 8pol. DIN-Buchse gelegt. Durch diese Maßnahme ist eine Bearbeitung des Schirmbleches und der Gehäuserückwand nicht erforderlich. Die Gehäuseteile können somit im Originalzustand belassen werden.
Nachteilig ist die Anfertigung eines VGA-Kabels mit einseitig angebrachtem DIN-Stecker. Nachfolgend die Verbindungsliste:
15 pol. VGA-Stecker | 8 pol. DIN-Stecker | Signal
Pin 1 | Pin 2 | R (analog)
Pin 2 | Pin 3 | G (analog)
Pin 3 | Pin 4 | B (analog)
Pin 13 | Pin 7 | /HSYNC
Pin 9 | - | nicht belegt
Pin 14 | Pin 8 | /VSYNC
Pin 15 | - | nicht belegt

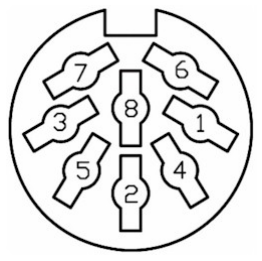
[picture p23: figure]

Pin 4, 5, 6, 7, 8,10, 11, 12 | Pin 1, 5, 6 + Schirm | GND | Blick auf die DIN-Buchse

### 3.5.1 Unterstütze Bildschirmauflösungen

Die Phönix VGA unterstützt folgende Bildschirmauflösungen in NTSC oder PAL Norm. Hierbei werden auch die neueren Bildschirmauflösungen des ECS Chipsatz verarbeitet. Weiterhin kann die Phönix VGA über einen Bypass-Schalter (Jumper S1) deaktiviert werden.

OCS Chipsatz:
- NTSC HighRes | 640 x 200 | 60 Hz 15,734 kHz | Anhebung auf 31,46 kHz
- NTSC HighRes Interlace 640 x 400 | 60 Hz 15,734 kHz | 31,46 kHz, flimmerfrei
- NTSC LowRes | 320 x 200 | 60 Hz 15,734 kHz | Anhebung auf 31,46 kHz
- NTSC LowRes Interlace 320 x 400 | 60 Hz 15,734 kHz | 31,46 kHz, flimmerfrei
- PAL HighRes | 640 x 256 | 50 Hz 15,625 kHz | Anhebung auf 31,25 kHz
- PAL HighRes Interlace 640 x 512 | 50 Hz 15,625 kHz | 31,25 kHz, flimmerfrei
- PAL LowRes | 320 x 256 | 50 Hz 15,625 kHz | Anhebung auf 31,25 kHz
- PAL LowRes Interlace | 320 x 512 | 50 Hz 15,625 kHz | 31,25 kHz, flimmerfrei

ECS Chipsatz:
- Multiscan Productivity | 640 x 480 | 60 Hz 31,46 kHz | (automatischer Bypass)
- Multiscan Productivity | 640 x 960 | 60 Hz 31,46 kHz | (automatischer Bypass)
- NTSC SuperHighRes | 1280 x 200 | 60 Hz 15,734 kHz | Anhebung auf 31,46 kHz
- NTSC SuperHighRes Int. 1280 x 400 | 60 Hz 15,734 kHz | 31,46 kHz, flimmerfrei
- PAL SuperHighRes | 1280 x 256 | 50 Hz 15,625 kHz | Anhebung auf 31,25 kHz
- PAL SuperHighRes Int. 1280 x 512 | 50 Hz 15,625 kHz | 31,25 kHz, flimmerfrei
- Volle Unterstützung der Overscan Auflösungen

### 3.5.2 PLL-Schaltung abgleichen

Die PLL-Schaltung des Flicker-Fixers muss auf die Taktfrequenz des A1000 Mainboards abgeglichen werden. Hierzu ist der Jumper X7 links zu stecken. Die PLL-Schaltung wird dadurch in den Open-Loop Betrieb versetzt. Anschließend kann der Computer eingeschaltet werden. Mit Hilfe des Trimmkondensators C59 ist ein stehendes Bild einzustellen. Anschließend ist der Jumper X7 rechts zu stecken. Hierdurch wird die Regelung (Close-Loop) des PLL-Kreises eingeschaltet. Eine Feinjustage ist über den Trimmwiderstand R26 möglich. Mit ihm wird die Phasenlage der PLL-Ausgangsfrequenz justiert. Feine Ausreißer in den Zeilen können hiermit beseitigt werden. Die Einstellarbeiten sind bei warmer Elektronik durchzuführen, nach dem Einschalten sind mindestens 15 Minuten Aufwärmzeit abzuwarten. Hierbei ist ein gewisses Fingerspitzengefühl erforderlich und eine Kontrolle nach einigen Betriebsstunden sinnvoll.
Wird die Bypass-Funktion der Schaltung benötigt muss noch der Jumper S1 über einen Schalter im Gehäuse zugänglich gemacht werden.

Für die Abgleicharbeiten kann auch die A2320 Installationsdiskette benutzt werden. Je nach verwendetem Betriebssystem muss jedoch eventuell von der Installationsdiskette gebootet werden. Die hierüber zur Verfügung stehenden Justagebilder eigenen sich hervorragenden zum Feinabgleich des PLL-Schaltkreises.

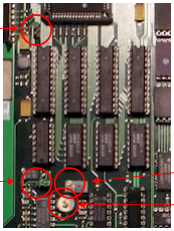
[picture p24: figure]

R26

C59

Jumper S1

Jumper X7

### 3.6 Uhrenschaltung

Das A1000 Mainboard beinhaltet einen Uhrenschaltkreis zur Realisierung einer Echtzeituhr. Die Schaltung kann über den Trimmkondensator C80 in der Ganggenauigkeit justiert werden.
Die Uhrenschaltung ist über eine Batterie zum Datenerhalt gepuffert. Als Batterie wird die Verwendung einer 3,6 V Lithium-Batterie mit mind. 1200mAh empfohlen. Aufgrund der installierten Ladeschaltung für den alternativen Einsatz von einem 3,6 V NC-Akku muss die Lithium-Batterie eine ausreichende Rückstromfestigkeit aufweisen und somit entsprechend dimensioniert sein

C80

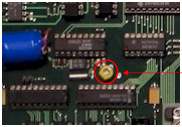
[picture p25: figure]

### 3.7 Programmierbare Logikbausteine

Das A1000 Mainboard beinhaltet eine Vielzahl an programmierbaren Logikbausteinen in Form von GALs und einem CPLD. Die zur Programmierung erforderlichen jedec-Files sind im Download zum A1000 Mainboard enthalten.
Für den Nachbau des A1000 Mainboards wird ein Gerät zur Programmierung von GAL- bzw. CPLD-Bausteinen benötigt.

Achtung!: Eine Verwechslung der Bausteine ist zu vermeiden, eine Schädigung am Mainboard kann in diesem Fall nicht ausgeschlossen werden.

## 4 Die Steckverbindungen des A1000 Mainboards

### 4.1 Übersicht zu den Steckverbindungen

### 4.1.1 Steckverbindungen an der Rückwand

Das A1000 Mainboard beinhaltet auf der Rückwand alle Steckverbindungen des A1000. Die Belegung der Stecker hält sich an die Belegungen des Originals bzw. des A1000-Phönix und bedürfen keiner weiteren Erklärung. Als Ausnahme ist hier nochmals die DIN-Buchse zu erwähnen, sie ist mit den Signalen des Flicker-Fixers belegt.

Achtung!: Einige der Steckverbindungen sind mit den Versorgungsspannungen des Boards belegt. Das stecken oder ziehen der Steckverbindungen bei eingeschaltetem Rechner ist zu vermeiden. Bei Nichtbeachtung sind Schäden am Mainboard und am externen Gerät nicht ausgeschlossen.

### 4.1.2 Expansionsport

Auch der seitlich rechts angebrachte 86pol. Expansionsport entspricht in der Belegung dem des A1000. Als Ausnahme ist auf Pin 5 zusätzlich der 7 MHz Systemtakt aufgelegt. Im Gegensatz zum Phönix-Board ist der 28 MHz Systemtakt nicht aufgelegt.

### 4.1.3 Frontslot

Der auf der Frontseite angebrachte 86pol. Steckverbinder ist in der Belegung zum Expansionsport identisch. Im Vergleich zum Phönix-Board sind hier alle Signale aufgelegt. Zur Überbrückung der Konfigurationsleitung bei unbenutztem Frontslot ist der Jumper S3 zu stecken. Ohne diesen Jumper und ohne gesteckte Erweiterungskarte im Frontslot ist die Konfigurationsleitung unterbrochen und alle nachfolgenden Hardwarekomponenten werden nicht erkannt.
Alternativ kann Widerstand R128 nicht bestückt und Jumper S3 durch einen 1k5 Widerstand ersetzt werden. Bei Nutzung des Frontslot muss der Rechner dann nicht geöffnet werden um Jumper S3 zu ziehen.

Achtung!: Bei gesteckter Erweiterung und gesetztem Jumper werden die Konfig.-Signale der Erweiterung überbrückt. Die Erweiterung wird nicht erkannt und kann eventuell beschädigt werden.

### 4.1.4 Zorro-II-Slot

Auf dem A1000 Mainboard ist weiterhin ein Zorro-II-Slot eingebaut. Dieser sitzt auf der gleichen Position wie beim Phönix-Board, ist im Gegensatz dazu aber als Zorro-II ausgeführt. D.h. alle Zorro-II Signale sind auf dieser Steckverbindung auch aufgelegt. Zur Überbrückung der Konfigurationsleitung bei unbenutztem Zorro-II-Slot ist der Jumper S7 zu stecken. Ohne diesen Jumper und ohne gesteckte Erweiterungskarte ist die Konfigurationsleitung unterbrochen und alle nachfolgenden Hardwarekomponenten werden nicht erkannt.

Achtung!: Bei gesteckter Erweiterung und gesetztem Jumper werden die Konfig.-Signale der Erweiterung überbrückt. Die Erweiterung wird nicht erkannt und kann eventuell beschädigt werden.

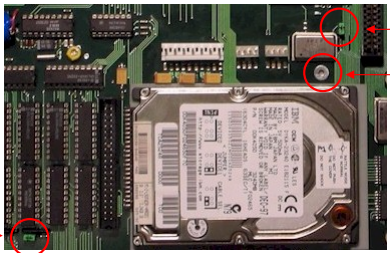
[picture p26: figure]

Bohrung f. HD-Befestigung

Jumper S7

Jumper S3

### 4.1.5 LED-Anschlüsse

An die Steckverbindungen X13 und X26 können LEDs für Power und HD-Zugriff angeschlossen werden. X13 ist für den Anschluss der Power-LED und X26 für die HD-LED.

X13 Power- LED / X26 HD-LED
Pin | LED-Anschluss
1 | A
2 | K

### 4.1.6 Game- und Mausport

An die seitlich angebrachten 9pol. D-SUB Stecker kann eine Maus und Joystick angeschlossen werden. Die beiden Anschlüsse entsprechen den vom A500 bekannten Ports. Auf dem A1000 Mainboard kann der Port zum Betrieb eines Lightpens über den Jumper X4 ausgewählt werden. Diese Funktion ist z.B. auch auf dem Phönix-Board umgesetzt.
Sitzt der Jumper X4 in der oberen Position ist der Game-Port für den Lightpen ausgewählt, sitzt der Jumper in der unteren Position wird der Maus-Port verwendet.

### 4.1.7 Zwischenstecker für Grafikkartenbetrieb (Board - Revision 01)

Für den Betrieb einer Grafikkarte mit Signalumschaltung wurde ein 14 pol. Flachbandstecker auf dem A1000 Mainboard vorgesehen. Bei dem Betrieb ohne Grafikkarte müssen die Kontakte 3 – 4, 5 – 6, 7 – 8, 11 – 12 und 13 – 14 über Jumper miteinander verbunden werden. Ansonst ist die Signalausgabe des Flicker-Fixers zur DIN-Buchse unterbrochen.

Bei Verwendung einer Grafikkarte mit Signalumschaltung kann diese über den Zwischenstecker in den Signalweg eingeschleift werden. Eine Umschaltung der Signalausgabe über die DIN-Buchse zwischen Flicker-Fixer und Grafikkarte erfolgt dann mit Öffnung eines Grafikkartenbildschirms.

SV3 Flachband-Stecker für Grafikkarte
Pin | Signal | Pin | Signal
1 | GND | 8 | B (analog) GRAKA-OUT
2 | GND | 9 | GND
3 | R (analog) GRAKA-IN | 10 | GND
4 | R (analog) GRAKA-OUT | 11 | /VSYNC GRAKA-IN
5 | G (analog) GRAKA-IN | 12 | /VSYNC GRAKA-OUT
6 | G (analog) GRAKA-OUT | 13 | /HSYNC GRAKA-IN
7 | B (analog) GRAKA-IN | 14 | /HSYNC GRAKA-OUT

Stecker SV3

Jumper X4

### 4.2 Pinbelegung der externen Steckverbindungen

### 4.2.1 VGA-Ausgang DIN-Buchse

### 8 pol. DIN-Buchse

Pin | Signal
1 | GND
2 | R (analog)
3 | G (analog)
4 | B (analog)
5 | GND
6 | GND
7 | /HSYNC
8 | /VSYNC
Schirm | GND

### 4.2.2 RGB-Ausgang

### 23 pol. D-SUB-Stecker

Pin | Signal | Pin | Signal
1 | n.c. | 14 | PSWB
2 | n.c. | 15 | /CCKB
3 | R (analog) | 16 | GND
4 | G (analog) | 17 | GND
5 | B (analog) | 18 | GND
6 | DI | 19 | GND
7 | DB | 20 | GND
8 | DG | 21 | -5 V
9 | DR | 22 | +12 V
10 | /CSYNC | 23 | +5 V
11 | /HSYNC
12 | /VSYNC
13 | GND

### 4.2.3 RS232-Schnittstelle

### 25 pol. D-SUB-Buchse

Pin | Signal | Pin | Signal
1 | GND | 14 | -5 V
2 | TxD | 15 | Audio-O
3 | RxD | 16 | Audio-I
4 | RTS | 17 | E-Clock
5 | CTS | 18 | /INT2
6 | DSR | 19 | n.c.
7 | GND | 20 | DTR
8 | CD | 21 | +5 V
9 | n.c. | 22 | n.c.
10 | n.c. | 23 | +12 V
11 | n.c. | 24 | /CCKQ
12 | n.c. | 25 | /SRESET
13 | n.c.

### 4.2.4 Externes Diskettenlaufwerk

### 23 pol. D-SUB-Buchse

Pin | Signal | Pin | Signal
1 | /RDY | 13 | /SIDE
2 | /DKRD | 14 | /WPRO
3 | GND | 15 | /TRK0
4 | GND | 16 | /DWE
5 | GND | 17 | /DWD
6 | GND | 18 | /STEP
7 | GND | 19 | DIR
8 | /MTRXD | 20 | /SEL3
9 | /SEL2 | 21 | /SEL1
10 | /DRESET | 22 | /INDEX
11 | /CHNG | 23 | +12 V
12 | +5 V

### 4.2.5 Parallele Schnittstelle

### 25 pol. D-SUB-Stecker

Pin | Signal | Pin | Signal
1 | /STROBE | 14 | GND
2 | D0 | 15 | GND
3 | D1 | 16 | GND
4 | D2 | 17 | GND
5 | D3 | 18 | GND
6 | D4 | 19 | GND
7 | D5 | 20 | GND
8 | D6 | 21 | GND
9 | D7 | 22 | GND
10 | /ACK | 23 | +5 V
11 | /BUSY | 24 | n.c.
12 | POUT | 25 | /IORESET
13 | SEL

### 4.2.6 Maus- und Joystick-Port

### 9 pol. D-SUB-Stecker (Maus)

Pin | Signal | Pin | Signal
1 | MOUSE V | 6 | BUTTON 1
2 | MOUSE H | 7 | +5 V
3 | MOUSE VQ | 8 | GND
4 | MOUSE HQ | 9 | BUTTON 2
5 | BUTTON 3

### 9 pol. D-SUB-Stecker (Joystick)

Pin | Signal | Pin | Signal
1 | /FORWARD | 6 | /FIRE
2 | /BACK | 7 | +5 V
3 | /LEFT | 8 | GND
4 | /RIGHT | 9 | POT Y
5 | POT X

## 5 Bekannte Anwendungsprobleme

### 5.1 Speichereinbindung über den Befehl AddMem

Bei einer Einbindung des 32Bit-SRAMs über den Befehl AddMem ist ein drastischer Einbruch in der Zugriffsgeschwindigkeit des IDE-Controllers gegenüber einer Speichereinbindung durch die Autokonfiguration zu bemerken.
Ursache ist das der Zugriff des IDE-Interfaces über das CHIP-RAM erfolgt und das wichtige Teile des Betriebssystems im CHIP-RAM abgelegt sind. Abhilfe kann nur durch den Einbau von zusätzlichem autokonfigurierendem FAST-RAM geschaffen werden bzw. durch eine Einbindung des 32Bit-SRAMs beim Systemstart bevor das Betriebssystem geladen wird (Boot-ROM Treiber).

### 5.2 Speichereinbindung über einen Boot-ROM Treiber

Bei einer Einbindung des 32Bit-SRAMs über einen Boot-ROM Treiber verbleibt der visuelle Eindruck einer geringeren Zugriffsgeschwindigkeit bei Fensteraufbau und Dateizugriffen.
Ursache ist ein ungünstiger Eintrag für das Filesystem der Festplatte. Mit Hilfe der HD-Toolbox kann durch Änderung des Eintrages der File-System-Mask von 0X00FFFFFE (Grundeinstellung) auf 0XFFFFFFFC dieser Eindruck deutlich reduziert bzw. beseitigt werden.
1. HD-Toolbox öffnen
2. „Partition Drive“ anwählen
3. Partition und „Advanced Optionen“ anwählen
4. “Change File System for Partition” anwählen
5. den Eintrag „Mask = 0XFFFFFFFC“ tätigen und Menü mit „Ok“ verlassen
6. Partition Menü mit „Ok“ verlassen
7. Änderung durch „Save Changes to Drive“ abspeichern und HD-Toolbox mit „Exit“ beenden
8. System neu booten

Bei dem Einsatz von mehreren Partitionen sind die Schritte 3 bis 5 entsprechend zu wiederholen. Weitere Angaben zum Umgang mit der HD-Toolbox sind der HD-Toolbox Bedienungsanleitung zu entnehmen.

Achtung!: Fehlerhafte Eingaben in der HD-Toolbox können Datenverlust zur Folge haben. Vor Manipulation der HD-Einträge ist eine Sicherung der Daten vorzunehmen.

## 6 Technische Daten

### 6.1 Adressbelegung

- RAM 24 Bit Adressraum: | Adresse $200000 bis $9FFFFF
- RAM 32 Bit Adressraum: | Adresse $1200000 bis $19FFFFF
- Boot-ROM: | Adresse $F00000 bis $F7FFFF

### 6.2 Schutzbits

Das Flash (Boot-ROM) der Turbokarte ist gegen unbeabsichtigte Schreib- und Löschvorgänge geschützt. Weiterhin können bei aktiviertem Boot-ROM die Konfigurationsdaten ausgelesen werden. Durch einen Schreibzugriff auf die nachfolgend aufgeführten Adressen werden die genannten Operationen freigeschaltet. Die Adressen können mit einem beliebigen Datenwort beschrieben werden.

- Konfig.-Daten lesen: | Adresse $1FE0004
- Flash schreiben / löschen: | Adresse $1FE0002
- Rücksetzen Schutzbits: | Adresse $1FE0000

### 6.3 Sonstige Daten

- Abmessung: | 314 x 341 x 23 mm (L x B x H)
- Maximale Taktfrequenz: | 50 MHz
- Minimale Taktfrequenz: | 40 MHz
- CPU: | MC68030 oder MC68EC030
- FPU: | MC68881 oder MC68882
- SRAM: | 8 MB; Zugriff in zwei Taktzyklen

### 6.4 Konfigurationsreihenfolge

- 1 | Frontslot | z.B. IDE-Controller, Speichererweiterung
- 2 | IDE-Controller
- 3 | Zorro-Slot | z.B. SCSI-, IDE-, Schnittstelleninterfaces
- 4 | 32Bit-RAM
- 5 | Expansionsport | z.B. IDE-Controller, Speichererweiterung

## 7 Anhang

### 7.1 Bestückungsdruck B-Seite

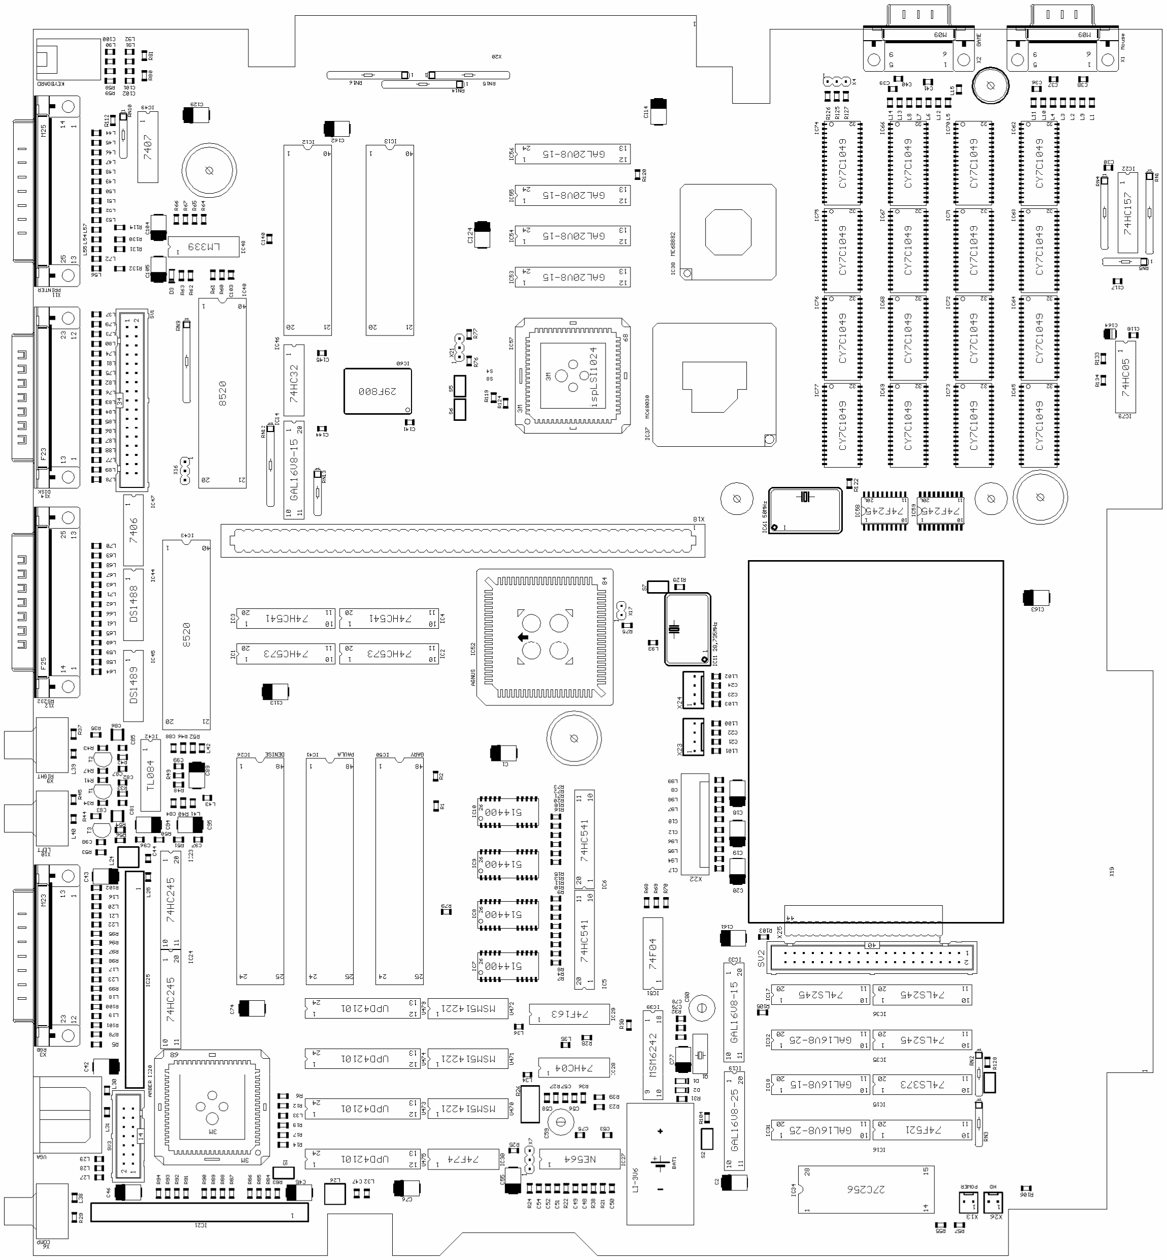
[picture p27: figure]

### 7.2 Bestückungsdruck L-Seite

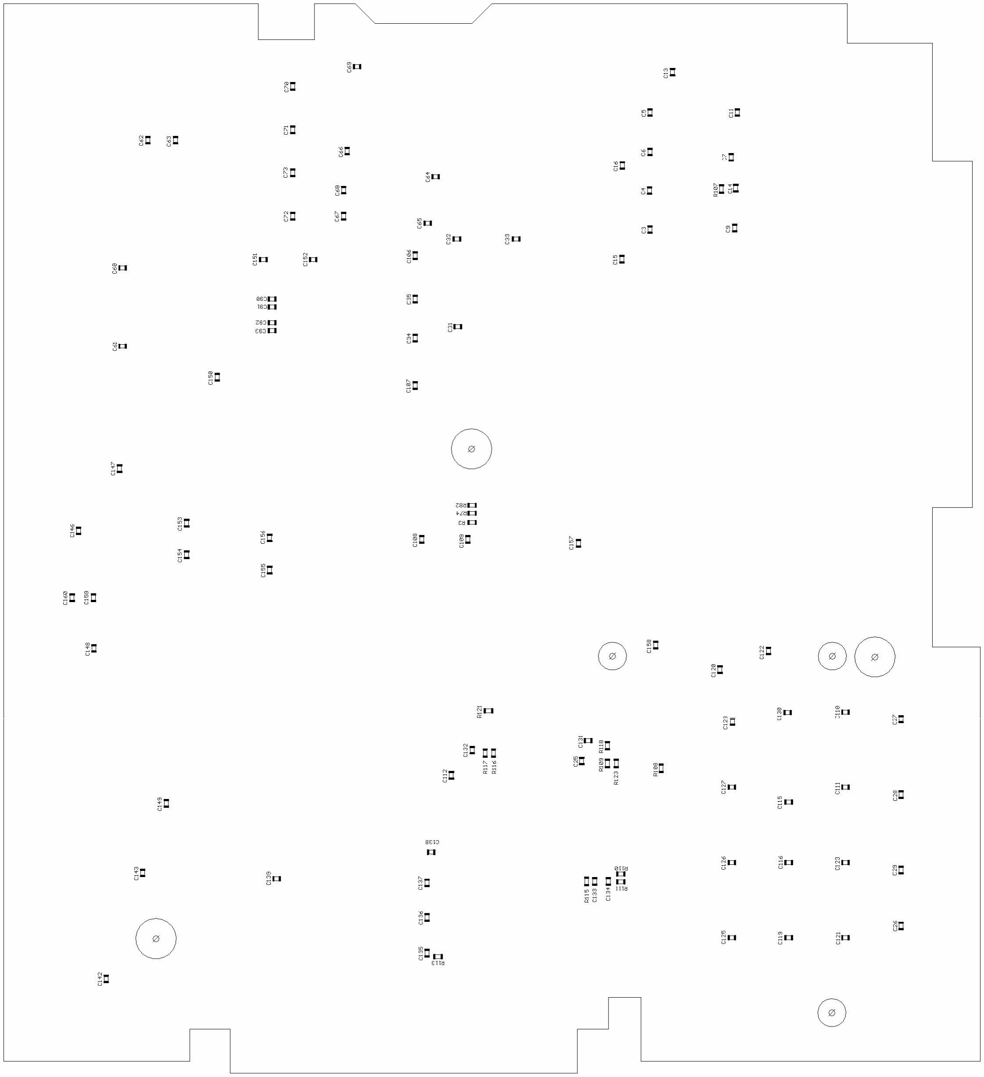
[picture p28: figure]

### 7.3 Stromlaufplan

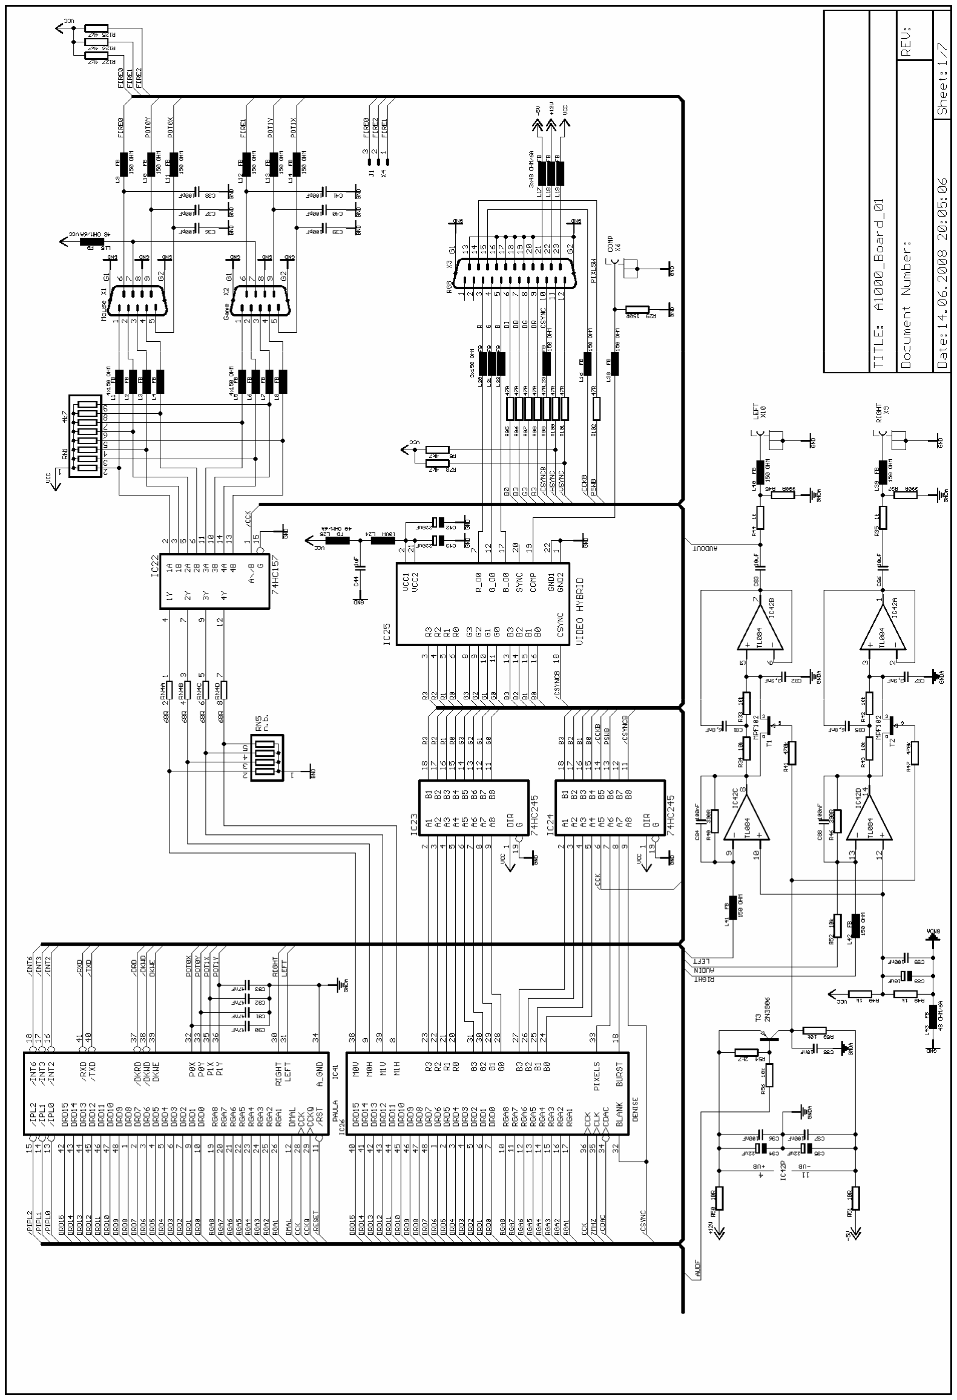
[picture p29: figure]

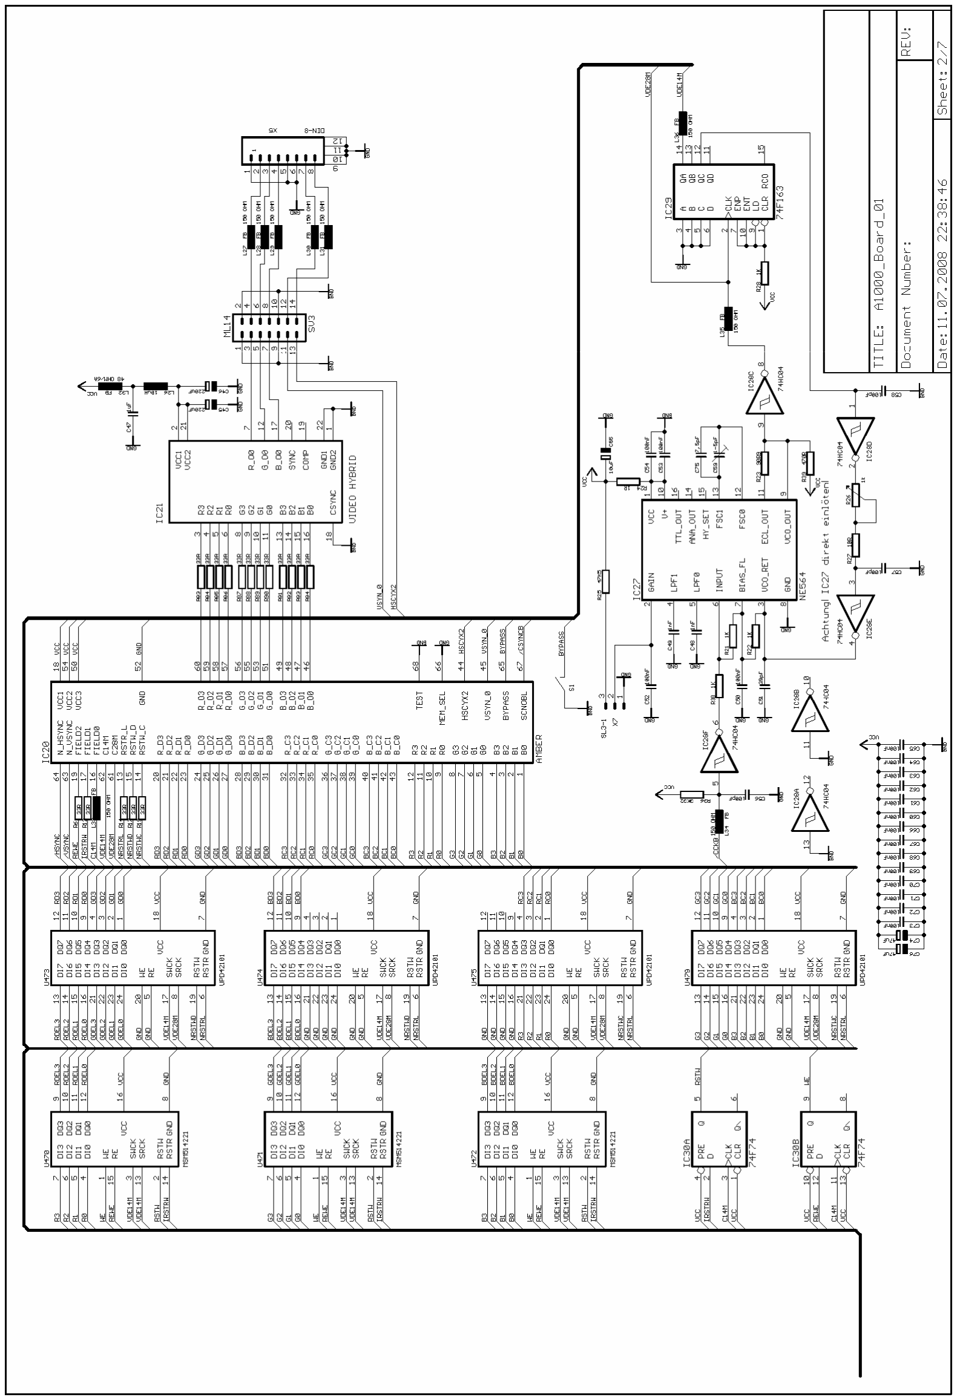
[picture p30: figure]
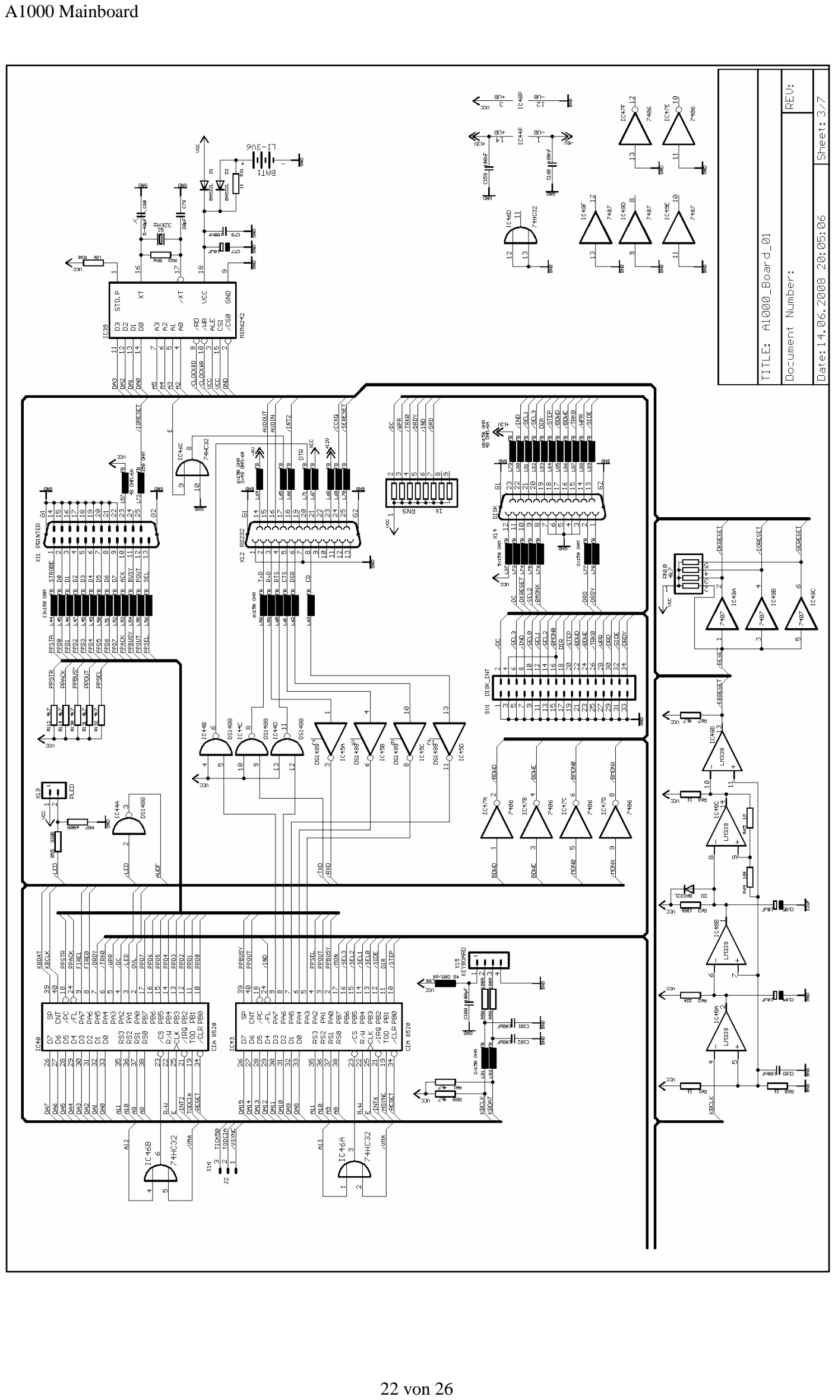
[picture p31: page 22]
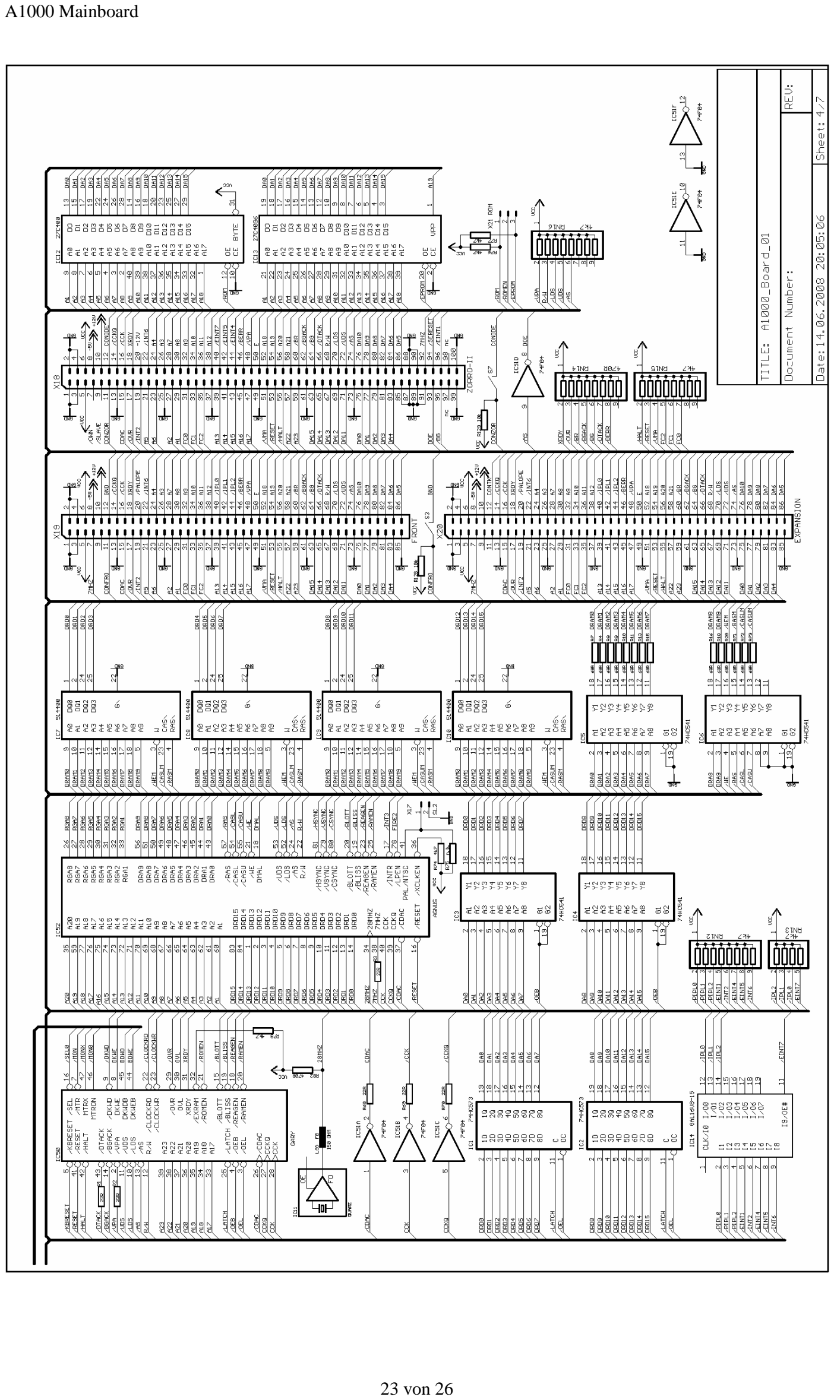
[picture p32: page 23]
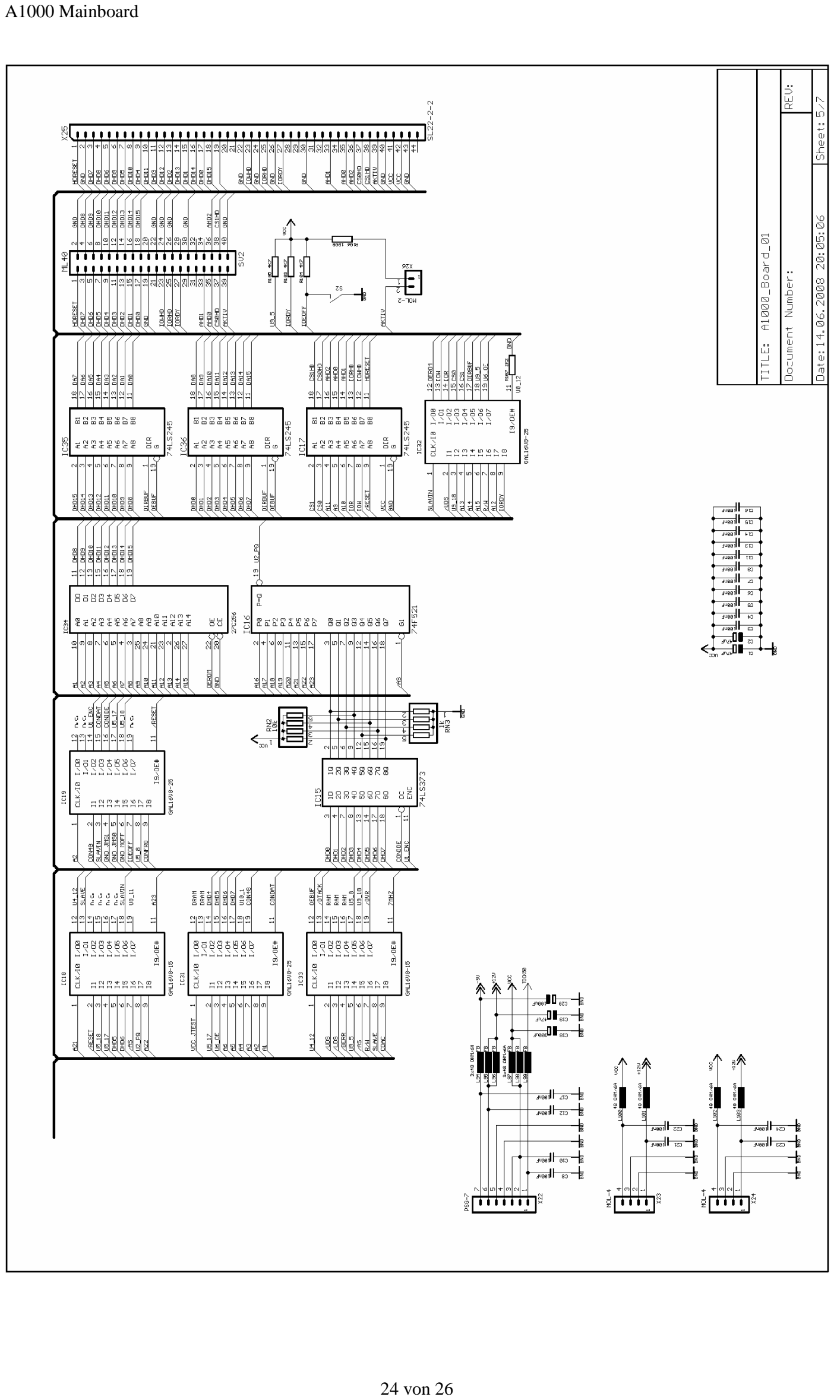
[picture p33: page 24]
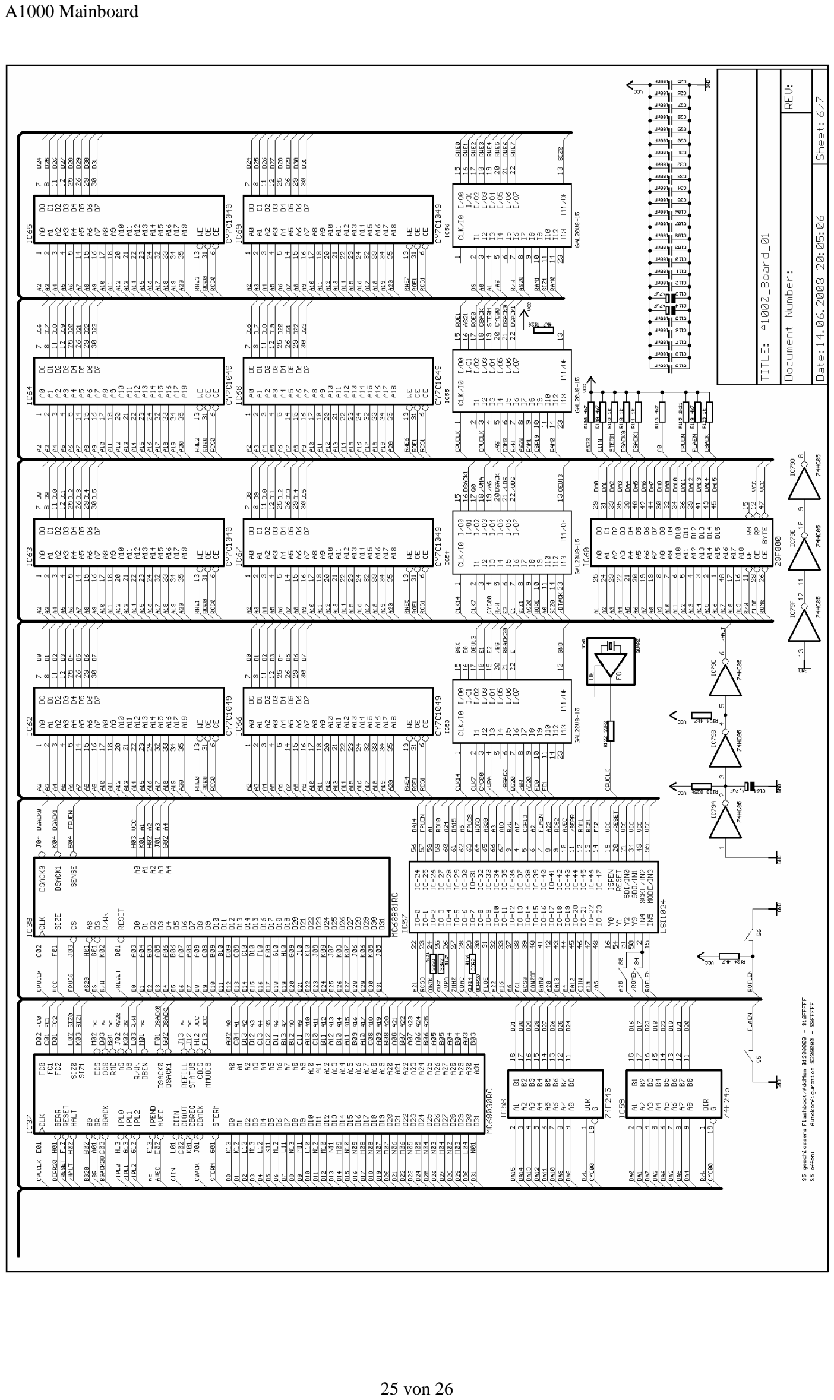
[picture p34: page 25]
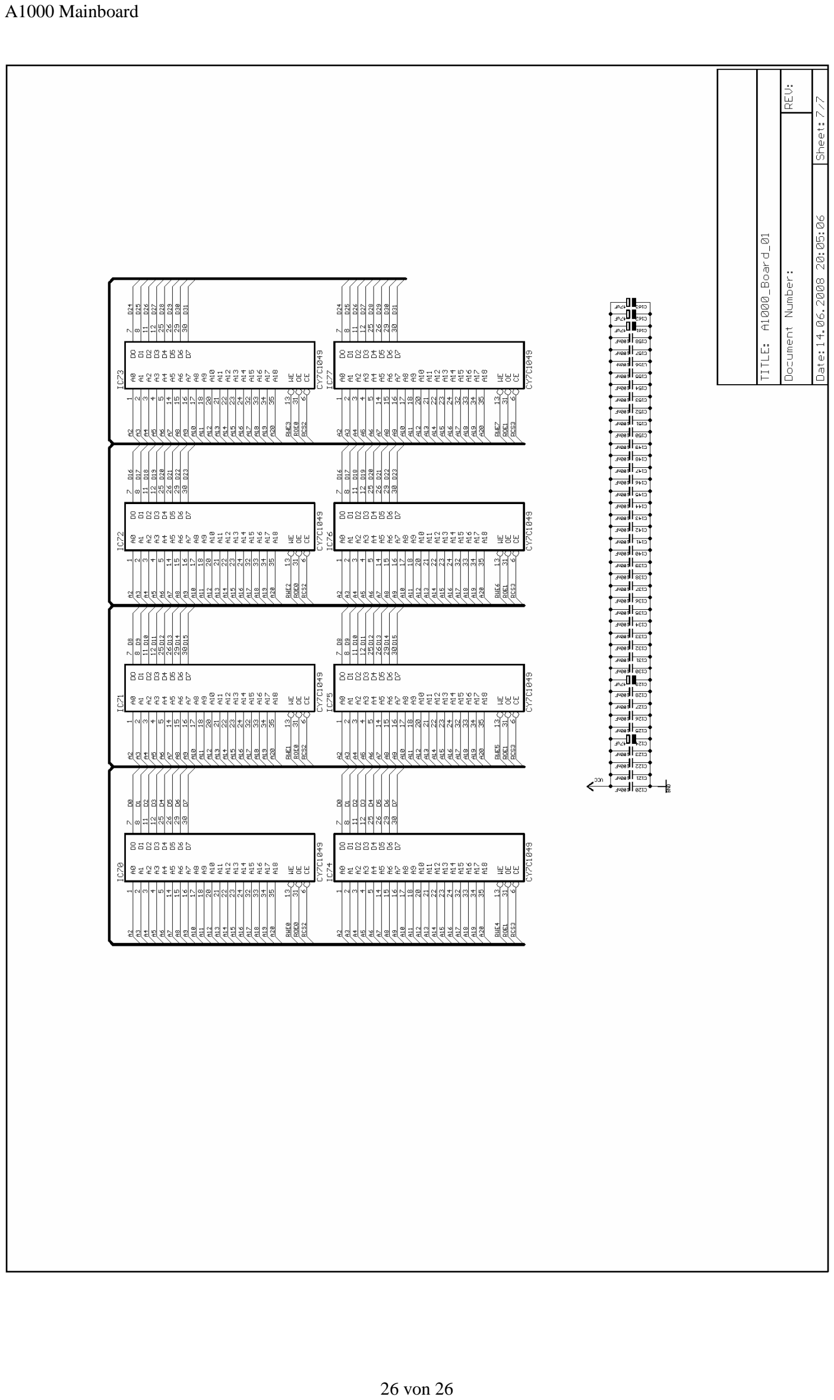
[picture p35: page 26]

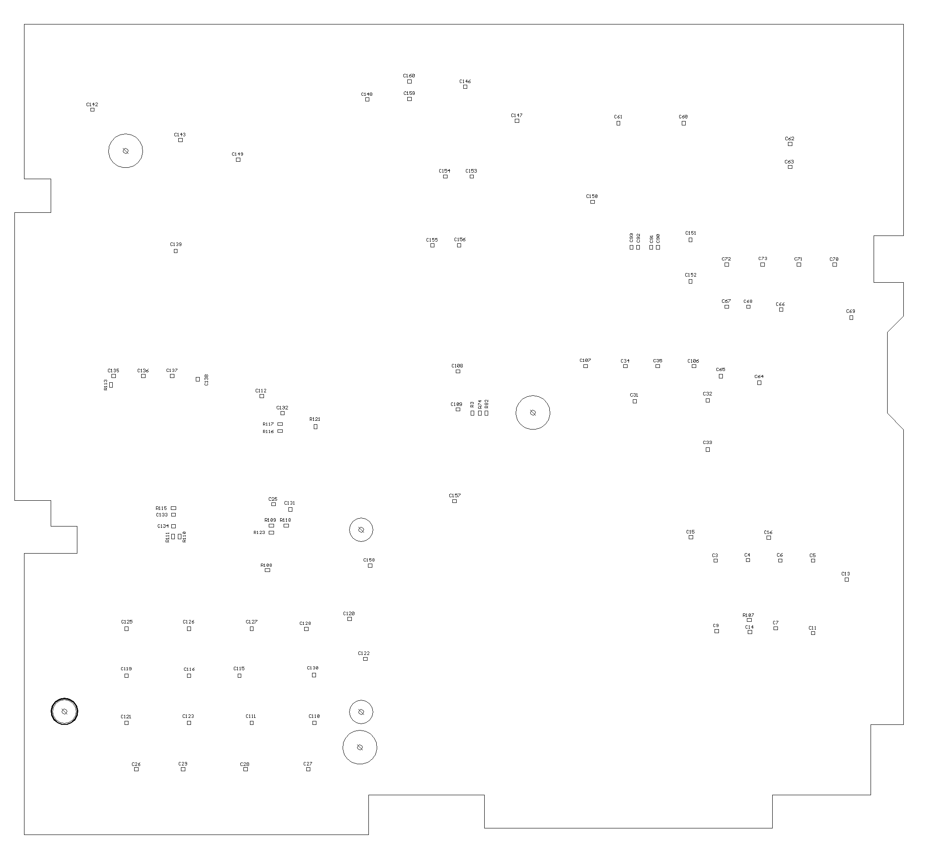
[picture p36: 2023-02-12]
instructions-rev0/LS_01.tif

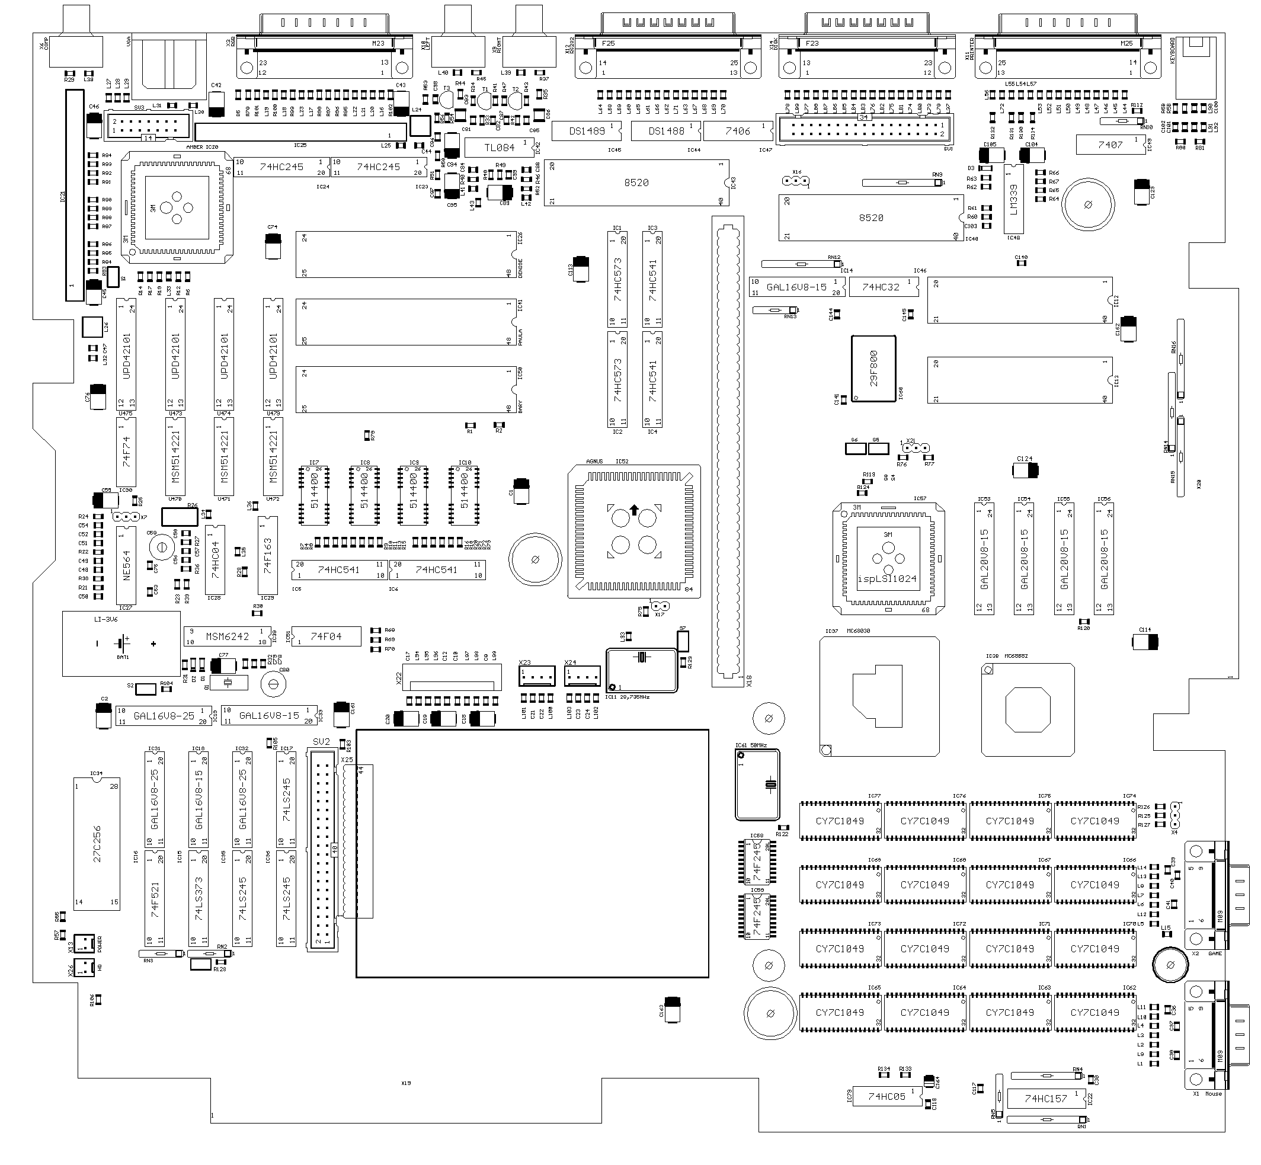
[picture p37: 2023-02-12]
instructions-rev0/BS_01.tif

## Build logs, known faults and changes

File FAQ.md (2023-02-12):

# FAQ

Information copied from the old, now defunct gba1000.info website ([wayback machine link](https://web.archive.org/web/20090903050522/http://www.gba1000.info/)), and more.

## Difficulty of building a GBA1000

Note from Georg Braun himself:

"I do not want to deal with frustrated people who participate in a bulk order because of a good price, especially when it results in nasty comments on the web. Completing the board requires about 20 to 30 hours of soldering including work on rosters with pin distances of 0.5 mm. The circuit is highly complex and involves many potential sources of error. Troubleshooting involves working with oscillators, drivers and custom chips bought as "new", which for one reason or another may not work properly. Soldering problems also occur, which happen to me too. Debugging can easily take several hours. On top of that, you will be working with a 4 layer PCB, which of course must be of suitable quality, including the size of the PCB, through-layer contacts and minimum measure. Also, a good free of debris adhesion of the copper layer is needed for the visa and IC-sockets etc. The solder mask must be resistant to solder running on to it and the PCB should not show any bends or twists. Some of the components used in this board are difficult to obtain or only obtainable from older Amiga hardware. This does not only concern the Amiga custom chips but also TTL-Gutter like for instance 74F245 which is no longer in trade in an SMD model. The project builder must know where to find these parts on his own."

## Order to populate the board:

Schneemann: I am not afraid to solder the board, but I'm worrying getting stuck in case of any error. It will be not my first PCB, but the first of that size and complexity. I hope that it will be possible to set up the board step by step, as far as Georg just "easily" integrated the IDE-controller and the flicker fixer via (not directly visible) standard Amiga-interfaces. That means the main-part should work even without flicker fixer and IDE-controller. If I'm right, most of the GALs belong to these optional parts. The CPU, FPU and custom chips are socketed (easy to check). More difficult is the RAM (hard to solder and getting damaged fast), but if this part works, we should see a picture, e.g. with an external flicker fixer, on the screen, then the rest could follow.

Kristian95: You are right there are many possibilities for errors and trouble shooting will most likely take most of use as much time as the actual soldering. The Flicker fixer is indeed optional (no changes necessary to the build if you leave it out). Also the IDE controller is optional, I can't remember what change you need to make to the build, but it is documented in my translation of the user's guide. I don't think it should be a big problem getting the GALs programmed. Do you know whether it would be "easy" to make the RAM socketed instead of surface mounted? If it is we might consider doing so :) Therefore we should find such kind of build-phases in order to have chance of any testing.

Schneemann: The GALs are not the problem. It is in general better to have parts of the board tested and running well before starting with other parts and unfortunately, you can't test the IDE controller and the flicker fixer (that's where the GALs are used) without the CPU and RAM working. So I suggest the best build order is vice versa, i.e. leave most of the GALs as well as SD and IDE for later and start by building and testing the bare computer.

This discussion basically boils down to:

- Leave building the IDE Controller and Flicker Fixer sections for later (they work independently of the main logic)
- Build the main part of the board and get it to output a video signal using an add-on flicker fixer like one from Indivision.
- The main part includes the Amiga custom chips, CPU, fpu
- After you have a video signal, you can solder the RAM and the Flash ROM (it’s a good idea check for video signal after you solder each RAM chip and after the Flash ROM.) The RAM and the Flash ROM have a lot of pins and they are very close together and this introduces the possibility of making many soldering mistakes. Checking after each chip allows you to make sure you did that one properly.
- The challenging GAL chips seem to be part of the optional flicker fixer and IDE controller sections and can be tackled last.

## Soldering work

**Sockets**

Use good quality sockets (tulip), reduces risk.

**During the soldering work, I'm afraid of getting stuck in case of errors. Any ideas?**

Gleaming from the discussion above:
* The soldering process can be divided into steps.
* Consider integrating the flicker fixer and the IDE controller after the main part works.
* Main part CPU, FPU and custom chips are socketed.
* GAL chips, perhaps most challenging, are seemingly on optional video and IDE parts.
* Solder RAM later, after the board produces a picture on an external flicker fixer.

In short, build the main board first. Add the RAM, flicker fixer and IDE controller when you've tested that the main board works.

**I'm afraid to dammage parts during the soldering. Any suggestions?**

* True, this is not going to be easy.
* Practice on old parts first. (I purchased cheap electronics at second hand shops for this purpose.)
* Watch the soldering videos listed in the links section.
* Purchase a good soldering station. See the one suggested by Plaz listed in the links section.
* More information about tools will be listed as it becomes available from experienced members.

**Another soldering tip...**

When assembling the board solder the FlashROM as the very last thing. The reason is that the space between the pins is very short there and it is therefore the easy place to make a solder bridge. Thus if you test the board prior to soldering the FlashROM and the board works, and then it doesn't work after the FlashROM is soldered, you made your error finding much easier.

## Board's parameters

```
4 Layer (35µm , 35µm , 35µm , 35µm)
1x Materials (FR4 0,71 35/35)
4x Prepreg (7628,7628,7628,7628)
Thickness: 1.54mm
Panel size: 344.488mm x 314.007mm

4648 Drills. / Panel.
21 Drill changes
Smallest drill Ø: 0.3mm
Technology: >= 150µm
SMD: doppelseitig >= 1/50"
Finish: chem. Ni/Au
Soldermask: on both sides
Identprints: 1
Peel off mask: no
Mech. working: Fräsen;
E-Test: Yes
```

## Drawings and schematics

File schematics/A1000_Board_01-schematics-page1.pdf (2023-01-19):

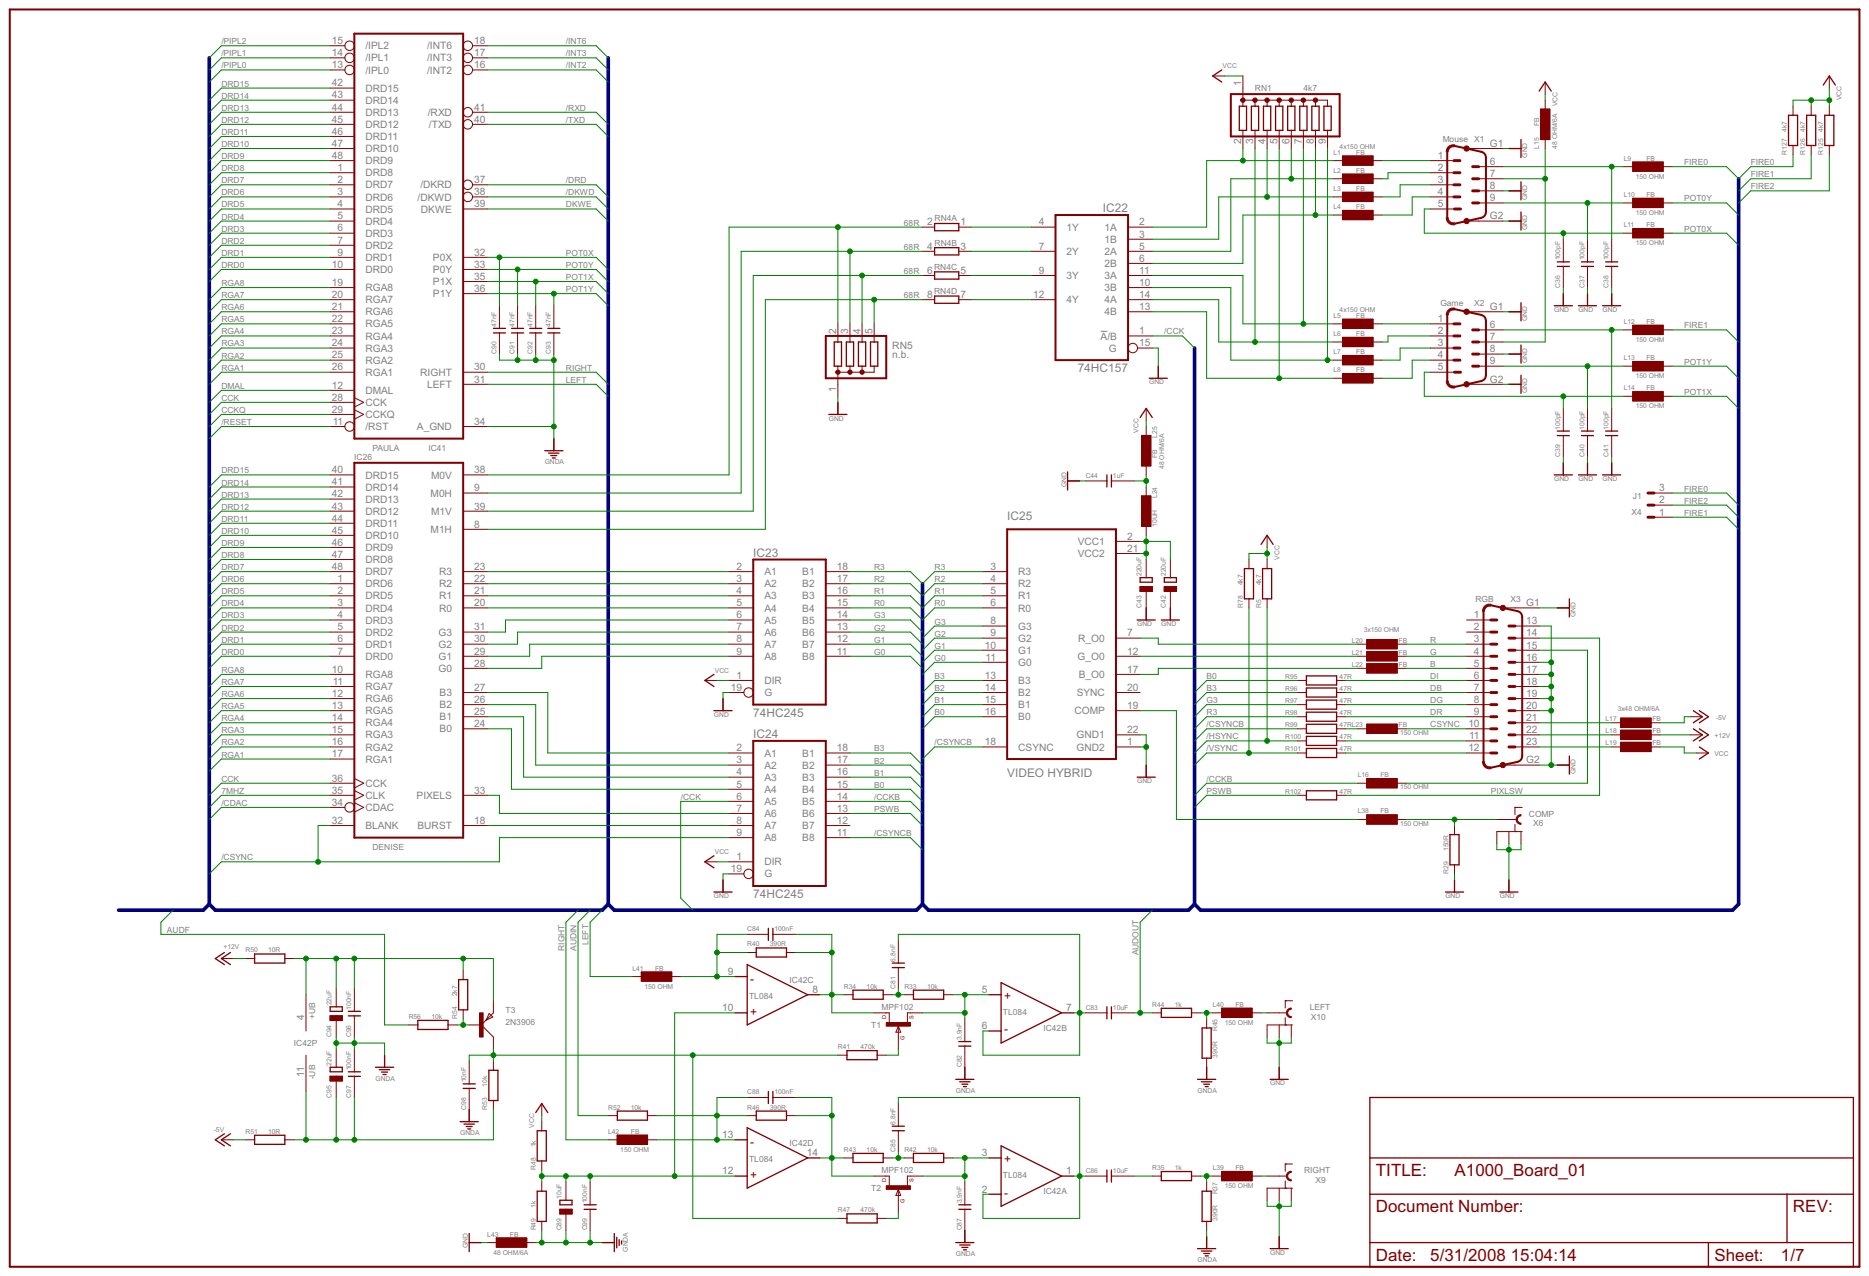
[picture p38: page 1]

GND GND

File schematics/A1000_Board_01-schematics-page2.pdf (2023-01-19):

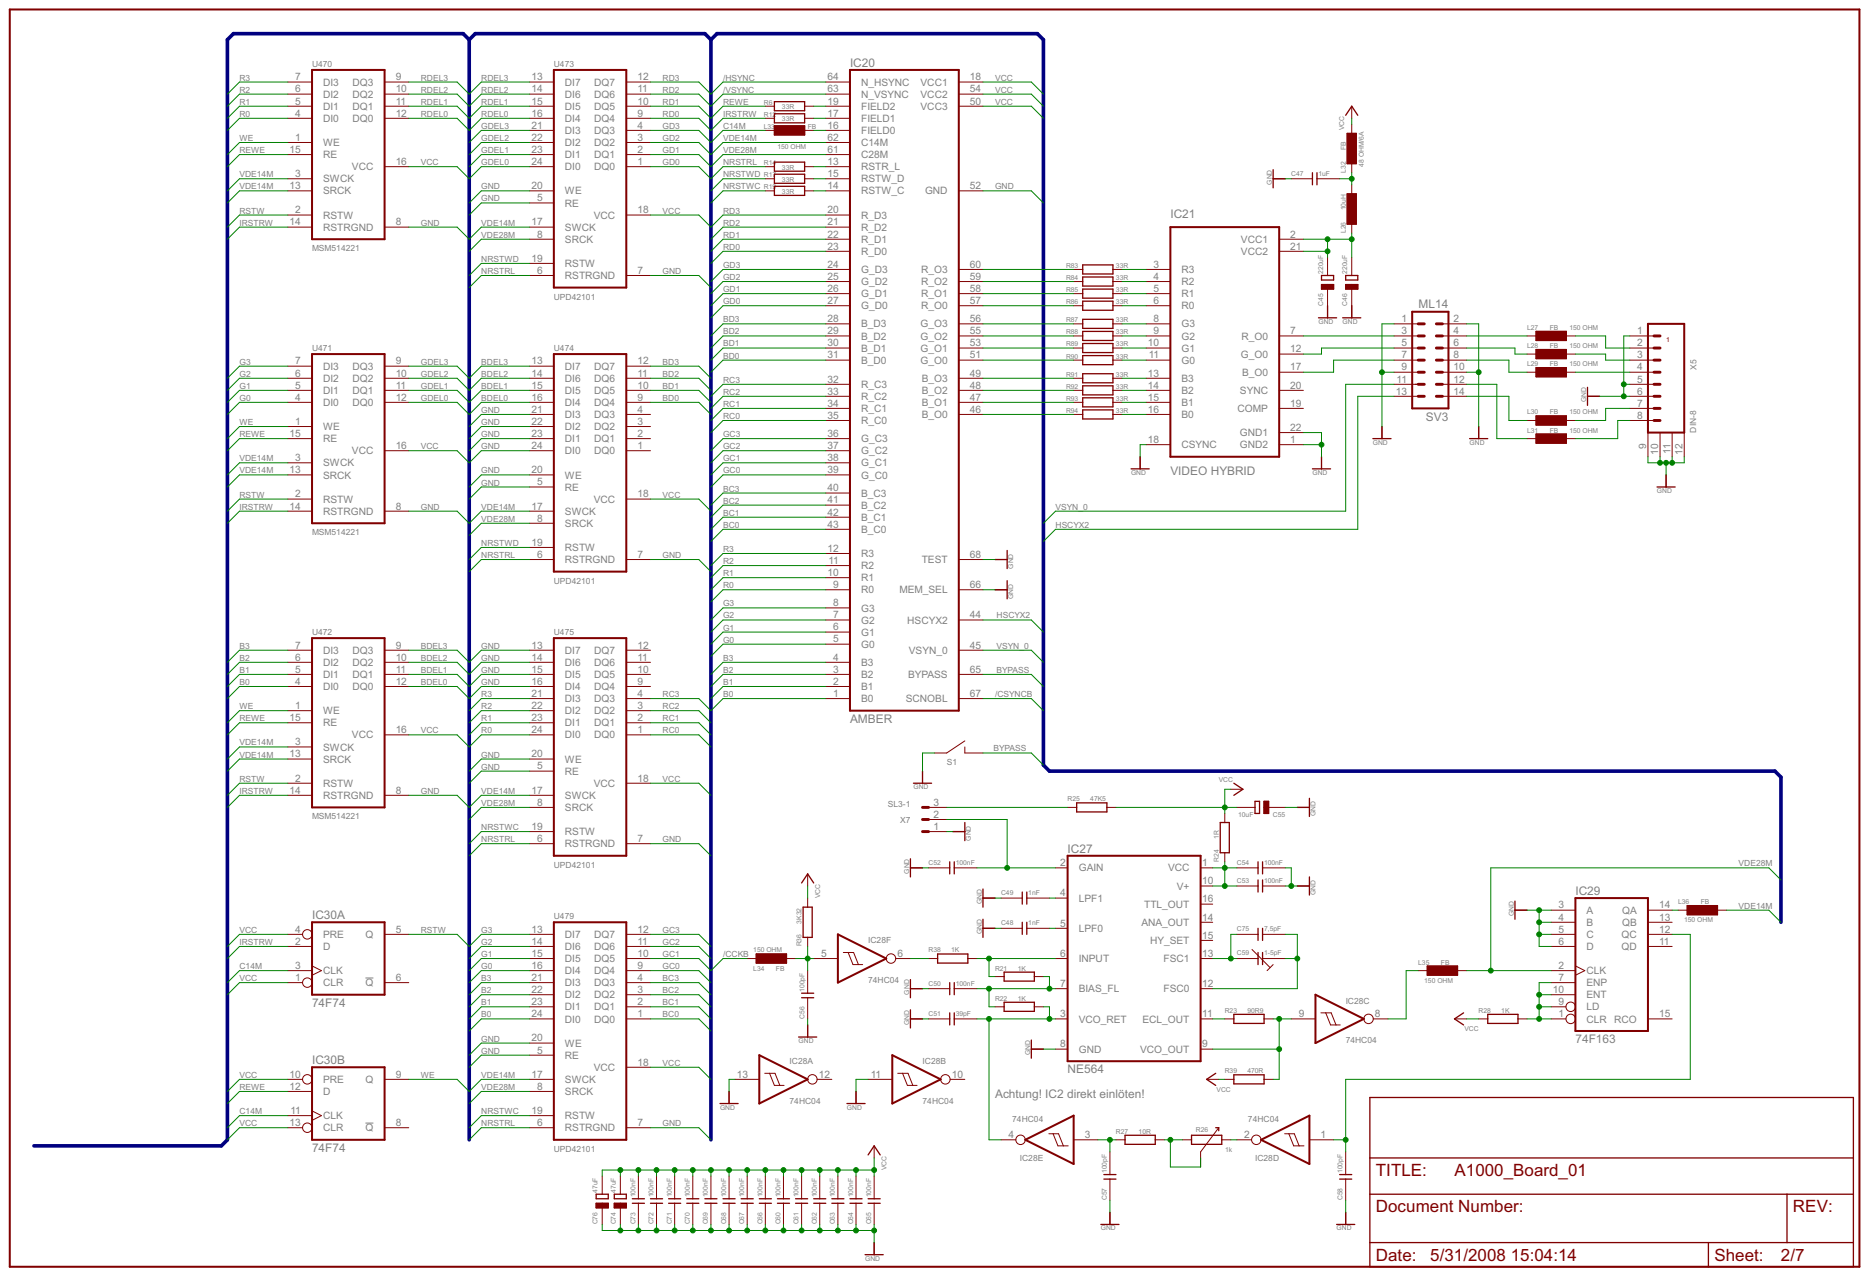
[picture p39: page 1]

BDEL0 GND GND GND GND

GND GND

Document Number: | REV:

Date: 5/31/2008 15:04:14 | Sheet: 2/7

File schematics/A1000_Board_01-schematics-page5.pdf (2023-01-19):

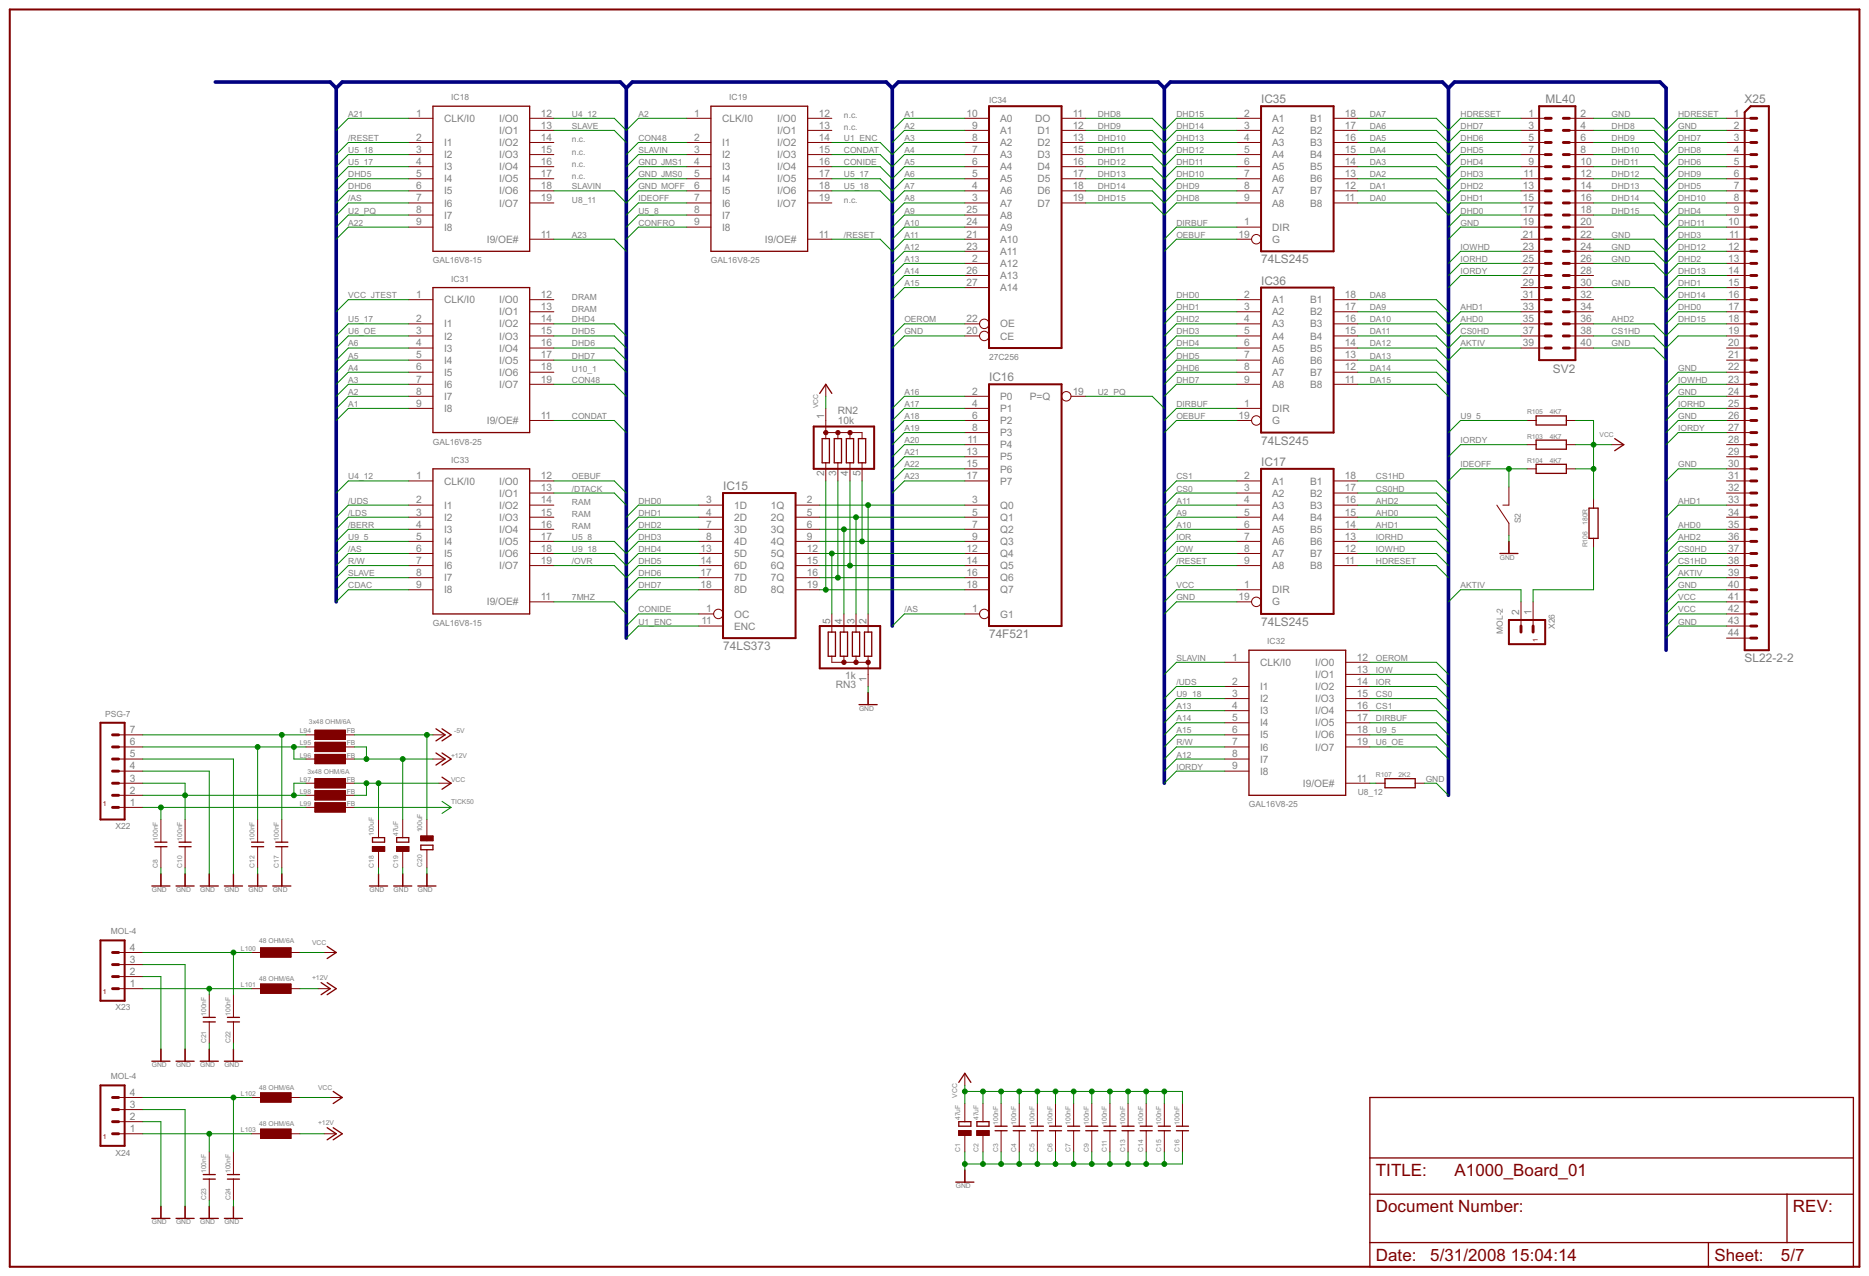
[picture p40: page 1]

VCC GND47uF 47uF 100nF 100nF 100nF 100nF 100nF 100nF 100nF 100nF 100nF 100nF 100nF 74LS373 74F521 74LS245 GAL16V8-15 GAL16V8-25 GAL16V8-25 GAL16V8-25 GAL16V8-15 27C256 74LS245 74LS245 ML40 10k1k VCC GND 4K7 VCC 4K7 GND 4K7 180R 2K2 FBFBFBFBFBFB 100nF 100nF GND GND VCC GND GND GND GND 100nF 100nF +12V -5V GND GND GND 100uF 47uF 100uF PSG-7 MOL-4 MOL-4 100nF 100nF 100nF 100nF 48 OHM/6A 48 OHM/6A 48 OHM/6A 48 OHM/6A VCC VCC+12V +12V GND GND GND GND GND GND GND GND SL22-2-2 MOL-2 U8_12 n.c. n.c. n.c. DRAM DRAM JTEST U10_1 JMS0 JMS1 MOFF RAM RAM RAM n.c. n.c. n.c. n.c. U8_11 3x48 OHM/6A 3x48 OHM/6A C1C2C3C4C5C6C7C9C11 C13 C14 C15 C16 OC 1 1Q 2 1D 3 2D 4 2Q 5 3Q 6 3D 7 4D 8 4Q 9 ENC 11 5Q 12 5D 13 6D 14 6Q 15 7Q 16 7D 17 8D 18 8Q 19 IC15 G1 1 P0 2 Q0 3 P1 4 Q1 5 P2 6 Q2 7 P3 8 Q3 9 P4 11 Q4 12 P5 13 Q5 14 P6 15 Q6 16 P7 17 Q7 18 P=Q 19 IC16 DIR 1 A1 2 A2 3 A3 4 A4 5 A5 6 A6 7 A7 8 A8 9 B8 11 B7 12 B6 13 B5 14 B4 15 B3 16 B2 17 B1 18 G 19 IC17 CLK/I0 1 I1 2 I2 3 I3 4 I4 5 I5 6 I6 7 I7 8 I8 9 I/O0 12 I/O1 13 I/O2 14 I/O3 15 I/O4 16 I/O5 17 I/O6 18 I/O7 19 I9/OE# 11 IC18 CLK/I0 1 I1 2 I2 3 I3 4 I4 5 I5 6 I6 7 I7 8 I8 9 I/O0 12 I/O1 13 I/O2 14 I/O3 15 I/O4 16 I/O5 17 I/O6 18 I/O7 19 I9/OE# 11 IC19 CLK/I0 1 I1 2 I2 3 I3 4 I4 5 I5 6 I6 7 I7 8 I8 9 I/O0 12 I/O1 13 I/O2 14 I/O3 15 I/O4 16 I/O5 17 I/O6 18 I/O7 19 I9/OE# 11 IC31 CLK/I0 1 I1 2 I2 3 I3 4 I4 5 I5 6 I6 7 I7 8 I8 9 I/O0 12 I/O1 13 I/O2 14 I/O3 15 I/O4 16 I/O5 17 I/O6 18 I/O7 19 I9/OE# 11 IC32 CLK/I0 1 I1 2 I2 3 I3 4 I4 5 I5 6 I6 7 I7 8 I8 9 I/O0 12 I/O1 13 I/O2 14 I/O3 15 I/O4 16 I/O5 17 I/O6 18 I/O7 19 I9/OE# 11 IC33 A0 10 A1 9 A3 7 A2 8 A4 6 A5 5 A6 4 A7 3 A8 25 A9 24 A10 21 A11 23 A12 2 A13 26 A14 27 DO 11 D1 12 D2 13 D3 15 D4 16 D5 17 D6 18 D7 19 IC34OE 22 CE 20 DIR 1 A1 2 A2 3 A3 4 A4 5 A5 6 A6 7 A7 8 A8 9 B8 11 B7 12 B6 13 B5 14 B4 15 B3 16 B2 17 B1 18 G 19 IC35DIR 1 A1 2 A2 3 A3 4 A4 5 A5 6 A6 7 A7 8 A8 9 B8 11 B7 12 B6 13 B5 14 B4 15 B3 16 B2 17 B1 18 G 19 IC36 13579 SV2 111315171921232527293133353739 246810121416182022242628303234363840 1 2345 RN2 1 5432 RN3 R103 R104 S2 R105 R106 R107 L94 L95 L96 L98 L99 L97 C8C10 C12 C17 C18 C19 C20 X224563217 X231234 X241234 C21 C22 C23 C24 L100 L101 L102 L103 X25 1234567891011121314151617181920212223242526272829303132333435363738394041424344 X2621 GND GND GND GND GND GND GND GND GND GND GND GND GND GND GND GND GND GND GND GND VCC VCC VCC VCC A1 A1 A2 A2 A2 A6 A6 A21 A21 A4 A4 A3 A3 A7A8A9 A9 A10 A10 A11 A11 A12 A12 A13 A13 A14 A14 A15 A15 A16 A17 A18 A19 A20 A22 A22 A23 A23 A5 A5 DA0 DA1 DA2 DA3 DA4 DA5 DA6 DA7 DA8 DA9 DA10 DA11 DA12 DA13 DA14 DA15 /AS /AS /AS /UDS /UDS /LDS R/W R/W /RESET /RESET /RESET CONFRO /BERR HDRESET HDRESET HDRESET DHD7 DHD7 DHD7 DHD7 DHD6 DHD7 DHD6 DHD6 DHD6 DHD6 DHD6 DHD5 DHD5 DHD5 DHD5 DHD5 DHD5 DHD4 DHD4 DHD4 DHD4 DHD4 DHD3 DHD3 DHD3 DHD3 DHD2 DHD2 DHD2 DHD2 DHD1 DHD1 DHD1 DHD1 DHD0 DHD0 DHD0 DHD0 IOWHD IOWHD IOWHD IORHD IORHD IORHD IORDY IORDY IORDY IORDY AHD1 AHD1 AHD1 AHD0 AHD0 AHD0 CS0HD CS0HD CS0HD AKTIV AKTIV AKTIV CS1HD CS1HD CS1HD AHD2 AHD2 AHD2 DHD15 DHD15 DHD15 DHD15 DHD14 DHD14 DHD14 DHD14 DHD13 DHD13 DHD13 DHD13 DHD12 DHD12 DHD12 DHD12 DHD11 DHD11 DHD11 DHD11 DHD10 DHD10 DHD10 DHD10 DHD9 DHD9 DHD9 DHD9 DHD8 DHD8 DHD8 DHD8 OEBUF OEBUF OEBUF DIRBUF DIRBUF DIRBUF OEROM OEROM IOW IOW IOR IOR CS1 CS1 CS0 CS0 U2_PQ U2_PQ U1_ENC U1_ENC U9_5 U9_5 U9_5 U6_OE U6_OE U9_18 U9_18 SLAVIN SLAVIN SLAVIN CONIDE CONIDE CON48 CON48 IDEOFF IDEOFF U5_8 U5_8 CONDAT CONDAT U5_17 U5_17 U5_17 U5_18 U5_18 /OVR 7MHZ SLAVE SLAVE CDAC U4_12 U4_12 /DTACK TICK50 Date: 5/31/2008 15:04:14 Sheet: 5/7REV: TITLE: Document Number: A1000_Board_01 111 1

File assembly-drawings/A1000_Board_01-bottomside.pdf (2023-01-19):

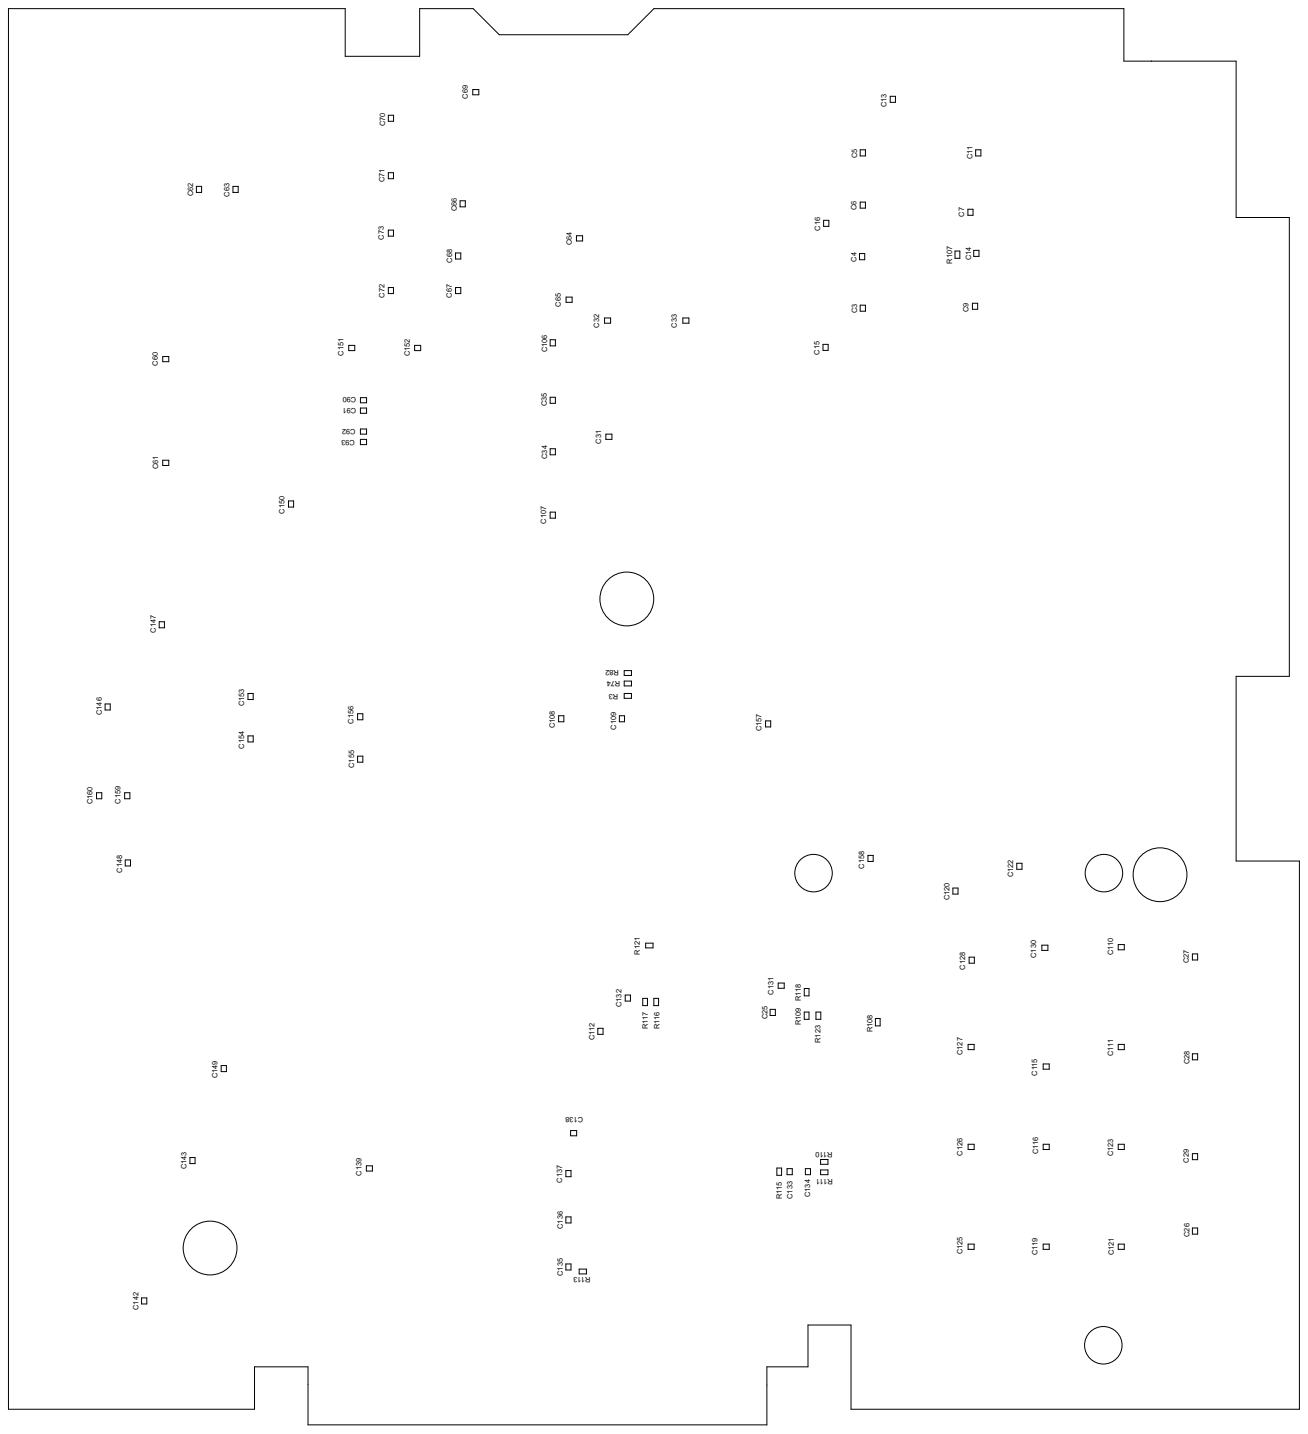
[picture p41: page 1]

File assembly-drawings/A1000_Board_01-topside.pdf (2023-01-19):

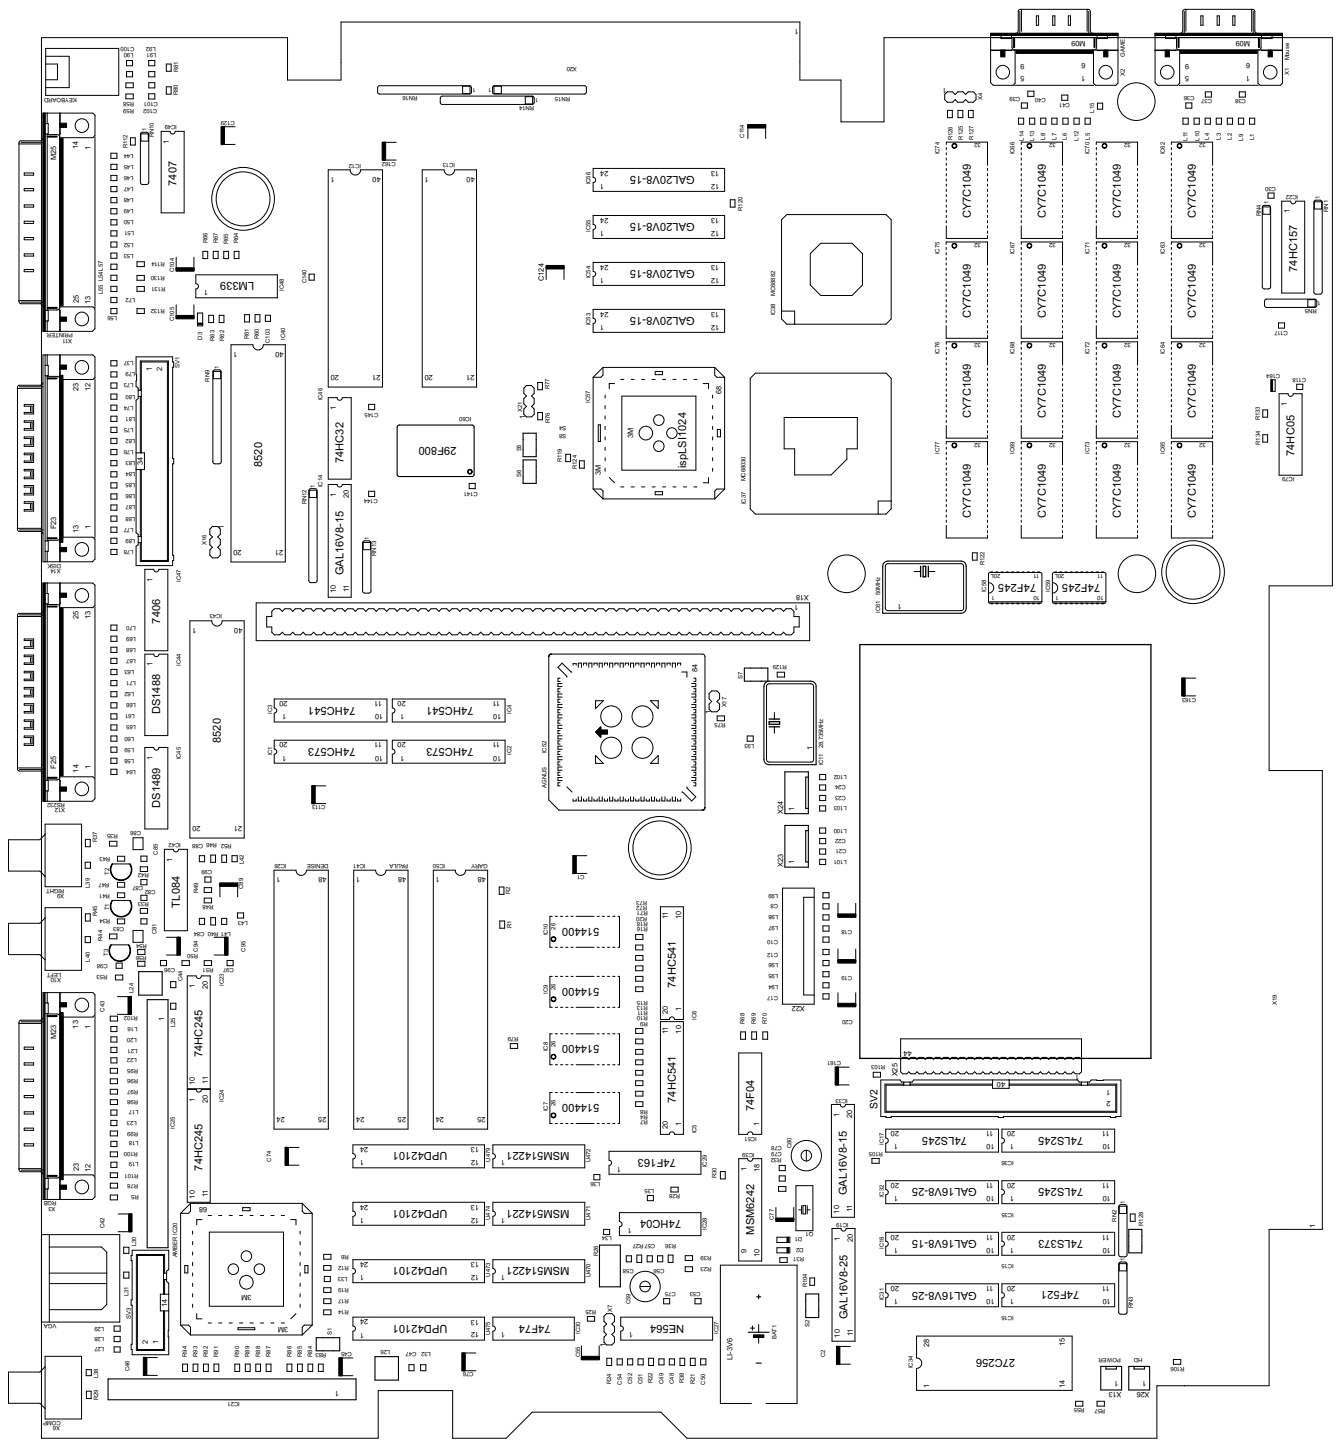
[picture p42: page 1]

GAME RE WOP DH

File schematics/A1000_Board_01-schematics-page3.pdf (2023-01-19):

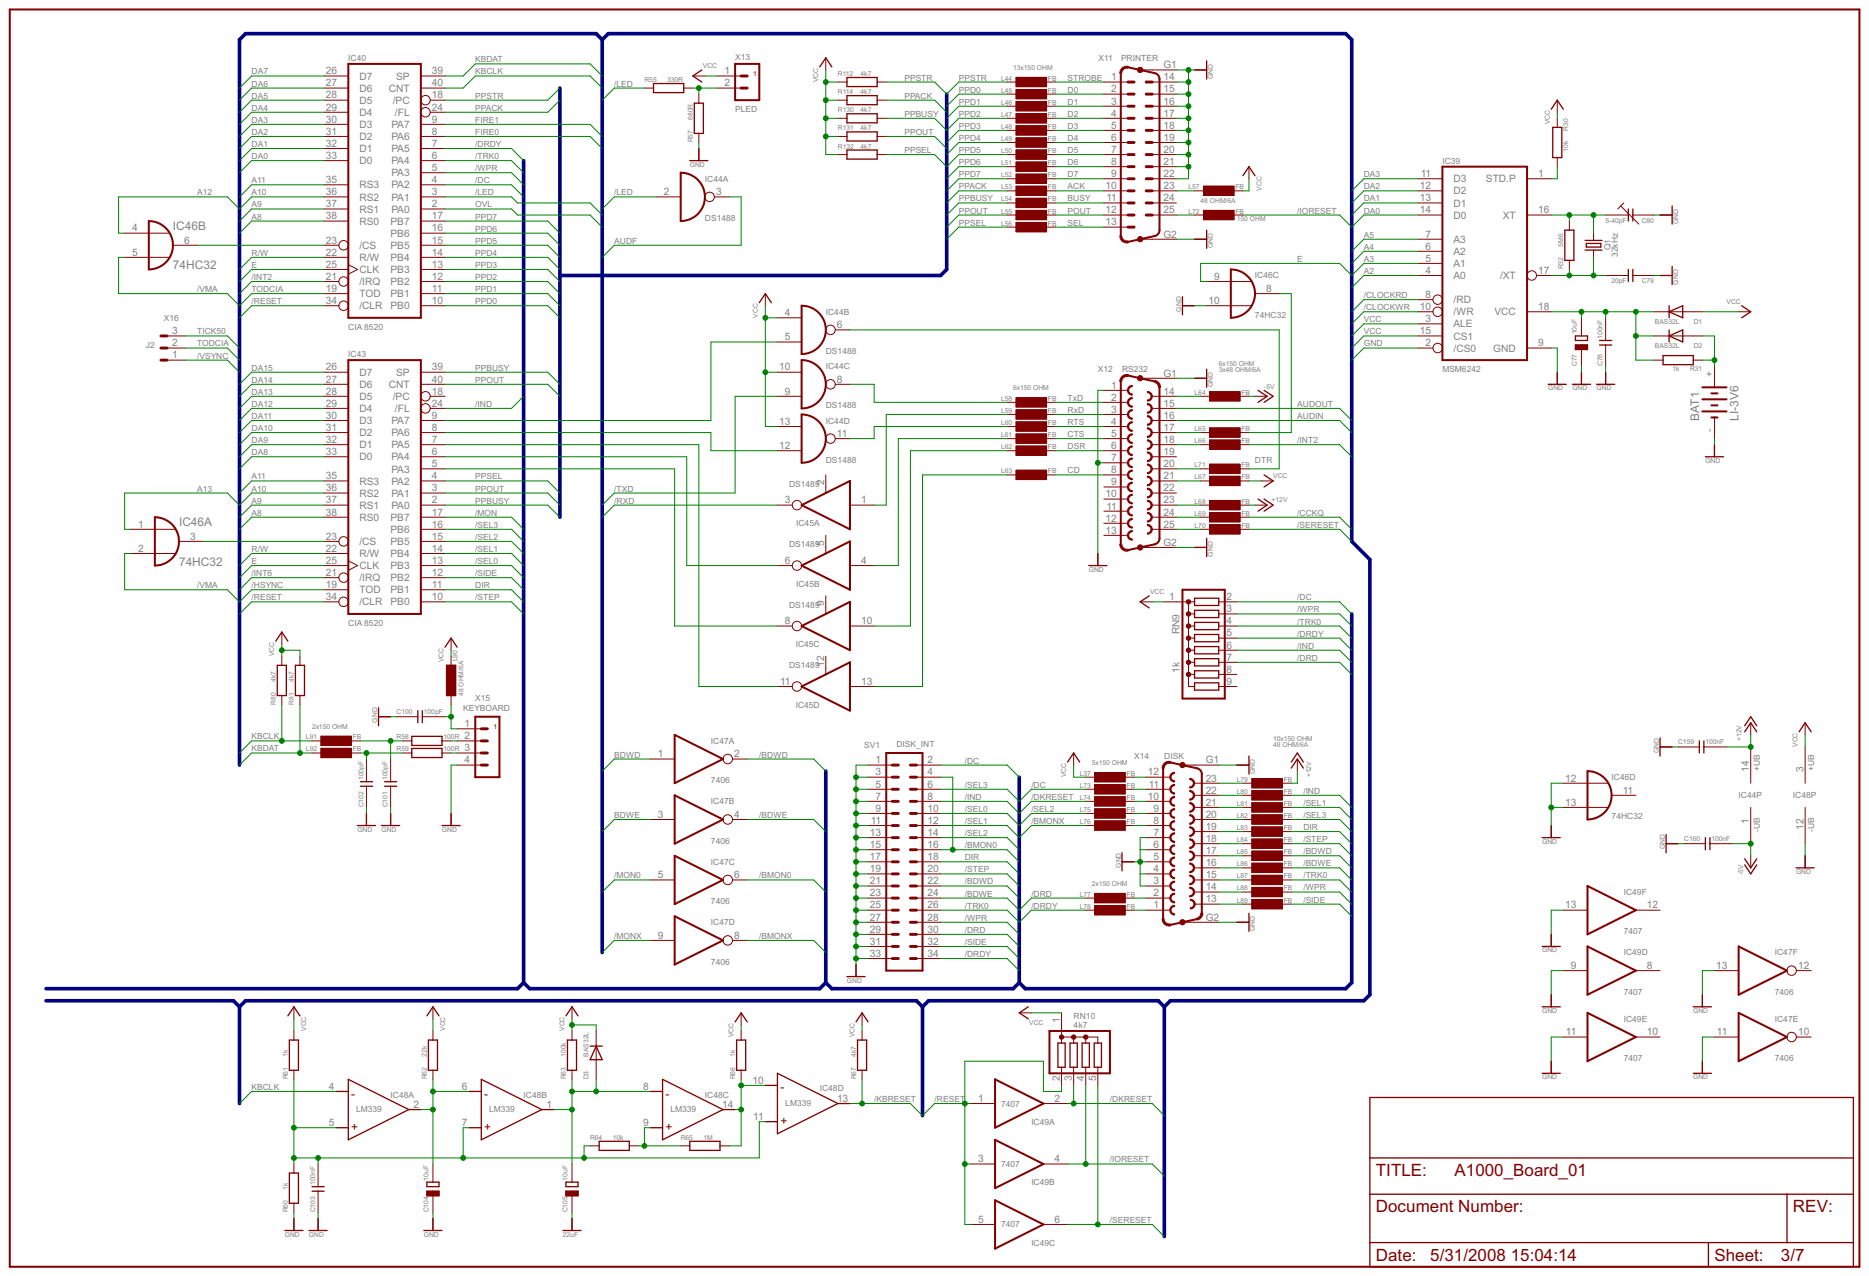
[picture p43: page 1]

6 PA5
5 PA4
4 PA3 3 PA2 2 PA1 16 PB7 15 PB6 14 PB5 13 PB4 12 PB3 11 PB2 10 PB1

Document Number: | REV:

Date: 5/31/2008 15:04:14 | Sheet: 3/7

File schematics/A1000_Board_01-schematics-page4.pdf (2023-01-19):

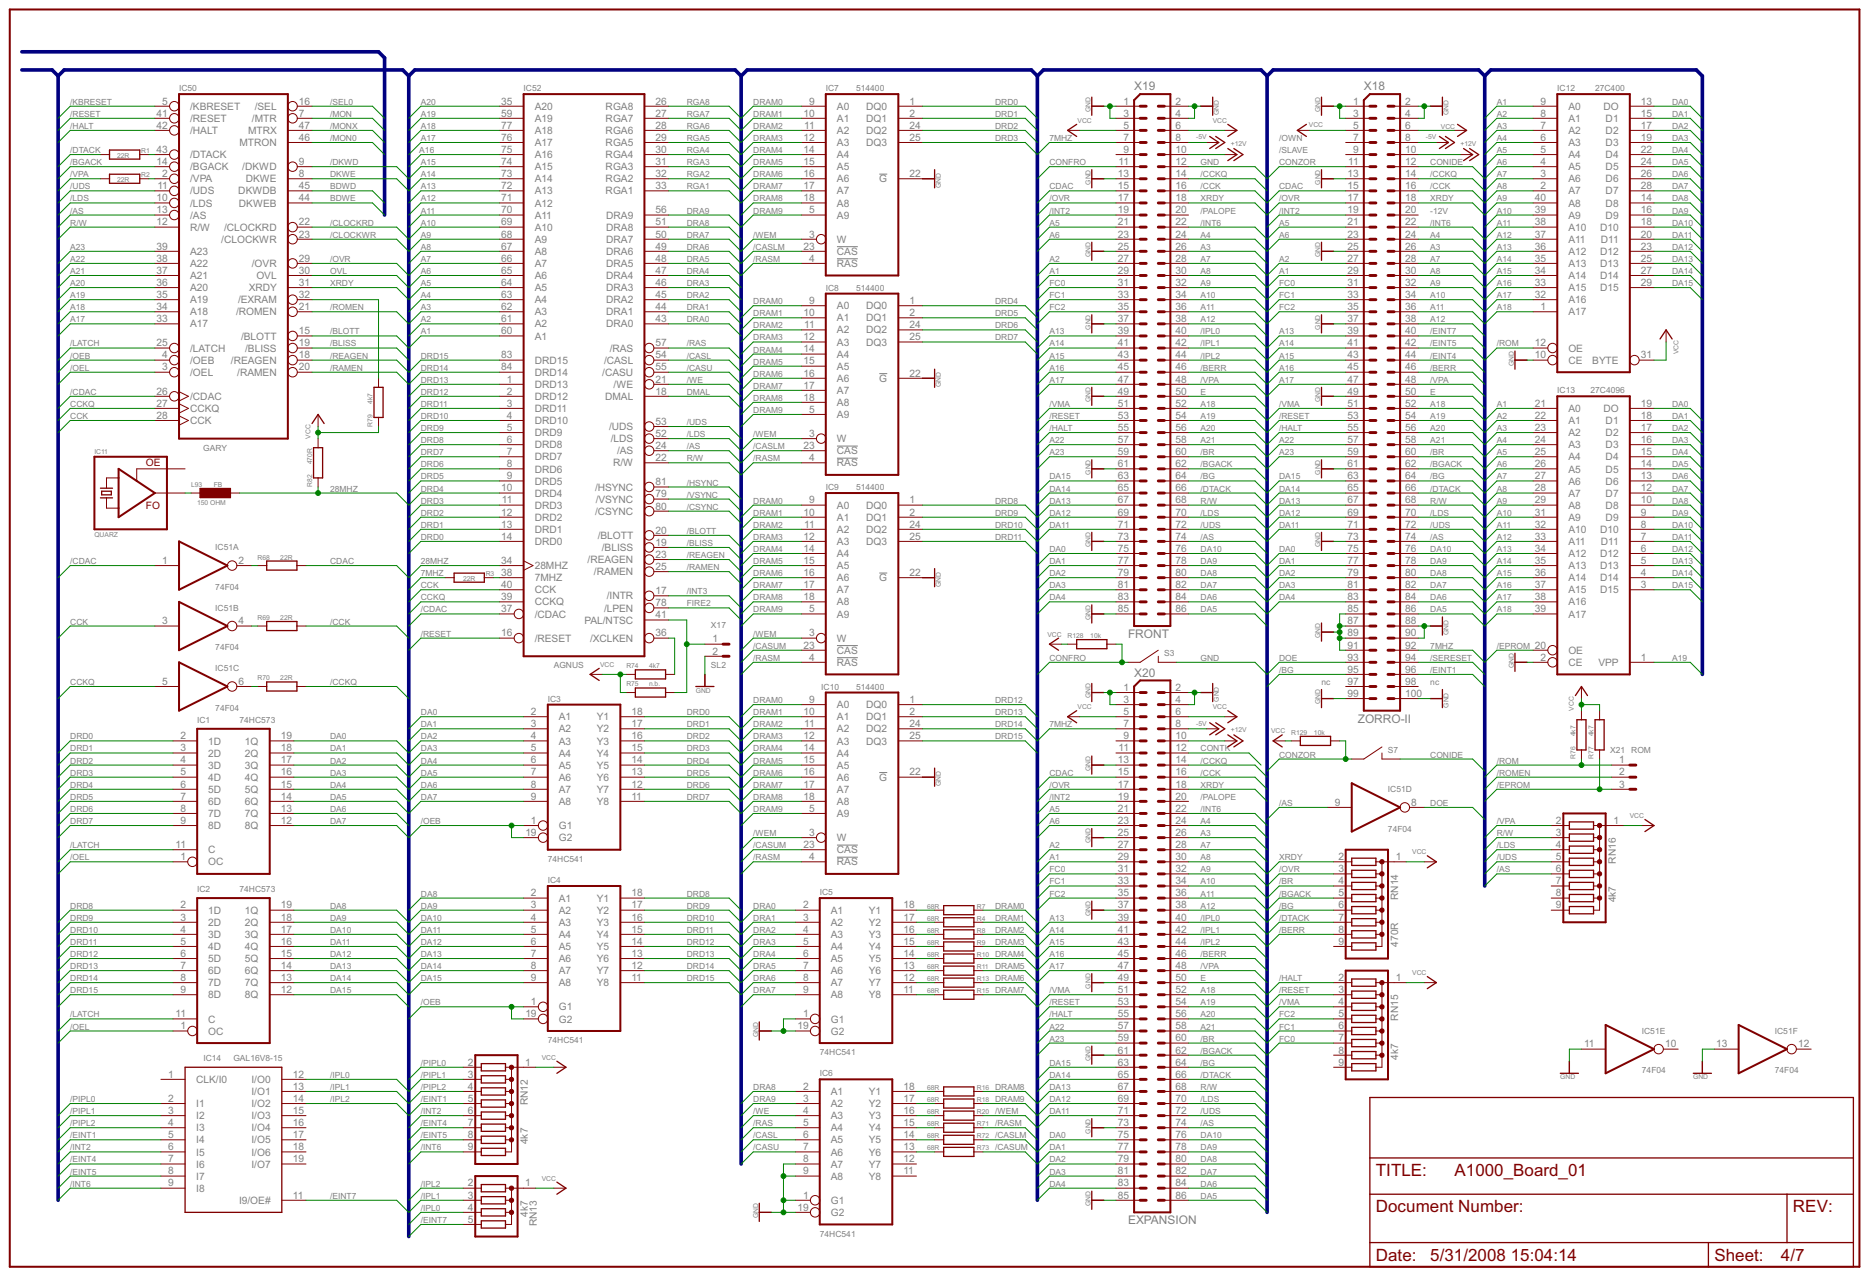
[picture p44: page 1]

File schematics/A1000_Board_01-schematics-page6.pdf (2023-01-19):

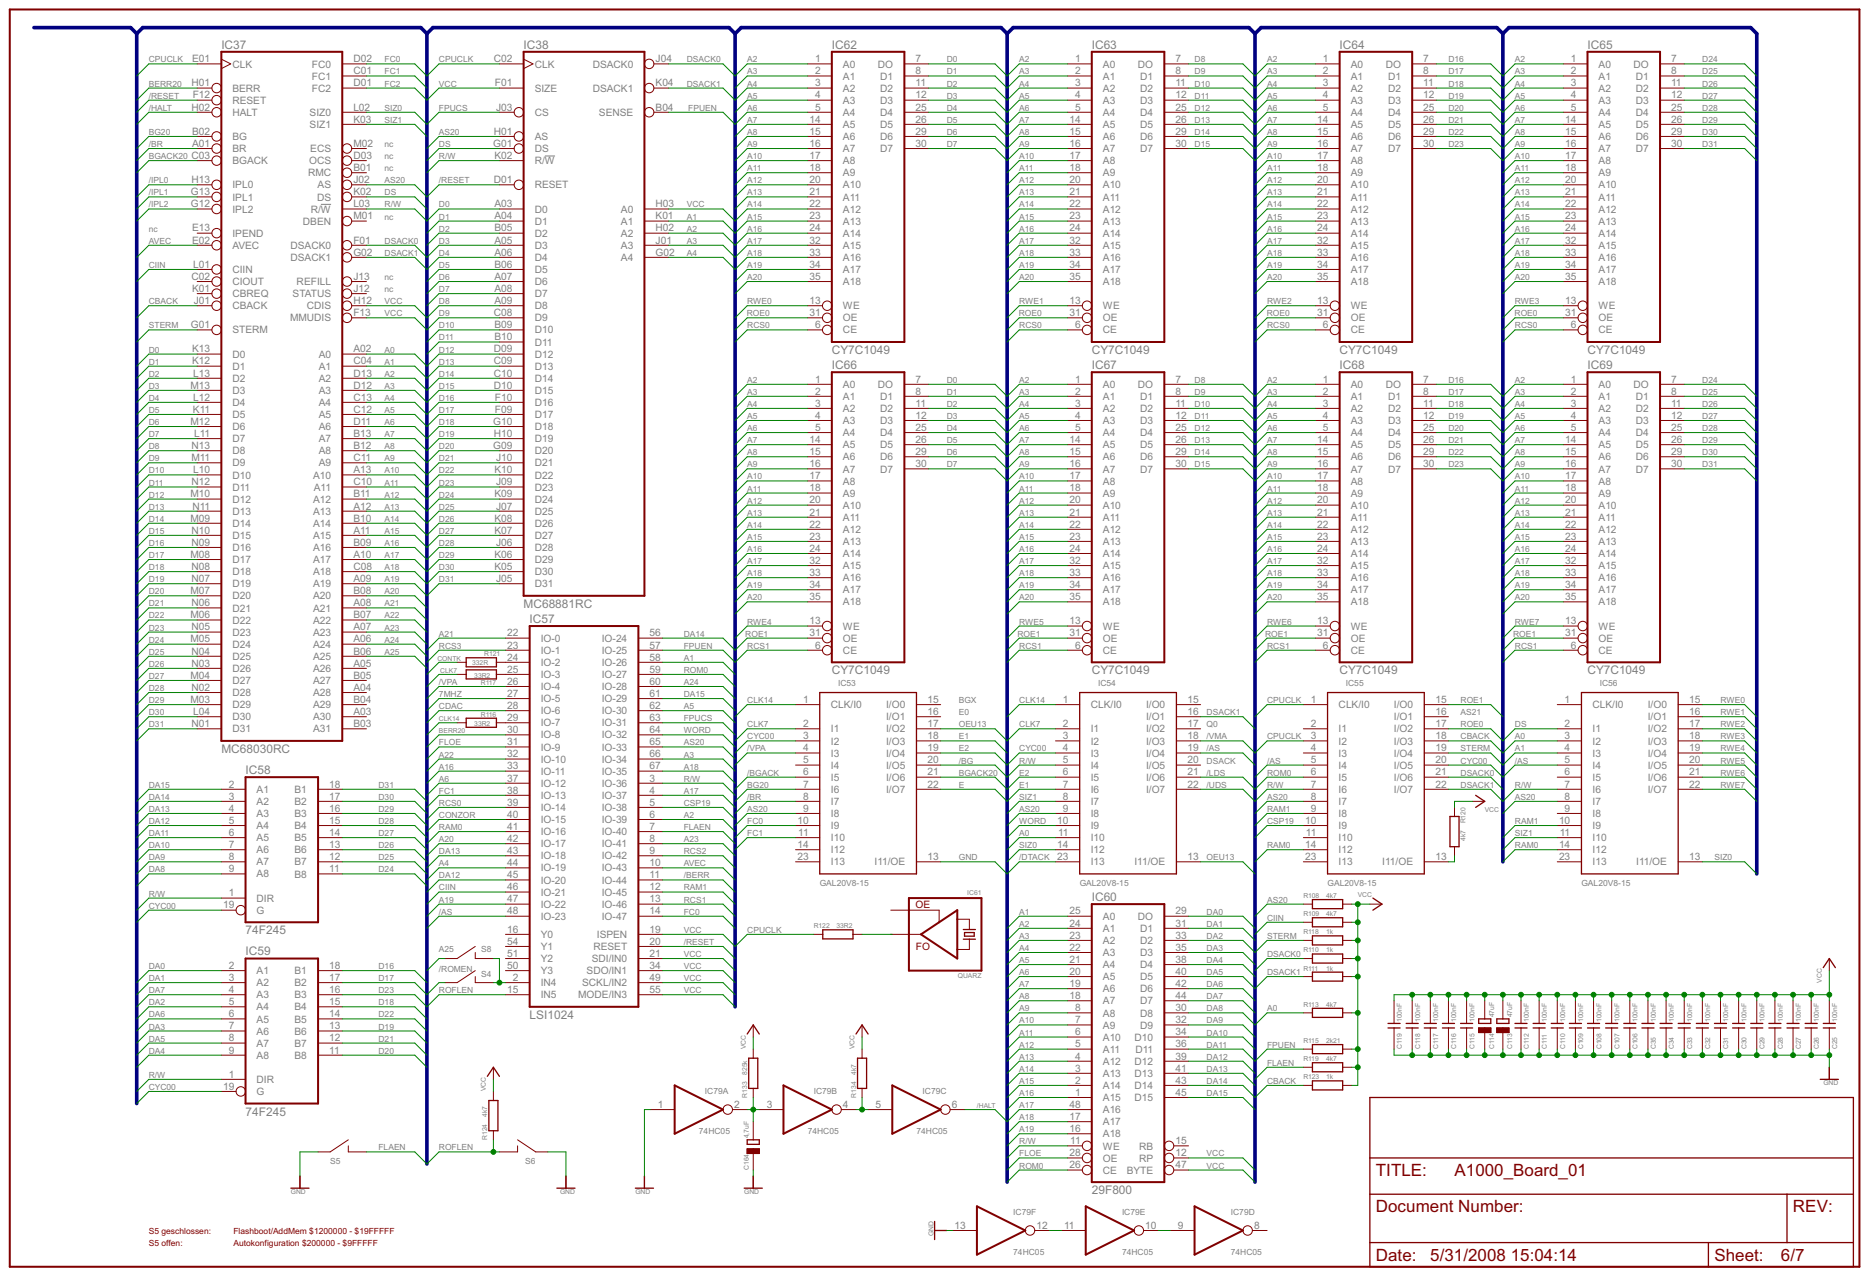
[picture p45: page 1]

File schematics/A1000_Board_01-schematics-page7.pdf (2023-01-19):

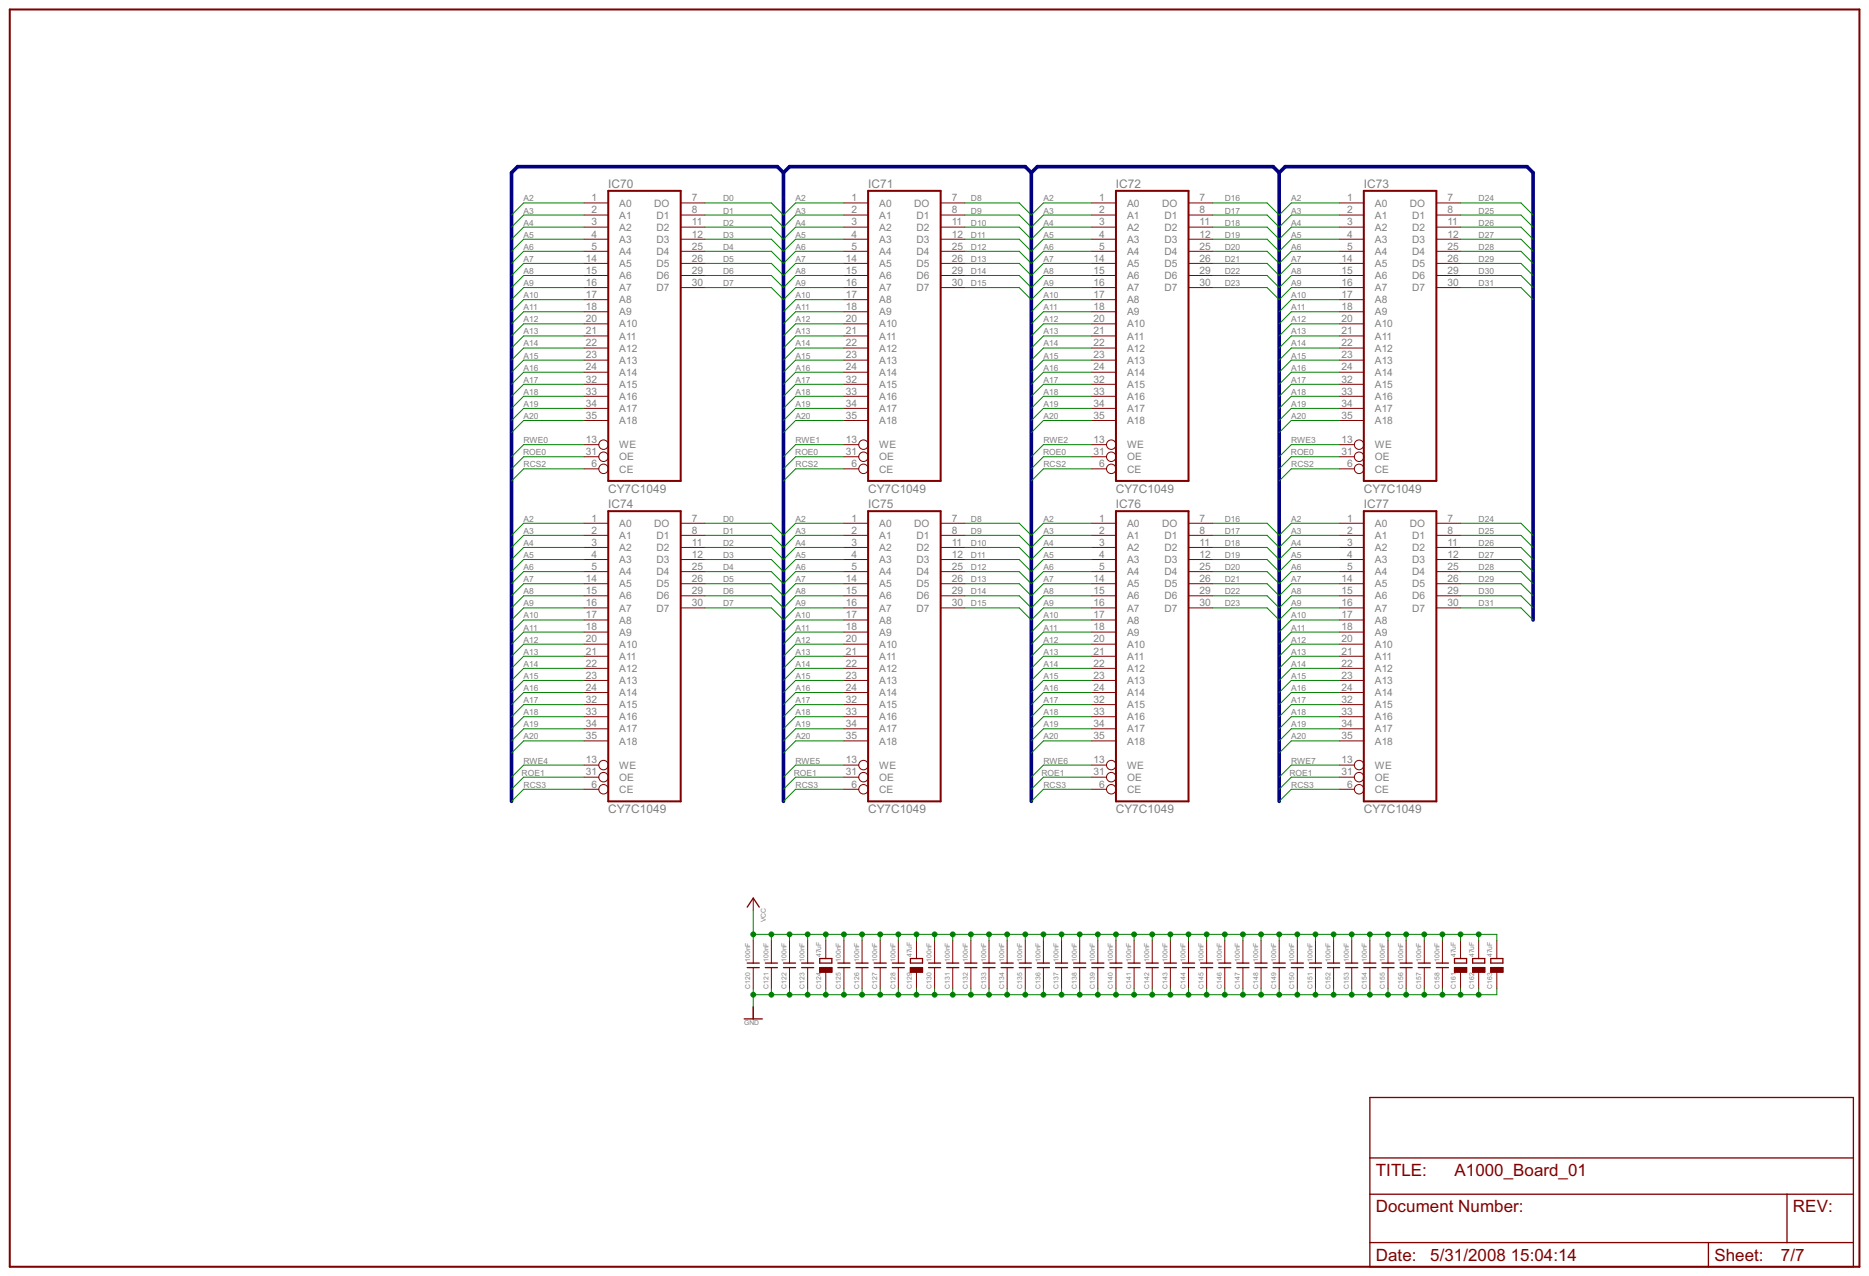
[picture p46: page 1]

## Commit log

2023-01-19 schematics and assembly drawings
2023-02-12 More docs
    [A1000_Board_04.brd, A1000_Board_04.sch, BOM_A1k_Mainboard.xls]
